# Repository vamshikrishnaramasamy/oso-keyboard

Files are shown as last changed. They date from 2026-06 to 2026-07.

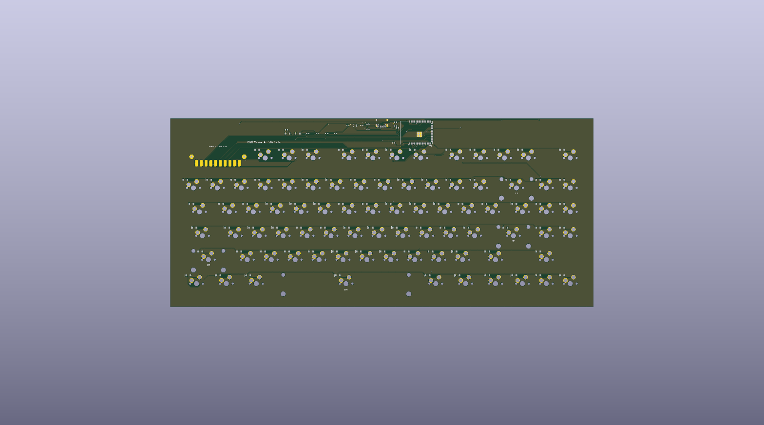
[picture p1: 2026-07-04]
hardware/kicad/oso75/renders/top-handedness-check.png

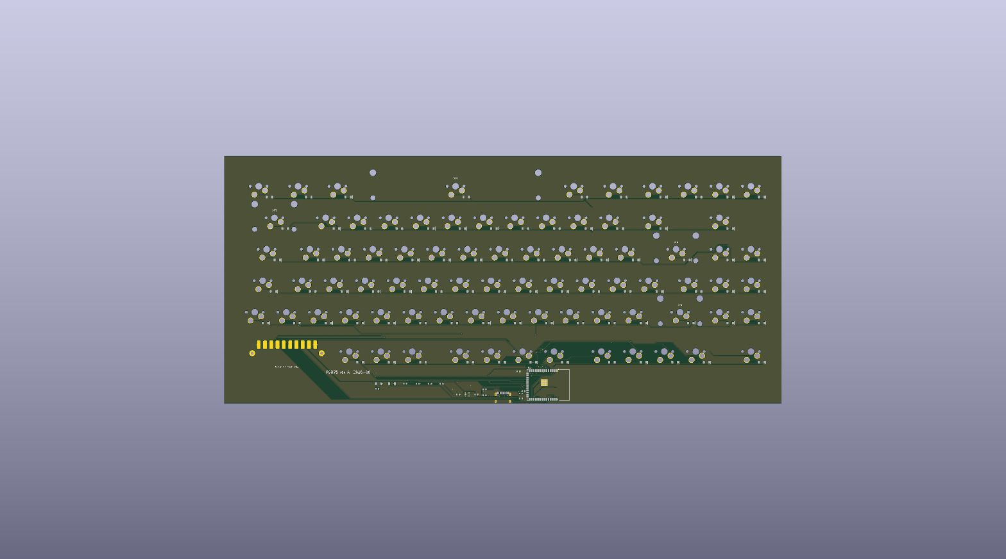
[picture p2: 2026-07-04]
hardware/kicad/oso75/renders/top-orientation-check.png

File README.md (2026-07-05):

# OSO Keyboard

Demo: https://vamshikrishnaramasamy.github.io/oso-keyboard/

Repository/README: https://github.com/vamshikrishnaramasamy/oso-keyboard

OSO Keyboard is an open-source 75% mechanical keyboard project with a custom
ESP32-S3 programmable PCB target, USB/BLE/Wi-Fi firmware plans, and parametric CAD.

Current design target:

- 82-key 75% ANSI layout with a flush hot-swappable OSO module bay
- Onboard ESP32-S3-WROOM-1U module as the main brain
- USB-C
- 10-contact programmable module dock replacing the Esc/F1 corner
- ESP-IDF/TinyUSB wired firmware target, with BLE/Wi-Fi config planned
- MX hotswap switch footprints
- PCB-mounted stabilizers
- Factory-assembled SMD diodes and ESP32-S3 support parts

The project is intentionally source-driven: edit `hardware/layout/oso75.layout.json`,
then run the generator to refresh firmware layout metadata, CAD key positions,
PCB circuit netlists, and the KiCad starting project.

## Quick Start

```sh
npm run generate
npm run validate
```

Generated CAD lives in `hardware/cad/generated/`. The KiCad project lives in
`hardware/kicad/oso75/`.

## Reviewer File Map

PCB source files:

- KiCad project: `hardware/kicad/oso75/oso75.kicad_pro`
- KiCad schematic: `hardware/kicad/oso75/oso75.kicad_sch`
- KiCad PCB: `hardware/kicad/oso75/oso75.kicad_pcb`
- Order-ready Gerbers/BOM/CPL: `hardware/kicad/oso75/fab/`
- Reviewer BOM with purchase links: `hardware/bom.csv`

CAD source and exports:

- Parametric CAD source: `hardware/cad/build123d/oso75_case.py`
- Full assembly render: `hardware/cad/build123d/oso75_preview_exploded.png`
- Full assembly STEP/GLB: `hardware/cad/build123d/oso75_assembly.step` and
  `hardware/cad/build123d/oso75_assembly.glb`
- Split case top: `hardware/cad/build123d/oso75_case_bezel.step/.stl`
- Split case bottom: `hardware/cad/build123d/oso75_case_bottom.step/.stl`
- Switch plate: `hardware/cad/build123d/oso75_plate.step/.stl`
- Module bay cover: `hardware/cad/build123d/oso75_bay_cover.step/.stl`

## Status

This is the first hardware bring-up pass. The layout, firmware skeleton, CAD
plate/case model, ESP32-S3 pin plan, PCB circuit netlists, and KiCad board
starting point are in place.

2026-06-10: a full orientation audit against the proven annovax75 reference
found the PCB was **physically mirrored** (rows y-inverted: a built board would
have had `~` on the right and Enter on the left). The board was y-flipped
(placements mirrored, every footprint rotated 180°, diodes re-seated at the
x-mirrored offset about their switch) and re-routed from scratch. KiCad 10.0.3
reports 0 DRC errors and 0 unconnected items; drill files reconcile exactly.
The CAD model was already correct and is byte-identical across the fix.

**Order only `hardware/kicad/oso75/fab/oso75_order_ready_v2_gerbers.zip`** (plus
`oso75_order_ready_v2_pos.csv` and the BOM CSVs). Anything prefixed
`STALE-MIRRORED-DO-NOT-ORDER-` is the mirrored board and must not be ordered.
See `hardware/kicad/oso75/fab/README_ORDER_READY.md`.

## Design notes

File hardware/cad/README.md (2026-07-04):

# CAD

The production case is the build123d model in `hardware/cad/build123d/`.

Generate it with:

```sh
cd hardware/cad/build123d
python3 oso75_case.py
```

Production outputs:

- `oso75_case_bottom.step/.stl`
- `oso75_case_bezel.step/.stl`
- `oso75_plate.step/.stl`
- `oso75_bay_cover.step/.stl`
- `oso75_assembly.step/.glb`

The older OpenSCAD file in `hardware/cad/generated/oso75_case_plate.scad` is
concept-only. Do not use it for final printing, CNC, or ordering.

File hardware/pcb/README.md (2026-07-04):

# PCB

OSO75 is targeting a custom onboard-ESP32-S3 PCB.

KiCad PCB source files live in `hardware/kicad/oso75/`:

- `oso75.kicad_pro` is the KiCad project.
- `oso75.kicad_sch` is the KiCad schematic.
- `oso75.kicad_pcb` is the routed PCB.
- `fab/oso75_order_ready_v2_gerbers.zip` is the order-ready Gerber package.
- `fab/oso75_order_ready_v2_pos.csv` is the order-ready CPL/position file.
- `fab/oso75_order_ready_bom_no_hotswap.csv` and
  `fab/oso75_order_ready_bom_with_hotswap.csv` are the assembly BOM options.

Generated planning/source files in this folder:

- `esp32s3-pin-plan.md` defines the matrix pins and reserved pins.
- `oso75_placement.csv` is generated placement data for switches and diodes.
- `oso75_matrix_netlist.csv` defines every switch, diode, row net, and column net.
- `oso75_esp32s3_netlist.csv` defines USB-C, power, reset, boot, debug,
  status LED, OSO module bay, and matrix pins.
- `oso75_components.csv` lists footprints, part choices, and factory/builder
  assembly intent.
- `oso75_circuit.md` explains the circuit blocks and routing rules.

The current routed PCB includes:

- ESP32-S3-WROOM-1U module support
- USB-C, ESD, boot, reset, regulator, and external antenna circuitry
- 6 x 16 matrix routing
- 82 MX hotswap sockets
- 82 SOD-123 diodes
- flush top-left OSO module bay for encoder/OLED/slider-style accessories
- PCB-mount stabilizer holes
- ESP-IDF/TinyUSB firmware metadata

Design note: the diodes are still part of the PCB, but the plan is to make them
SMD/factory-assembled so builders do not have to solder 82 tiny parts by hand.

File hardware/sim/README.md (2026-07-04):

# OSO75 ESP32-S3 Simulation

This folder is generated by `npm run simulate:esp32`.

## What runs locally

- ESP32-S3 pin-plan checks against `keyboard.json` and `oso75_esp32s3_netlist.csv`
- COL2ROW switch/diode matrix scan model for all 82 populated keys
- Boot/reset RC sanity model for EN and GPIO0
- USB/power budget estimates for AP2112K, USB 500 mA budget, and F1 500 mA hold current
- Compute/memory budget estimates for 1 kHz matrix scanning on dual-core 240 MHz ESP32-S3

## What needs external tools

Real ESP32 firmware CPU emulation needs ESP-IDF QEMU or Wokwi CLI. This machine currently has neither installed.

Espressif QEMU route:

```sh
brew install libgcrypt glib pixman sdl2 libslirp
python "$IDF_PATH/tools/idf_tools.py" install qemu-xtensa qemu-riscv32
. "$IDF_PATH/export.sh"
idf.py qemu monitor
```

Wokwi route:

```sh
wokwi-cli --timeout 10000 hardware/sim/wokwi
```

Generated Wokwi project:

- `hardware/sim/wokwi/diagram.json`
- `hardware/sim/wokwi/sketch.ino`

Note: Wokwi simulates the ESP32-S3 board and interactive buttons. The local JS sim is the source of truth for the diode matrix, power, and compute limits because it is derived directly from the repo's PCB/netlist artifacts.

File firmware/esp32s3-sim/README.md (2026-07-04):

# OSO75 ESP32-S3 Firmware Sim

This is a tiny ESP-IDF target for exercising the OSO75 ESP32-S3 pin plan on a
real ESP32-S3 build toolchain. It configures the same matrix pins as the PCB,
runs a deterministic COL2ROW matrix scan, and prints CPU/heap/timing stats.

Build it from the repo root:

```sh
npm run firmware:esp32s3:build
```

Run under Espressif QEMU when the selected IDF/QEMU target supports ESP32-S3:

```sh
npm run firmware:esp32s3:qemu
```

For full board/circuit validation, run the repo-level system sim too:

```sh
npm run simulate:esp32
npm run simulate:system:strict
```

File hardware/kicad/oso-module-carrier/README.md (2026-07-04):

# OSO Module Carrier (XIAO + Qwiic)

The first OSO module: a 54 x 25 mm carrier for the OSO75 bay that makes
the whole Qwiic/STEMMA-QT ecosystem — and optionally a whole second
ESP32 — pluggable into the keyboard. DRC-clean, fully routed
(`fab/oso_module_carrier_gerbers.zip`).

Two personalities on one PCB:

| Mode | Fit | JP1/JP2 (I2C bridge) | JP3 (5 V) |
|---|---|---|---|
| Dumb Qwiic adapter (default) | no XIAO | bridged (factory default) | open |
| Smart module | XIAO ESP32-S3 in U2/U3 | **cut** | close to power XIAO from bay |

- **Dumb mode**: the keyboard's ESP32-S3 drives any Qwiic device plugged
  into J1/J2 over the bay I2C (GPIO41/42). Zero firmware on the module.
- **Smart mode**: the XIAO owns the Qwiic (device) bus on D2/D3 and talks
  to the keyboard over the bay (link) bus on D4/D5 as an I2C peripheral;
  MOD_INT (keyboard GPIO47 / XIAO D1) is the attention line. The XIAO's
  USB-C faces up through the bay for reflashing. MOD_A/B also land on
  D0/D6 as spare link lines.

## Parts

| Ref | Part |
|---|---|
| MOD1 | ten 2.2 x 5.0 bottom pads (3.8 mm pitch) at the keyboard J3 pad positions — solder **Mill-Max 0965-0-15-20-80-14-11-0** SMT spring pins here (2.79 mm extended, ~2.5 mm at rated mid-stroke, 2 A) |
| U2/U3 | 1x7 2.54 mm SMD socket strips (XIAO ESP32-S3 seat) |
| J1/J2 | JST SH 4-pin (SM04B-SRSS-TB) = Qwiic / STEMMA-QT |
| J4 | 1x4 pin header: 3V3 / GND / MOD_A / MOD_B (encoders, raw GPIO) |
| JP1/JP2 | solder jumpers: bay I2C <-> Qwiic bus (bridged by default) |
| JP3 | solder jumper: bay fused 5 V -> XIAO 5 V pin (open by default) |
| C1/C2 | 100 nF + 10 uF 0603 on 3V3 |
| R1 | 10 k 0603, MOD_INT -> GND (module-present strap) |

Retention: Ø3.6 NPTH at ±21 mm, matching the bay's holes. ESP_EN from
the bay lands on contact 9 (unrouted on the carrier by design).

**Polarization**: the back-left corner has a 5 mm chamfer and the case
plate's bay opening a matching 2.2 mm corner key — the module physically
cannot be inserted 180° rotated (which would land 5 V/EN on the I2C
contacts). Cross-board mating is machine-verified: every contact pad's
position, size and net function is checked against the keyboard's J3 by
`verify_carrier.py` (87 checks).

## Regenerating

`generate_carrier.py` (run under KiCad's bundled python) rebuilds
placement/nets/zones from scratch; route with
`java -jar tools/freerouting/freerouting.jar -de oso_module_carrier.dsn
-do oso_module_carrier.ses -mp 10` and apply with `import_ses.py`
(pcbnew's own SES import returns False headless on this machine).
Note: regenerating discards the routed tracks and the hand-placed GND
stitch at J2 — re-run the route + import steps after.

See `docs/oso-module-spec.md` for the full bay interface contract.

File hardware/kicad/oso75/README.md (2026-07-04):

# OSO75 KiCad Project

Generated from `hardware/layout/oso75.layout.json` and the PCB circuit netlists,
then hand-finished for fabrication. **Do not re-run `scripts/generate-kicad.mjs`
over this board** - it would clobber the routing and the real footprints below.

Open `oso75.kicad_pro` in KiCad 10. The board contains:

- 82 Kailh MX hotswap switch footprints (cloned from the proven annovax75
  reference board: 3.05 mm plated contact holes, 4.0 mm center / 1.75 mm
  fixation NPTH, F.Cu SMD socket pads); Esc and F1 are replaced by the module bay
- 82 SOD-123 diode footprints, 6 x 16 COL2ROW matrix
- ESP32-S3-WROOM-1U-N16 module with native USB and an external IPEX/u.FL
  antenna connector. Do not substitute N16R8/R16V/Octal-PSRAM variants;
  GPIO35/GPIO36/GPIO37 are used by the key matrix.
- USB-C receptacle `Connector_USB:USB_C_Receptacle_HRO_TYPE-C-31-M-12` (J1)
  from the official KiCad library, shield pads solid-connected to GND
- Cherry PCB-mount stabilizer holes (3.048 / 3.988 mm NPTH) for Backspace,
  Enter, LShift (2u wires) and Space (6.25u)
- Flush top-left J3 OSO module bay with 10 contacts and two retention holes.
  Rev A is power-off swappable only; do not live-swap powered modules.
- F1 fused 5 V module rail, R10 module-present pullup, LDO, CC pulldowns,
  USB series resistors, boot/reset, strapping support
- Board outline 337.088 mm x 150.063 mm; GND pours on both copper layers
  with stitching vias

## Status: y-flipped, re-routed, DRC error-clean, ready for prototype fab review

2026-06-10 (evening): **the board was physically mirrored** - all previous
passes (including the Oracle audit) had the rows y-inverted relative to the
proven annovax75 convention, so a built board would have had `~` on the right
and Enter on the left. Fixed by mirroring every footprint placement about the
horizontal centerline (y -> 150.063 - y, each part rotated 180 deg so
y-asymmetric features land correctly; parts are physical and cannot be
mirrored), repositioning each diode at the x-mirrored offset about its own
switch (restores the proven pad clearances), and re-routing from scratch.
The KiCad canvas now reads like a normal keyboard: USB/ESP32 band and the
J3 bay at the top-left, F-row beneath, space row at the bottom.
Current package: `fab/oso75_order_ready_v2_gerbers.zip`; everything prefixed
`STALE-MIRRORED-DO-NOT-ORDER-` is the mirrored board and must not be ordered.

- Oracle review found blocking electrical issues in the previous pass; those
  are fixed in the checked-in board.
- U1 is locked to ESP32-S3-WROOM-1U-N16. Do not substitute N16R8/R16V or other
  Octal-PSRAM ESP32-S3 variants because GPIO35/GPIO36/GPIO37 are matrix columns.
- U3 is wired as:
  pin 1 VIN=VBUS, pin 2 GND, pin 3 EN=VBUS, pin 4 NC, pin 5 VOUT=+3V3.
- Added GND stitching vias to clear isolated F.Cu pour islands created by the
  regulator-area reroute.
- KiCad 10.0.3 DRC after the y-flip and re-route: 0 errors, 0 unconnected
  items, 187 library-lookup warnings only (`drc-yflip-12.json`).
- Current fab package: `fab/oso75_order_ready_v2_gerbers.zip` with
  `oso75_order_ready_v2_pos.csv`. Upload after a final Gerber-viewer check.
- All prior fab packages are the mirrored board and must not be ordered.
- Drill sanity-checked: 164x 3.05 PTH switch contacts, 164x 1.75 NPTH
  fixation, 82x 4.0 NPTH centers, 8x 3.048 + 8x 3.988 NPTH stab holes
- 2-layer, 1.6 mm FR-4, 1 oz; min track/clearance 0.2 mm, vias 0.6/0.3 mm
- Copper-to-edge clearance is set to 0.35 mm (JLCPCB/PCBWay accept >= 0.3)
  because the USB corridor cannot satisfy 0.5 mm
- J3 is exposed ENIG contact copper only: no paste, no BOM line, and no pick
  and place entry. Removable modules must provide the spring/contact side.

## How it was routed

Full-board autoroute with freerouting v2.2.4 (`tools/freerouting/freerouting.jar`):
strip all tracks, `ExportSpecctraDSN` -> `oso75_clean.dsn`, route, import
`oso75.ses`, refill zones (`post_route.py`), widen power nets where clearance
allows (`widen_power.py`), then DRC to zero. Two stubborn matrix links and the
post-layout-fix stitches were routed by the local grid-A* scripts
(`route_two.py`, `route_col9_astar.py`, `route_missing.py`); GND pour islands
got stitching vias (`stitch_islands.py`).

Gotchas discovered (kept for the next pass):

- freerouting v2.2.4 hangs at "Opening..." if the DSN contains existing
  wiring - always strip tracks and route from scratch. It can also hang
  *after* "session completed" without writing the .ses; kill and re-run.
- `pcbnew.LoadBoard` returns None unless the path ends in `.kicad_pcb`.
- The original generator switch footprints were placeholders with no real
  MX contact pads - they were replaced wholesale (see `move_sw72.py`,
  git history) and PrtSc was moved to the nav column (layout bug, 0.75u
  keycap overlap with F12).

2026-06-10: the rear electronics band was shrunk from 45 mm to 22 mm deep
(board 173.063 -> 150.063 mm tall, `rearElectronicsHeight` 36 -> 13 in the
generator/validator). U1 is now the external-antenna WROOM-1U-N16 module, so
there is no PCB antenna area on the keyboard PCB. USB/LDO/passives were
repacked, stabilizer footprints were added, and the board was fully re-routed.

Pre-route and pre-move backups: `oso75.kicad_pcb.bak`,
`oso75.kicad_pcb.pre-sw72`, `oso75.kicad_pcb.pre-shrink` (173 mm board).

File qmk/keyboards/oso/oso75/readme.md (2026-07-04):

# OSO75 Legacy QMK Layout Reference

Generated layout skeleton for the OSO75 key matrix.

The active PCB target is ESP32-S3, so production firmware is expected to move to
ESP-IDF/TinyUSB. This QMK folder remains useful as a readable layout/keymap
reference while the ESP32 firmware comes up.

```sh
qmk compile -kb oso/oso75 -km default
```

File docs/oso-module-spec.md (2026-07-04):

# OSO Module Developer Spec (Rev A)

How to build a module for the OSO75's hot-swap bay — and how to make
*any* ESP32-compatible peripheral work in it.

## The big picture

The bay is a **3.3 V I2C + GPIO dock** wired straight to the keyboard's
ESP32-S3. There is no connector on the keyboard side: the board exposes
ten ENIG gold contact pads plus two retention holes, and the **module
carries the spring contacts** (pogo pins). Anything that talks I2C — which
is most of the ESP32 peripheral ecosystem: OLEDs, sensors, IO expanders,
LED drivers, touch controllers — can be a module. Rotary encoders and
other 2-wire devices use the dedicated GPIO pair instead.

Rev A is **power-off swap only**. Unplug the keyboard before inserting or
removing a module.

## Electrical interface (J3, verified against routed copper)

| Pin | Net | ESP32-S3 side | Use |
|---:|---|---|---|
| 1 | GND | — | Ground |
| 2 | +3V3 | LDO rail | Main module power |
| 3 | VBUS_FUSED | fused 5 V | Optional, for LEDs (about 300-350 mA continuous bus-powered budget) |
| 4 | I2C_SDA | GPIO41 | I2C data |
| 5 | I2C_SCL | GPIO42 | I2C clock |
| 6 | MOD_A | GPIO39 | Encoder A / free GPIO |
| 7 | MOD_B | GPIO40 | Encoder B / free GPIO |
| 8 | MOD_INT | GPIO47 | Interrupt / module-present detect |
| 9 | ESP_EN | EN | Module-side reset (use with care) |
| 10 | GND | — | Ground |

Rules:

- **3.3 V logic only.** The ESP32-S3 is not 5 V tolerant. VBUS_FUSED may
  only feed loads (LEDs, displays' backlight boost), never logic levels.
- I2C pull-ups live on the keyboard PCB; do not add strong pull-ups on
  the module (weak 10 k extras are tolerable).
- **MOD_INT doubles as presence detect**: tie it to GND through 10 k on
  the module if you don't need an interrupt, or drive it open-drain if
  you do. Firmware reads "low at boot = module present."
- Total continuous 3V3 draw ≤ 80 mA on rev A; total continuous VBUS_FUSED draw ≤ 300-350 mA on bus power. F1 has a 500 mA hold current, but the keyboard electronics share the USB current budget.

## Mechanical interface (from the routed board, J3 at canvas 38.0, 30.5)

- Bay opening through the plate: **54.6 × 25.6 mm**; module PCB max
  **54.0 × 25.0 mm**, 1.6 mm thick, corners R ≤ 2 mm.
- Contact pads on the keyboard: ten **2.2 × 5.0 mm** pads on a **3.8 mm
  pitch**, in one row, centers at y = +5.2 mm from bay center, pad 1 at
  x = +17.1 mm running to pad 10 at x = −17.1 mm (J3 is placed rotated
  180°, so pad 1 is toward the board's left edge — copy the footprint
  `OSO75.pretty` J3 rather than re-deriving).
- Retention: two **Ø3.6 mm NPTH** at x = ±21.0 mm, y = 0 — use snap
  posts or M3 shoulder screws from the module side.
- **Polarization (required)**: chamfer the module PCB's back-left corner
  5 mm at 45°. The plate opening carries a 2.2 mm corner key there, so an
  unchamfered or wrongly-oriented module will not seat — protecting the
  I2C pins from the 5 V/EN contacts.
- Contacts: **Mill-Max 0965** SMT spring pins (2.79 mm extended, ~2.5 mm
  at rated mid-stroke, 2 A each) soldered to the module's bottom pads.
- Use **spring-loaded (pogo) contacts ≥ 1 mm travel** on the module
  underside, mirrored to the pad row. Recommended: Mill-Max 855/0965
  series or a 10-pin pogo block on 3.8 mm pitch.
- Height budget above the plate: keep the module ≤ 9 mm proud (keycap
  top is ~9.5 mm above the plate) so it doesn't dominate the board.
- When no module is fitted, the printed **bay blank**
  (`hardware/cad/build123d/oso75_bay_cover.stl`) snaps into the opening.

## Making "everything ESP32-compatible" work: the adapter module

You don't need a custom PCB per peripheral. Build (or buy the design of)
one **Qwiic/STEMMA-QT adapter module**: a 54 × 25 bay PCB with pogo
contacts on the bottom and one or two **JST-SH 4-pin Qwiic connectors**
on top, wiring 3V3/GND/SDA/SCL straight through.

**This board exists**: `hardware/kicad/oso-module-carrier/` — DRC-clean,
routed, gerbers in `fab/`. It also carries an optional XIAO ESP32-S3
socket, turning it into a self-contained smart module (own firmware, own
USB-C through the bay) with the bay I2C as the keyboard link; solder
jumpers select the mode. See its README.

That one adapter makes the entire Qwiic/STEMMA-QT catalog — hundreds of
SparkFun/Adafruit boards: OLED and e-ink displays, IMUs, environmental
sensors, GPS, NFC, keypads, haptics — plug into the keyboard with zero
soldering, because they're all 3.3 V I2C with on-board addresses, exactly
what the bay speaks. Encoder/analog peripherals use a second adapter
variant that breaks MOD_A/MOD_B out to a header.

## Firmware contract

- Bus: I2C0 on GPIO41/42 at 400 kHz, 3.3 V.
- At boot (and on MOD_INT edge), firmware scans the bus and matches known
  addresses (e.g. 0x3C SSD1306 OLED, 0x76/0x77 BME280, ...) to enable the
  right driver; unknown modules still get raw I2C via host commands.
- Encoders on MOD_A/MOD_B use the QMK encoder driver; MOD_INT is the
  shared interrupt line.
- Modules must tolerate an undriven bus (keyboard in deep sleep for BLE).

## Checklist for a new module

1. Start from the J3 footprint in `hardware/kicad/oso75/OSO75.pretty`.
2. 54 × 25 × 1.6 PCB, pogo pins mirrored to the pad row, posts at ±21.
3. 3.3 V logic, I2C device(s) with non-conflicting addresses.
4. MOD_INT strap for presence detect.
5. Stay under 80 mA continuous on 3V3 / 300-350 mA continuous on VBUS_FUSED for rev A bus power.
6. Power off to swap (Rev A).

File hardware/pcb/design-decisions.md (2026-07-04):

# PCB Design Decisions

## Decision: Custom Programmable PCB

OSO75 will use a custom PCB instead of relying on an existing YMD75-style PCB.

Reasons:

- Better open-source hardware story for Stardance.
- We control the layout, pinout, silkscreen, and future variants.
- Onboard ESP32-S3 gives native USB plus BLE/Wi-Fi for the module ecosystem.
- SMD diodes and ESP32-S3 support components can be factory assembled.
- Builders should only need to install switches, stabilizers, and case hardware.

## Decision: Top-Left Hot-Swappable Module Bay

OSO75 includes a flush top-left accessory bay as the signature customizable feature.
The bay is meant for small user-created modules that can be swapped without
redesigning the whole keyboard: a volume knob, OLED display, slider, macro
display, sensor board, or other programmable widget.

The base keyboard exposes power plus a small general-purpose interface through a
keyed 10-contact dock. The default pinout reserves I2C for displays/sensors,
two GPIOs for a rotary encoder, one interrupt/module-present pin, reset, 3.3 V,
optional fused 5 V, and ground.

Mechanical intent:

- A visible top-left recessed pocket inside the normal keyboard outline, not a
  protruding tab or full-width empty strip.
- Two small retention/mounting holes for module plates or screws.
- A 10-contact pad strip for pogo pins or a low-profile board-to-board connector.
- Modules should be independently open-source and printable/fabbable.

## Reference Backup

The YMD75v3 / 75V3 QMK hotswap PCB remains a good backup reference because it is
already programmable and has sockets/diodes populated. It is not the primary OSO75
hardware target.

## First PCB Scope

The first KiCad pass should include:

- ESP32-S3-WROOM-1U module, regulator, USB-C, ESD, boot, reset, and external antenna.
- 6 x 16 COL2ROW keyboard matrix.
- 82 MX hotswap sockets.
- 82 SOD-123 diodes.
- Top-left OSO module bay connector, 10 exposed contacts, retention holes, and mechanical keepout.
- PCB-mount stabilizer holes.
- Mounting holes aligned to the generated case.
- Clear silkscreen labels for rows, columns, and switch positions.

## Manufacturing Target

Use JLCPCB or PCBWay for the first custom PCB run. AliExpress is fine for switches,
stabilizers, screws, and other builder-installed parts, but custom PCBs are better
ordered from an actual PCB fab.

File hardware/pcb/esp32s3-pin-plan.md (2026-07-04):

# OSO75 ESP32-S3 Pin Plan

The custom PCB target uses an onboard ESP32-S3-WROOM-1U-N16 module and a 6 x 16
keyboard matrix. GPIO19/GPIO20 stay reserved for native USB so the computer plugs
directly into the ESP32-S3. Use an external 2.4 GHz IPEX/u.FL antenna for BLE/Wi-Fi.

## Matrix

| Signal | Pins |
|---|---|
| Rows | GPIO1, GPIO2, GPIO4, GPIO5, GPIO6, GPIO7 |
| Columns | GPIO8, GPIO9, GPIO10, GPIO11, GPIO12, GPIO13, GPIO14, GPIO15, GPIO16, GPIO17, GPIO18, GPIO21, GPIO35, GPIO36, GPIO37, GPIO38 |
| Diode direction | COL2ROW |
| Per-key wiring | COLn -> switch -> diode anode -> diode cathode -> ROWm |
| Diode footprint | Pad 1 is cathode/ROW side; pad 2 is anode/switch side |
| Module bay replaced positions | Esc, F1 |

GPIO35/GPIO36/GPIO37 are not available on Octal-PSRAM ESP32-S3-WROOM-1U variants,
so do not substitute an N16R8/R16V module without rerouting COL12-COL14.

## Reserved Pins

| Purpose | Pin |
|---|---|
| USB D- / D+ | GPIO19 / GPIO20 |
| Boot/download | GPIO0, pulled up; BOOT switch pulls low |
| Reset/enable | EN, pulled up; RESET switch pulls low |
| OSO module interrupt/present | GPIO47 |
| OSO module encoder/GPIO | GPIO39 / GPIO40 |
| OSO module I2C | GPIO41 / GPIO42 |
| Avoid for matrix | GPIO0, GPIO3, GPIO19, GPIO20, GPIO45, GPIO46 |

## OSO Module Bay

| Pin | Net | Use |
|---:|---|---|
| 1 | GND | Ground |
| 2 | +3V3 | Main module power |
| 3 | VBUS_FUSED | Optional 5 V input for LEDs, through fuse/current limit |
| 4 | I2C_SDA / GPIO41 | OLED/sensor data |
| 5 | I2C_SCL / GPIO42 | OLED/sensor clock |
| 6 | MOD_A / GPIO39 | Encoder A / GPIO / SPI option |
| 7 | MOD_B / GPIO40 | Encoder B / GPIO / SPI option |
| 8 | MOD_INT / GPIO47 | Interrupt, button, or module-present detect |
| 9 | ESP_EN | Optional module reset/programming signal |
| 10 | GND | Ground / shield |

Keep modules 3.3 V logic by default. Any 5 V LED module should include its own
current limiting and should not pull more than the 500 mA hold budget set by F1.
Rev A is power-off swap only. Do not insert or remove modules while powered.

## Assembly Intent

JLCPCB/PCBWay should assemble the ESP32-S3-WROOM-1U-N16 module, USB-C connector, reset/boot buttons, SMD diodes, regulator, fuse,
and passives. Do not allow N16R8/R16V/Octal-PSRAM ESP32-S3 substitutes. J3 is PCB copper only and should be excluded from factory assembly.
Kailh hotswap sockets may be factory assembled or hand-soldered, but the BOM/CPL must match that choice. The builder should only need to install switches,
stabilizers, and case hardware when sockets are factory assembled.

See `oso75_circuit.md`, `oso75_matrix_netlist.csv`, and
`oso75_esp32s3_netlist.csv` for the actual circuit nets.

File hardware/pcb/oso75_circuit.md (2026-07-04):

# OSO75 Circuit Design

This circuit pass makes the ESP32-S3 the main keyboard brain. The computer plugs
into the keyboard's USB-C port, and the ESP32-S3 enumerates as the USB HID
keyboard while also owning BLE, Wi-Fi, and the hot-swappable OSO module bay.

## Electrical Target

- MCU: onboard ESP32-S3-WROOM-1U-N16 module with external IPEX/u.FL antenna connector. Do not substitute N16R8/R16V/Octal-PSRAM variants.
- Firmware: ESP-IDF + TinyUSB first; BLE/Wi-Fi config after wired USB is stable.
- Matrix: 6 rows x 16 columns, 82 populated switch positions.
- Module bay replaces: Esc, F1.
- Diode direction: `COL2ROW`.
- Builder soldering target: switches/stabilizers only. SMD diodes and controller
  support parts should be factory assembled.

## Switch Matrix

Each key uses this net order:

```text
COLn -> switch -> diode anode -> diode cathode -> ROWm
```

The SOD-123 diode footprint intentionally uses pad 1 as the cathode/ROW-side pad.
The cathode band and `K` mark face the ROW net on the assembly drawing.

### Rows

| Net | ESP32-S3 pin | Populated keys |
|---|---|---:|
| ROW0 | U1 GPIO1 | 12 switches |
| ROW1 | U1 GPIO2 | 16 switches |
| ROW2 | U1 GPIO4 | 16 switches |
| ROW3 | U1 GPIO5 | 15 switches |
| ROW4 | U1 GPIO6 | 13 switches |
| ROW5 | U1 GPIO7 | 10 switches |

### Columns

| Net | ESP32-S3 pin | Populated keys |
|---|---|---:|
| COL0 | U1 GPIO8 | 5 switches |
| COL1 | U1 GPIO9 | 5 switches |
| COL2 | U1 GPIO10 | 6 switches |
| COL3 | U1 GPIO11 | 5 switches |
| COL4 | U1 GPIO12 | 5 switches |
| COL5 | U1 GPIO13 | 5 switches |
| COL6 | U1 GPIO14 | 6 switches |
| COL7 | U1 GPIO15 | 5 switches |
| COL8 | U1 GPIO16 | 5 switches |
| COL9 | U1 GPIO17 | 6 switches |
| COL10 | U1 GPIO18 | 6 switches |
| COL11 | U1 GPIO21 | 6 switches |
| COL12 | U1 GPIO35 | 4 switches |
| COL13 | U1 GPIO36 | 4 switches |
| COL14 | U1 GPIO37 | 5 switches |
| COL15 | U1 GPIO38 | 4 switches |

GPIO35/GPIO36/GPIO37 are only valid because the target module is ESP32-S3-WROOM-1U-N16,
not an Octal-PSRAM N16R8/R16V module.

## USB-C And Power

- J1 is a USB-C receptacle wired as a USB 2.0 device.
- CC1 and CC2 each get a 5.1k pulldown to GND.
- D+ and D- route from J1 through 27R series resistors to ESP32-S3 GPIO20/GPIO19 native USB.
- USB ESD protection is not fitted in this routed rev; add a USBLC6-class part during the next USB reroute instead of dropping it into the current crowded fanout.
- VBUS feeds U3, a 3.3 V LDO such as AP2112K-3.3.
- AP2112K pinout: pin 1 VIN=VBUS, pin 2 GND, pin 3 EN=VBUS, pin 4 NC, pin 5 VOUT=+3V3.
- F1 is a Littelfuse 0603L050SLYR 0603 PPTC fuse. It creates a current-limited
  VBUS_FUSED rail for optional 5 V module loads.
- C1 and C2 are 10uF 10V 0603 bulk capacitors at LDO input/output.

## ESP32-S3 Support

- U1 is an ESP32-S3-WROOM-1U module, so flash, crystal, RF matching, and the IPEX antenna connector are inside the module.
- Fit a compatible 2.4 GHz IPEX/u.FL antenna if BLE/Wi-Fi will be used. Wired USB keyboard mode works without the antenna.
- SW_RESET pulls EN low.
- C_EN is 1uF from ESP_EN to GND for the ESP32-S3 EN reset delay.
- SW_BOOT pulls GPIO0 low for ROM download mode.
- GPIO47 routes to the OSO bay as module-present or interrupt.
- GPIO39/GPIO40 route to the OSO bay for encoder/GPIO use.
- GPIO41/GPIO42 route to the OSO bay for I2C OLED/sensor modules.
- GPIO19/GPIO20 are reserved for USB D-/D+ and are not used by the switch matrix.
- Avoid GPIO0, GPIO3, GPIO45, and GPIO46 for ordinary matrix wiring because they affect boot/strapping.

## OSO Module Bay

The keyboard PCB side is exposed ENIG copper pads plus two retention holes, not a
factory-assembled pogo or mezzanine connector. Put the spring contacts on the
removable module side. Rev A is **power-off swap only**: unplug the keyboard
before inserting or removing modules.

| Pin | Net | Use |
|---:|---|---|
| 1 | GND | Ground |
| 2 | +3V3 | Main module power |
| 3 | VBUS_FUSED | Optional 5 V for LEDs/modules |
| 4 | I2C_SDA | OLED/sensor data |
| 5 | I2C_SCL | OLED/sensor clock |
| 6 | MOD_A | Encoder A / GPIO |
| 7 | MOD_B | Encoder B / GPIO |
| 8 | MOD_INT | Interrupt or module-present detect |
| 9 | ESP_EN | Optional module reset/programming signal |
| 10 | GND | Ground |

Keep modules 3.3 V logic by default. Any 5 V LED module should include its own
current limiting and should not pull more than the 500 mA hold budget set by F1.
Do not live-swap rev A modules. A later live-swap revision needs ground-first
contact, keyboard-side signal resistors, GPIO ESD protection, and 3.3 V current
limiting/load switching.

Fab note: J3 is intentional exposed contact copper. Do not place a component, do
not paste/stencil the pads, and use ENIG at minimum; choose hard gold if modules
will be swapped often.

## Layout Rules

- Put J1, R3, and R4 close together at the rear USB port.
- Keep D+/D- short, parallel, and away from the switch matrix where possible.
- Keep the WROOM-1U module body clear of switch/stabilizer mechanical courtyards; wireless RF depends on the external antenna and cable placement, not a PCB antenna area.
- Place 10uF bulk and 100nF local decoupling near the module 3V3 pins.
- Route rows horizontally and columns vertically where possible.
- Put the SOD-123 diode near each hotswap socket; cathode stripe/pad 1 goes to the row net.
- Keep the top-left bay clear for J3, retention holes, and module mechanical fit.
- Use a solid ground fill on both layers, stitched around USB and MCU.

## Generated Files

- `oso75_matrix_netlist.csv`: one switch/diode row per key.
- `oso75_esp32s3_netlist.csv`: MCU module, USB, power, buttons, module bay, and headers.
- `oso75_components.csv`: component list with footprints and assembly intent.
- `oso75_placement.csv`: switch and diode coordinates from the keyboard layout.

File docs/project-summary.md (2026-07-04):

# OSO Keyboard Project Summary

Last updated: 2026-06-09

## Goal

OSO Keyboard is an open-source 75% mechanical keyboard project for Stardance. The current direction is a custom keyboard with an onboard ESP32-S3, USB-C, a real 75% ANSI-style layout, and a hot-swappable programmable module bay in the top-left corner for user-made add-ons like a volume knob, OLED screen, slider, macro pad, or LED widget.

## Current Public Links

- GitHub repository: https://github.com/vamshikrishnaramasamy/oso-keyboard
- Web demo / CAD viewer: https://vamshikrishnaramasamy.github.io/oso-keyboard/

## What We Built So Far

### Repo Structure

The project is now source-driven. The main layout source is:

- `hardware/layout/oso75.layout.json`

Generated outputs are produced with:

```sh
npm run generate
npm run validate
```

The generator currently creates or updates:

- CAD files in `hardware/cad/generated/`
- PCB placement/netlist data in `hardware/pcb/`
- KiCad project files in `hardware/kicad/oso75/`
- QMK-style firmware metadata in `qmk/keyboards/oso/oso75/`
- Web viewer assets in `web/public/models/`

### Web CAD Viewer

We built a Three.js-based browser viewer for the keyboard CAD. It can show the generated case/plate model in the browser and was improved several times because the first OpenSCAD-style render made it hard to see the switch holes.

Improvements made:

- Better lighting and material shading
- More visible switch cutout depth
- More useful camera/orbit controls
- CAD asset sync into the web viewer
- Generated STL support for the browser model

The viewer runs locally with:

```sh
npm run viewer
```

### Keyboard CAD

We created a parametric OpenSCAD model for the 75% keyboard case and plate.

Current CAD files include:

- `hardware/cad/generated/oso75_case_plate.scad`
- `hardware/cad/generated/oso75_case_plate.stl`
- `hardware/cad/generated/oso75_fit_report.json`
- `hardware/cad/generated/oso75_pcb_fit.png`

Major CAD revisions:

- Reworked the layout so it actually resembles a 75% keyboard.
- Mirrored the board after the left/right orientation was wrong.
- Moved the arrow/navigation cluster to the correct side.
- Added a top-left OSO hot-swappable module bay.
- Revised the module bay so it is flush with the case instead of awkwardly sticking out.
- Moved the USB-C opening multiple times, ending with a centered side placement that avoids the module bay better.
- Added a PCB fit visualization to check that the board and case line up.

### OSO Module Bay

The module bay is the main "cool part" of the keyboard. The idea is that the keyboard has a standard top-left dock where people can make their own programmable gadgets.

Planned module examples:

- Rotary volume knob
- OLED status display
- Slider module
- Macro module
- LED/status widget

Current electrical bay concept:

- 10-contact dock
- 3.3V
- Fused VBUS
- GND
- I2C SDA/SCL
- Two GPIO/encoder pins
- Interrupt/present pin
- ESP reset/enable access

The bay replaces the Esc/F1 corner area in the current layout.

## PCB and Electronics

### Main Controller Decision

We switched the design from a generic keyboard controller approach to a custom PCB centered around:

- ESP32-S3-WROOM-1U-N16

Reasoning:

- Native USB support, so the computer can plug directly into the ESP32-S3 over USB-C.
- Wi-Fi and BLE available for future customization.
- More flexible than a basic wired-only microcontroller.
- Good fit for a programmable open-source keyboard with add-on modules.

Important design note: the keyboard should enumerate as a USB HID keyboard through the ESP32-S3 native USB pins, not through a separate USB-to-serial chip.

### Pin Plan

The current matrix target is:

- 6 rows
- 16 columns
- 82 key positions
- COL2ROW diode direction

Current planned ESP32-S3 pins:

- Rows: GPIO1, GPIO2, GPIO4, GPIO5, GPIO6, GPIO7
- Columns: GPIO8, GPIO9, GPIO10, GPIO11, GPIO12, GPIO13, GPIO14, GPIO15, GPIO16, GPIO17, GPIO18, GPIO21, GPIO35, GPIO36, GPIO37, GPIO38
- Native USB: GPIO19 / GPIO20
- Module I2C: GPIO41 / GPIO42
- Module GPIO/encoder: GPIO39 / GPIO40
- Module interrupt/present: GPIO47

Details live in:

- `hardware/pcb/esp32s3-pin-plan.md`

### PCB Files

Current PCB-related files include:

- `hardware/pcb/README.md`
- `hardware/pcb/esp32s3-pin-plan.md`
- `hardware/pcb/oso75_circuit.md`
- `hardware/pcb/oso75_components.csv`
- `hardware/pcb/oso75_matrix_netlist.csv`
- `hardware/pcb/oso75_esp32s3_netlist.csv`
- `hardware/pcb/oso75_placement.csv`
- `hardware/kicad/oso75/oso75.kicad_pro`
- `hardware/kicad/oso75/oso75.kicad_sch`
- `hardware/kicad/oso75/oso75.kicad_pcb`

### KiCad Status

KiCad is installed locally and the project has a generated KiCad starting point. The KiCad CLI was found at:

```sh
/Applications/KiCad/KiCad.app/Contents/MacOS/kicad-cli
```

KiCad version checked:

```text
10.0.3
```

We generated a board with:

- ESP32-S3-WROOM-1 footprint
- USB-C connector area
- Matrix switch/diode positions
- Module bay footprint area
- Initial board outline matching the CAD intent
- Render/export support

**Update 2026-06-09: the PCB was routed, but later review found blocker bugs.**

- All 82 generator placeholder switch footprints were replaced with the proven Kailh MX hotswap footprint from the annovax75 reference (real 3.05 mm plated contact holes + socket pads); the USB-C connector was replaced with the official KiCad library `USB_C_Receptacle_HRO_TYPE-C-31-M-12`.
- PrtSc was moved to the right nav column (layout bug: it overlapped F12 by 0.25u). Fixed in `oso75.layout.json` and on the board.
- Cherry PCB-mount stabilizer holes added (Backspace, Enter, LShift, Space).
- ESP32-S3 external antenna rule area added on both copper layers.
- Full board routed (freerouting + local A* scripts), GND pours both layers with stitching vias.
- Previous DRC/fab exports are stale after the Oracle review.
- Important: normal `npm run generate` no longer runs `scripts/generate-kicad.mjs`;
  the KiCad starter generator is explicit as `npm run generate:kicad:starter`.

**Update 2026-06-10: rear electronics band shrunk 173 -> 150 mm.**

- The back band behind the F-row was 45 mm deep; cut to 22 mm (`rearElectronicsHeight` 36 -> 13 in `scripts/generate.mjs`/`validate.mjs`).
- ESP32-S3 rotated horizontal with the antenna facing east into a fresh both-layer keepout; USB-C, LDO, fuse, buttons, and passives repacked into the band.
- Whole board was re-routed (freerouting + A* finishing), but the Oracle audit
  later found ESP32 module and regulator pinout blockers.
- Case/plate CAD regenerated to the same 150.063 mm height.

**Update 2026-06-10: Oracle PCB bugs fixed.**

- U1 retargeted from ESP32-S3-WROOM-1U-N16R8 to ESP32-S3-WROOM-1U-N16 so
  GPIO35/GPIO36/GPIO37 can legally remain COL12-COL14.
- U3 AP2112K pad nets and local copper fixed: VIN/EN on VBUS, NC floating,
  VOUT on +3V3.
- `npm run generate` no longer runs `scripts/generate-kicad.mjs`; KiCad starter
  regeneration is explicit via `npm run generate:kicad:starter`.
- KiCad 10.0.3 DRC after refill: 0 errors, 0 unconnected items, 276 warnings.

## Hardware Parts Direction

We moved toward factory assembly for the annoying tiny parts, especially the diodes, so the builder does not have to hand-solder 82 SMD diodes.

Planned factory-assembled PCB parts:

- ESP32-S3-WROOM-1U-N16
- USB-C receptacle
- SMD matrix diodes
- Reset and boot buttons
- Voltage regulator / power support
- USB-C CC resistors
- Module bay dock
- Protection/current-limiting parts
- Required passives

Builder-installed parts:

- MX switches
- Keycaps
- Stabilizers
- Case/plate hardware
- Optional module bay accessories
- USB-C cable

Parts notes live in:

- `hardware/bom.md`
- `hardware/pcb/oso75_components.csv`

## PCB Manufacturing / Quote Work

We looked at PCB fabrication options and started filling PCBWay quote settings.

Final board dimensions for quoting (from Edge.Cuts):

- 337.088 mm x 150.063 mm

Settings to use when re-quoting (the earlier ~$170 quote was for 4 layers at 320x135 - re-quote!):

- **2 layers** (the routed board is 2-layer)
- FR-4
- 1.6 mm thickness
- 1 oz copper
- Lead-free HASL surface finish
- Green solder mask
- White silkscreen
- No stencil
- Min track/clearance 0.2 mm, min via 0.6/0.3 mm, copper-to-edge 0.35 mm

PCBWay showed a high prototype price for 5 boards, roughly around:

- PCB cost: about $140
- Shipping: about $30
- Total: about $170

Important: no final Gerbers should be ordered yet. The current KiCad board still needs routing and DRC cleanup.

Also important: during quote testing, an unpaid PCBWay draft/cart item was created without uploaded Gerbers. It should not be treated as a real production order.

## Existing 75% Board Reference

We pulled in an existing 75% keyboard PCB/CAD reference to compare against our dimensions, layout, and fit:

- `references/existing-75-cad/annovax75/PCB/keyboard.kicad_pcb`

We used it as a sanity check for:

- Overall 75% proportions
- Layout orientation
- USB placement concerns
- Case/PCB fit expectations

## Firmware Direction

The repo currently has a QMK-style skeleton, but the ESP32-S3 direction means the real firmware path should likely move toward:

- ESP-IDF
- TinyUSB HID keyboard support
- Matrix scanner
- Module bay driver layer
- Optional BLE support later
- Optional Wi-Fi configuration layer later

Current firmware skeleton:

- `qmk/keyboards/oso/oso75/`

This is useful as metadata/reference, but the final ESP32-S3 firmware still needs to be implemented and compiled.

## Stardance / Hackatime Work

We also worked through Stardance setup questions around:

- How Hackatime tracks activity
- How Stardance uses logged project time
- Why the account still showed 0 stardust before linked/eligible project time was visible
- How to send Hackatime heartbeats from the CLI
- How to install/setup the Hackatime extension in Antigravity/VS Code

Key rule learned: Hackatime counts editor/activity heartbeats from actual working tools. It should not be spoofed or artificially inflated, but legitimate coding/research/documentation work in the project can be tracked if Hackatime is configured and heartbeats are being sent correctly.

## Slack Bot / Nest Side Quest

There was also a separate Stardance mission side quest for a Slack bot.

What happened:

- Created/edited a Stardance project for a Slack bot.
- Tried to get a Slack slash command working.
- Hit `invalid_service` errors.
- Realized the mission expected deployment on Hack Club Nest.
- Applied for Nest.
- Nest account was approved.

Nest login info from the approval email:

```sh
ssh vamshikrishnaramasamy@hackclub.app
```

That work is mostly separate from OSO Keyboard, but it happened during the same Stardance setup period.

## Current Status

Working / useful now:

- Repo structure
- Source layout
- Generators
- Validation script
- CAD model
- Web CAD viewer
- KiCad project starting point
- ESP32-S3 pin plan
- BOM direction
- PCB quote research
- Existing board reference comparison

Done since (2026-06-09):

- Final KiCad routing (freerouting + scripted A* finishing)
- Fresh DRC after Oracle fixes
- Real switch/USB-C footprints, stabilizer holes, external antenna
- Gerber/drill/position export (`hardware/kicad/oso75/fab/`)

Not done yet:

- PCB order
- ESP32-S3 firmware compile
- Real hardware test
- Module bay electrical validation
- Final case/plate mechanical validation

## Next Steps

Recommended next steps:

1. Finish KiCad routing manually or with a controlled autorouter pass.
2. Run KiCad ERC and DRC until there are no real electrical/manufacturing errors.
3. Re-check USB-C placement against the module bay and case wall.
4. Generate final Gerbers and drill files.
5. Upload Gerbers to JLCPCB and PCBWay for real quotes.
6. Decide whether the first prototype should be bare PCB only or PCB assembly.
7. Build a minimal ESP-IDF/TinyUSB keyboard firmware.
8. Test the CAD model with a real 75% plate/PCB outline before ordering.
9. Make a Stardance devlog with screenshots of the CAD viewer, PCB, and design decisions.

## Honest Risk List

- A custom ESP32-S3 keyboard PCB is possible, but it is more complex than using an existing keyboard MCU board.
- USB-C routing and ESP32-S3 boot/reset/power circuitry need careful KiCad verification.
- The OSO module bay is custom and needs mechanical/electrical testing before anyone should rely on it.
- The current PCB should be treated as an engineering prototype, not a finished production design.
- Ordering before DRC/ERC cleanup could waste money.

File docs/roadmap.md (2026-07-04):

# Roadmap

## Done

- 82-key 75% layout source with the OSO module bay replacing Esc/F1.
- Generator for firmware metadata, CAD, BOM, and placement data.
- Legacy QMK layout skeleton.
- ESP32-S3 matrix pin plan.
- OpenSCAD tray case and switch plate.
- OpenSCAD render sanity check.

## Next

- Build KiCad schematic from the ESP32-S3-WROOM module design.
- Import switch/diode placement into KiCad PCB.
- Add USB-C opening and mounting boss alignment to CAD.
- Create a VIA JSON definition.
- Make first wired USB HID firmware compile with ESP-IDF/TinyUSB.
- Export Gerbers and assembly files.

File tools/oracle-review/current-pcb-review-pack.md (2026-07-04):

# OSO75 current PCB extracted review pack

Generated from actual `hardware/kicad/oso75/oso75.kicad_pcb` after Oracle fixes. Units mm.

## DRC summary

KiCad 10.0.3; violations 276; unconnected 0.

```json
{
  "via_dangling": 2,
  "courtyards_overlap": 2,
  "npth_inside_courtyard": 2,
  "pth_inside_courtyard": 1,
  "silk_edge_clearance": 2,
  "lib_footprint_issues": 184,
  "lib_footprint_mismatch": 1,
  "silk_over_copper": 82
}
```

## Board-critical footprints

### C1 10uF OSO75:C_0603 at 152.5,144.5 rot 0
- pad 1: at -0.8 0; size 0.8 0.9; drill ; layers "F.Cu" "F.Mask" "F.Paste"; net VBUS; zone_connect 
- pad 2: at 0.8 0; size 0.8 0.9; drill ; layers "F.Cu" "F.Mask" "F.Paste"; net GND; zone_connect 2

### C2 10uF OSO75:C_0603 at 141.5,144.5 rot 0
- pad 1: at -0.8 0; size 0.8 0.9; drill ; layers "F.Cu" "F.Mask" "F.Paste"; net +3V3; zone_connect 
- pad 2: at 0.8 0; size 0.8 0.9; drill ; layers "F.Cu" "F.Mask" "F.Paste"; net GND; zone_connect 

### C3 100nF OSO75:C_0603 at 178,130.5 rot 0
- pad 1: at -0.8 0; size 0.8 0.9; drill ; layers "F.Cu" "F.Mask" "F.Paste"; net +3V3; zone_connect 
- pad 2: at 0.8 0; size 0.8 0.9; drill ; layers "F.Cu" "F.Mask" "F.Paste"; net GND; zone_connect 2

### C4 100nF OSO75:C_0603 at 181,142.5 rot 0
- pad 1: at -0.8 0; size 0.8 0.9; drill ; layers "F.Cu" "F.Mask" "F.Paste"; net +3V3; zone_connect 
- pad 2: at 0.8 0; size 0.8 0.9; drill ; layers "F.Cu" "F.Mask" "F.Paste"; net GND; zone_connect 2

### F1 500mA OSO75:Polyfuse_1206 at 117,138 rot 0
- pad 1: at -0.8 0; size 0.8 0.9; drill ; layers "F.Cu" "F.Mask" "F.Paste"; net VBUS; zone_connect 
- pad 2: at 0.8 0; size 0.8 0.9; drill ; layers "F.Cu" "F.Mask" "F.Paste"; net VBUS_FUSED; zone_connect 

### J1 USB_C_HRO_TYPE-C-31-M-12 Connector_USB:USB_C_Receptacle_HRO_TYPE-C-31-M-12 at 168.54,147.66 rot 0
- pad A1: at -3.25 -4.045; size 0.6 1.45; drill ; layers "F.Cu" "F.Mask" "F.Paste"; net GND; zone_connect 2
- pad A4: at -2.45 -4.045; size 0.6 1.45; drill ; layers "F.Cu" "F.Mask" "F.Paste"; net VBUS; zone_connect 
- pad A5: at -1.25 -4.045; size 0.3 1.45; drill ; layers "F.Cu" "F.Mask" "F.Paste"; net USB_CC1; zone_connect 
- pad A6: at -0.25 -4.045; size 0.3 1.45; drill ; layers "F.Cu" "F.Mask" "F.Paste"; net USB_DP_CONN; zone_connect 
- pad A7: at 0.25 -4.045; size 0.3 1.45; drill ; layers "F.Cu" "F.Mask" "F.Paste"; net USB_DM_CONN; zone_connect 
- pad A8: at 1.25 -4.045; size 0.3 1.45; drill ; layers "F.Cu" "F.Mask" "F.Paste"; net ; zone_connect 
- pad A9: at 2.45 -4.045; size 0.6 1.45; drill ; layers "F.Cu" "F.Mask" "F.Paste"; net VBUS; zone_connect 
- pad A12: at 3.25 -4.045; size 0.6 1.45; drill ; layers "F.Cu" "F.Mask" "F.Paste"; net GND; zone_connect 2
- pad B1: at 3.25 -4.045; size 0.6 1.45; drill ; layers "F.Cu" "F.Mask" "F.Paste"; net GND; zone_connect 2
- pad B4: at 2.45 -4.045; size 0.6 1.45; drill ; layers "F.Cu" "F.Mask" "F.Paste"; net VBUS; zone_connect 
- pad B5: at 1.75 -4.045; size 0.3 1.45; drill ; layers "F.Cu" "F.Mask" "F.Paste"; net USB_CC2; zone_connect 
- pad B6: at 0.75 -4.045; size 0.3 1.45; drill ; layers "F.Cu" "F.Mask" "F.Paste"; net USB_DP_CONN; zone_connect 
- pad B7: at -0.75 -4.045; size 0.3 1.45; drill ; layers "F.Cu" "F.Mask" "F.Paste"; net USB_DM_CONN; zone_connect 
- pad B8: at -1.75 -4.045; size 0.3 1.45; drill ; layers "F.Cu" "F.Mask" "F.Paste"; net ; zone_connect 
- pad B9: at -2.45 -4.045; size 0.6 1.45; drill ; layers "F.Cu" "F.Mask" "F.Paste"; net VBUS; zone_connect 
- pad B12: at -3.25 -4.045; size 0.6 1.45; drill ; layers "F.Cu" "F.Mask" "F.Paste"; net GND; zone_connect 2
- pad SH: at -4.32 -3.13; size 1 2.1; drill oval 0.6 1.7; layers "*.Cu" "*.Mask"; net GND; zone_connect 2
- pad SH: at -4.32 1.05; size 1 1.6; drill oval 0.6 1.2; layers "*.Cu" "*.Mask"; net GND; zone_connect 2
- pad SH: at 4.32 -3.13; size 1 2.1; drill oval 0.6 1.7; layers "*.Cu" "*.Mask"; net GND; zone_connect 2
- pad SH: at 4.32 1.05; size 1 1.6; drill oval 0.6 1.2; layers "*.Cu" "*.Mask"; net GND; zone_connect 2

### J3 OSO_Module_Bay_10 OSO75:OSO_Module_Bay_10 at 38,119.563 rot 0
- pad 1: at -17.1 -5.2; size 2.2 5; drill ; layers "F.Cu" "F.Mask" "F.Paste"; net GND; zone_connect 
- pad 2: at -13.3 -5.2; size 2.2 5; drill ; layers "F.Cu" "F.Mask" "F.Paste"; net +3V3; zone_connect 
- pad 3: at -9.5 -5.2; size 2.2 5; drill ; layers "F.Cu" "F.Mask" "F.Paste"; net VBUS_FUSED; zone_connect 
- pad 4: at -5.7 -5.2; size 2.2 5; drill ; layers "F.Cu" "F.Mask" "F.Paste"; net I2C_SDA; zone_connect 
- pad 5: at -1.9 -5.2; size 2.2 5; drill ; layers "F.Cu" "F.Mask" "F.Paste"; net I2C_SCL; zone_connect 
- pad 6: at 1.9 -5.2; size 2.2 5; drill ; layers "F.Cu" "F.Mask" "F.Paste"; net MOD_A; zone_connect 
- pad 7: at 5.7 -5.2; size 2.2 5; drill ; layers "F.Cu" "F.Mask" "F.Paste"; net MOD_B; zone_connect 
- pad 8: at 9.5 -5.2; size 2.2 5; drill ; layers "F.Cu" "F.Mask" "F.Paste"; net MOD_INT; zone_connect 
- pad 9: at 13.3 -5.2; size 2.2 5; drill ; layers "F.Cu" "F.Mask" "F.Paste"; net ESP_EN; zone_connect 
- pad 10: at 17.1 -5.2; size 2.2 5; drill ; layers "F.Cu" "F.Mask" "F.Paste"; net GND; zone_connect 

### R1 5.1k OSO75:R_0603 at 179.5,147 rot 0
- pad 1: at -0.8 0; size 0.8 0.9; drill ; layers "F.Cu" "F.Mask" "F.Paste"; net USB_CC1; zone_connect 
- pad 2: at 0.8 0; size 0.8 0.9; drill ; layers "F.Cu" "F.Mask" "F.Paste"; net GND; zone_connect 

### R2 5.1k OSO75:R_0603 at 179.5,144 rot 0
- pad 1: at -0.8 0; size 0.8 0.9; drill ; layers "F.Cu" "F.Mask" "F.Paste"; net USB_CC2; zone_connect 
- pad 2: at 0.8 0; size 0.8 0.9; drill ; layers "F.Cu" "F.Mask" "F.Paste"; net GND; zone_connect 

### R3 27R OSO75:R_0603 at 157.5,145 rot 0
- pad 1: at -0.8 0; size 0.8 0.9; drill ; layers "F.Cu" "F.Mask" "F.Paste"; net USB_DP_CONN; zone_connect 
- pad 2: at 0.8 0; size 0.8 0.9; drill ; layers "F.Cu" "F.Mask" "F.Paste"; net USB_DP; zone_connect 

### R4 27R OSO75:R_0603 at 157.5,141.5 rot 0
- pad 1: at -0.8 0; size 0.8 0.9; drill ; layers "F.Cu" "F.Mask" "F.Paste"; net USB_DM_CONN; zone_connect 
- pad 2: at 0.8 0; size 0.8 0.9; drill ; layers "F.Cu" "F.Mask" "F.Paste"; net USB_DM; zone_connect 

### R5 10k OSO75:R_0603 at 124.5,138 rot 0
- pad 1: at -0.8 0; size 0.8 0.9; drill ; layers "F.Cu" "F.Mask" "F.Paste"; net ESP_EN; zone_connect 
- pad 2: at 0.8 0; size 0.8 0.9; drill ; layers "F.Cu" "F.Mask" "F.Paste"; net +3V3; zone_connect 

### R6 10k OSO75:R_0603 at 131.5,138 rot 0
- pad 1: at -0.8 0; size 0.8 0.9; drill ; layers "F.Cu" "F.Mask" "F.Paste"; net BOOT_IO0; zone_connect 
- pad 2: at 0.8 0; size 0.8 0.9; drill ; layers "F.Cu" "F.Mask" "F.Paste"; net +3V3; zone_connect 

### R10 10k OSO75:R_0603 at 109.5,138 rot 0
- pad 1: at -0.8 0; size 0.8 0.9; drill ; layers "F.Cu" "F.Mask" "F.Paste"; net MOD_INT; zone_connect 
- pad 2: at 0.8 0; size 0.8 0.9; drill ; layers "F.Cu" "F.Mask" "F.Paste"; net +3V3; zone_connect 

### SW_BOOT BOOT OSO75:SW_Tactile_4x3 at 101.5,138 rot 0
- pad 1: at -1.7 0; size 1.2 1.7; drill ; layers "F.Cu" "F.Mask" "F.Paste"; net BOOT_IO0; zone_connect 
- pad 2: at 1.7 0; size 1.2 1.7; drill ; layers "F.Cu" "F.Mask" "F.Paste"; net GND; zone_connect 

### SW_RESET RESET OSO75:SW_Tactile_4x3 at 93.5,138 rot 0
- pad 1: at -1.7 0; size 1.2 1.7; drill ; layers "F.Cu" "F.Mask" "F.Paste"; net ESP_EN; zone_connect 
- pad 2: at 1.7 0; size 1.2 1.7; drill ; layers "F.Cu" "F.Mask" "F.Paste"; net GND; zone_connect 

### U1 ESP32-S3-WROOM-1-N16 RF_Module:ESP32-S3-WROOM-1 at 196,138.8 rot -90
- pad 1: at -8.75 -5.26 270; size 1.5 0.9; drill ; layers "F.Cu" "F.Mask" "F.Paste"; net GND; zone_connect 2
- pad 2: at -8.75 -3.99 270; size 1.5 0.9; drill ; layers "F.Cu" "F.Mask" "F.Paste"; net +3V3; zone_connect 
- pad 3: at -8.75 -2.72 270; size 1.5 0.9; drill ; layers "F.Cu" "F.Mask" "F.Paste"; net ESP_EN; zone_connect 
- pad 4: at -8.75 -1.45 270; size 1.5 0.9; drill ; layers "F.Cu" "F.Mask" "F.Paste"; net ROW2; zone_connect 
- pad 5: at -8.75 -0.18 270; size 1.5 0.9; drill ; layers "F.Cu" "F.Mask" "F.Paste"; net ROW3; zone_connect 
- pad 6: at -8.75 1.09 270; size 1.5 0.9; drill ; layers "F.Cu" "F.Mask" "F.Paste"; net ROW4; zone_connect 
- pad 7: at -8.75 2.36 270; size 1.5 0.9; drill ; layers "F.Cu" "F.Mask" "F.Paste"; net ROW5; zone_connect 
- pad 8: at -8.75 3.63 270; size 1.5 0.9; drill ; layers "F.Cu" "F.Mask" "F.Paste"; net COL7; zone_connect 
- pad 9: at -8.75 4.9 270; size 1.5 0.9; drill ; layers "F.Cu" "F.Mask" "F.Paste"; net COL8; zone_connect 
- pad 10: at -8.75 6.17 270; size 1.5 0.9; drill ; layers "F.Cu" "F.Mask" "F.Paste"; net COL9; zone_connect 
- pad 11: at -8.75 7.44 270; size 1.5 0.9; drill ; layers "F.Cu" "F.Mask" "F.Paste"; net COL10; zone_connect 
- pad 12: at -8.75 8.71 270; size 1.5 0.9; drill ; layers "F.Cu" "F.Mask" "F.Paste"; net COL0; zone_connect 
- pad 13: at -8.75 9.98 270; size 1.5 0.9; drill ; layers "F.Cu" "F.Mask" "F.Paste"; net USB_DM; zone_connect 
- pad 14: at -8.75 11.25 90; size 1.5 0.9; drill ; layers "F.Cu" "F.Mask" "F.Paste"; net USB_DP; zone_connect 
- pad 15: at -6.985 12.5 180; size 1.5 0.9; drill ; layers "F.Cu" "F.Mask" "F.Paste"; net ; zone_connect 
- pad 16: at -5.715 12.5 180; size 1.5 0.9; drill ; layers "F.Cu" "F.Mask" "F.Paste"; net ; zone_connect 
- pad 17: at -4.445 12.5 180; size 1.5 0.9; drill ; layers "F.Cu" "F.Mask" "F.Paste"; net COL1; zone_connect 
- pad 18: at -3.175 12.5 180; size 1.5 0.9; drill ; layers "F.Cu" "F.Mask" "F.Paste"; net COL2; zone_connect 
- pad 19: at -1.905 12.5 180; size 1.5 0.9; drill ; layers "F.Cu" "F.Mask" "F.Paste"; net COL3; zone_connect 
- pad 20: at -0.635 12.5 180; size 1.5 0.9; drill ; layers "F.Cu" "F.Mask" "F.Paste"; net COL4; zone_connect 
- pad 21: at 0.635 12.5 180; size 1.5 0.9; drill ; layers "F.Cu" "F.Mask" "F.Paste"; net COL5; zone_connect 
- pad 22: at 1.905 12.5 180; size 1.5 0.9; drill ; layers "F.Cu" "F.Mask" "F.Paste"; net COL6; zone_connect 
- pad 23: at 3.175 12.5 180; size 1.5 0.9; drill ; layers "F.Cu" "F.Mask" "F.Paste"; net COL11; zone_connect 
- pad 24: at 4.445 12.5 180; size 1.5 0.9; drill ; layers "F.Cu" "F.Mask" "F.Paste"; net MOD_INT; zone_connect 
- pad 25: at 5.715 12.5 180; size 1.5 0.9; drill ; layers "F.Cu" "F.Mask" "F.Paste"; net ; zone_connect 
- pad 26: at 6.985 12.5 180; size 1.5 0.9; drill ; layers "F.Cu" "F.Mask" "F.Paste"; net ; zone_connect 
- pad 27: at 8.75 11.25 270; size 1.5 0.9; drill ; layers "F.Cu" "F.Mask" "F.Paste"; net BOOT_IO0; zone_connect 
- pad 28: at 8.75 9.98 270; size 1.5 0.9; drill ; layers "F.Cu" "F.Mask" "F.Paste"; net COL12; zone_connect 
- pad 29: at 8.75 8.71 270; size 1.5 0.9; drill ; layers "F.Cu" "F.Mask" "F.Paste"; net COL13; zone_connect 
- pad 30: at 8.75 7.44 270; size 1.5 0.9; drill ; layers "F.Cu" "F.Mask" "F.Paste"; net COL14; zone_connect 
- pad 31: at 8.75 6.17 270; size 1.5 0.9; drill ; layers "F.Cu" "F.Mask" "F.Paste"; net COL15; zone_connect 
- pad 32: at 8.75 4.9 270; size 1.5 0.9; drill ; layers "F.Cu" "F.Mask" "F.Paste"; net MOD_A; zone_connect 
- pad 33: at 8.75 3.63 270; size 1.5 0.9; drill ; layers "F.Cu" "F.Mask" "F.Paste"; net MOD_B; zone_connect 
- pad 34: at 8.75 2.36 270; size 1.5 0.9; drill ; layers "F.Cu" "F.Mask" "F.Paste"; net I2C_SDA; zone_connect 
- pad 35: at 8.75 1.09 270; size 1.5 0.9; drill ; layers "F.Cu" "F.Mask" "F.Paste"; net I2C_SCL; zone_connect 
- pad 36: at 8.75 -0.18 270; size 1.5 0.9; drill ; layers "F.Cu" "F.Mask" "F.Paste"; net ; zone_connect 
- pad 37: at 8.75 -1.45 270; size 1.5 0.9; drill ; layers "F.Cu" "F.Mask" "F.Paste"; net ; zone_connect 
- pad 38: at 8.75 -2.72 270; size 1.5 0.9; drill ; layers "F.Cu" "F.Mask" "F.Paste"; net ROW1; zone_connect 
- pad 39: at 8.75 -3.99 270; size 1.5 0.9; drill ; layers "F.Cu" "F.Mask" "F.Paste"; net ROW0; zone_connect 
- pad 40: at 8.75 -5.26 270; size 1.5 0.9; drill ; layers "F.Cu" "F.Mask" "F.Paste"; net GND; zone_connect 
- pad 41: at -2.9 1.76; size 0.6 0.6; drill 0.3; layers "*.Cu" "F.Mask"; net GND; zone_connect 2
- pad 41: at -2.9 3.16 270; size 0.6 0.6; drill 0.3; layers "*.Cu" "F.Mask"; net GND; zone_connect 2
- pad 41: at -2.2 1.06 270; size 0.6 0.6; drill 0.3; layers "*.Cu" "F.Mask"; net GND; zone_connect 2
- pad 41: at -2.2 2.46 270; size 0.6 0.6; drill 0.3; layers "*.Cu" "F.Mask"; net GND; zone_connect 2
- pad 41: at -2.2 3.86 270; size 0.6 0.6; drill 0.3; layers "*.Cu" "F.Mask"; net GND; zone_connect 2
- pad 41: at -1.5 1.76 270; size 0.6 0.6; drill 0.3; layers "*.Cu" "F.Mask"; net GND; zone_connect 2
- pad 41: at -1.5 2.46 180; size 3.9 3.9; drill ; layers "F.Cu" "F.Mask"; net GND; zone_connect 2
- pad 41: at -1.5 3.16 270; size 0.6 0.6; drill 0.3; layers "*.Cu" "F.Mask"; net GND; zone_connect 2
- pad 41: at -0.8 1.06 270; size 0.6 0.6; drill 0.3; layers "*.Cu" "F.Mask"; net GND; zone_connect 2
- pad 41: at -0.8 2.46 270; size 0.6 0.6; drill 0.3; layers "*.Cu" "F.Mask"; net GND; zone_connect 2
- pad 41: at -0.8 3.86 270; size 0.6 0.6; drill 0.3; layers "*.Cu" "F.Mask"; net GND; zone_connect 2
- pad 41: at -0.1 1.76 270; size 0.6 0.6; drill 0.3; layers "*.Cu" "F.Mask"; net GND; zone_connect 2
- pad 41: at -0.1 3.16 270; size 0.6 0.6; drill 0.3; layers "*.Cu" "F.Mask"; net GND; zone_connect 2

### U3 AP2112K-3.3 OSO75:SOT-23-5_LDO at 147,144.5 rot 0
- pad 1: at -1.1 -0.95; size 0.65 0.55; drill ; layers "F.Cu" "F.Mask" "F.Paste"; net VBUS; zone_connect 
- pad 2: at -1.1 0; size 0.65 0.55; drill ; layers "F.Cu" "F.Mask" "F.Paste"; net GND; zone_connect 2
- pad 3: at -1.1 0.95; size 0.65 0.55; drill ; layers "F.Cu" "F.Mask" "F.Paste"; net VBUS; zone_connect 
- pad 4: at 1.1 0.95; size 0.65 0.55; drill ; layers "F.Cu" "F.Mask" "F.Paste"; net ; zone_connect 
- pad 5: at 1.1 -0.95; size 0.65 0.55; drill ; layers "F.Cu" "F.Mask" "F.Paste"; net +3V3; zone_connect 

## All footprints placement list

```csv
ref,value,footprint,x,y,rot
D12,1N4148W,OSO75:D_SOD-123_Keyboard,25.025,101.225,0
C3,100nF,OSO75:C_0603,178,130.5,0
SW12,MX_Hotswap,Switch_MX_Hotswap:SW_Hotswap_Kailh_MX_Plated_1.00u_With_Switch,18.525,94.725,180
SW68,MX_Hotswap,Switch_MX_Hotswap:SW_Hotswap_Kailh_MX_Plated_1.00u_With_Switch,139.969,18.525,180
SW74,MX_Hotswap,Switch_MX_Hotswap:SW_Hotswap_Kailh_MX_Plated_1.00u_With_Switch,318.563,94.725,180
SW22,MX_Hotswap,Switch_MX_Hotswap:SW_Hotswap_Kailh_MX_Plated_1.00u_With_Switch,209.025,94.725,180
SW37,MX_Hotswap,Switch_MX_Hotswap:SW_Hotswap_Kailh_MX_Plated_1.00u_With_Switch,237.6,75.675,180
SW60,MX_Hotswap,Switch_MX_Hotswap:SW_Hotswap_Kailh_MX_Plated_1.00u_With_Switch,175.688,37.575,180
SW38,MX_Hotswap,Switch_MX_Hotswap:SW_Hotswap_Kailh_MX_Plated_1.00u_With_Switch,256.65,75.675,180
D75,1N4148W,OSO75:D_SOD-123_Keyboard,306.012,82.175,0
D28,1N4148W,OSO75:D_SOD-123_Keyboard,72.65,82.175,0
SW_RESET,RESET,OSO75:SW_Tactile_4x3,93.5,138,0
D14,1N4148W,OSO75:D_SOD-123_Keyboard,63.125,101.225,0
SW53,MX_Hotswap,Switch_MX_Hotswap:SW_Hotswap_Kailh_MX_Plated_1.00u_With_Switch,30.431,37.575,180
SW17,MX_Hotswap,Switch_MX_Hotswap:SW_Hotswap_Kailh_MX_Plated_1.00u_With_Switch,113.775,94.725,180
SW44,MX_Hotswap,Switch_MX_Hotswap:SW_Hotswap_Kailh_MX_Plated_1.00u_With_Switch,109.013,56.625,180
SW82,MX_Hotswap,Switch_MX_Hotswap:SW_Hotswap_Kailh_MX_Plated_1.00u_With_Switch,318.563,18.525,180
D25,1N4148W,OSO75:D_SOD-123_Keyboard,282.2,101.225,0
D65,1N4148W,OSO75:D_SOD-123_Keyboard,27.406,25.025,0
D37,1N4148W,OSO75:D_SOD-123_Keyboard,244.1,82.175,0
D80,1N4148W,OSO75:D_SOD-123_Keyboard,286.963,25.025,0
SW30,MX_Hotswap,Switch_MX_Hotswap:SW_Hotswap_Kailh_MX_Plated_1.00u_With_Switch,104.25,75.675,180
SW61,MX_Hotswap,Switch_MX_Hotswap:SW_Hotswap_Kailh_MX_Plated_1.00u_With_Switch,194.738,37.575,180
J1,USB_C_HRO_TYPE-C-31-M-12,Connector_USB:USB_C_Receptacle_HRO_TYPE-C-31-M-12,168.54,147.66,0
SW78,MX_Hotswap,Switch_MX_Hotswap:SW_Hotswap_Kailh_MX_Plated_1.00u_With_Switch,318.563,56.625,180
D6,1N4148W,OSO75:D_SOD-123_Keyboard,186.95,125.037,0
SW18,MX_Hotswap,Switch_MX_Hotswap:SW_Hotswap_Kailh_MX_Plated_1.00u_With_Switch,132.825,94.725,180
SW57,MX_Hotswap,Switch_MX_Hotswap:SW_Hotswap_Kailh_MX_Plated_1.00u_With_Switch,118.538,37.575,180
SW26,MX_Hotswap,Switch_MX_Hotswap:SW_Hotswap_Kailh_MX_Plated_1.00u_With_Switch,23.288,75.675,180
D26,1N4148W,OSO75:D_SOD-123_Keyboard,29.788,82.175,0
D45,1N4148W,OSO75:D_SOD-123_Keyboard,134.563,63.125,0
R2,5.1k,OSO75:R_0603,179.5,144,0
D22,1N4148W,OSO75:D_SOD-123_Keyboard,215.525,101.225,0
D21,1N4148W,OSO75:D_SOD-123_Keyboard,196.475,101.225,0
SW31,MX_Hotswap,Switch_MX_Hotswap:SW_Hotswap_Kailh_MX_Plated_1.00u_With_Switch,123.3,75.675,180
D55,1N4148W,OSO75:D_SOD-123_Keyboard,86.938,44.075,0
D33,1N4148W,OSO75:D_SOD-123_Keyboard,167.9,82.175,0
SW10,MX_Hotswap,Switch_MX_Hotswap:SW_Hotswap_Kailh_MX_Plated_1.00u_With_Switch,266.175,118.537,180
SW16,MX_Hotswap,Switch_MX_Hotswap:SW_Hotswap_Kailh_MX_Plated_1.00u_With_Switch,94.725,94.725,180
R4,27R,OSO75:R_0603,157.5,141.5,0
SW9,MX_Hotswap,Switch_MX_Hotswap:SW_Hotswap_Kailh_MX_Plated_1.00u_With_Switch,247.125,118.537,180
D58,1N4148W,OSO75:D_SOD-123_Keyboard,144.088,44.075,0
SW51,MX_Hotswap,Switch_MX_Hotswap:SW_Hotswap_Kailh_MX_Plated_1.00u_With_Switch,242.363,56.625,180
SW3,MX_Hotswap,Switch_MX_Hotswap:SW_Hotswap_Kailh_MX_Plated_1.00u_With_Switch,113.775,118.537,180
D31,1N4148W,OSO75:D_SOD-123_Keyboard,129.8,82.175,0
SW64,MX_Hotswap,Switch_MX_Hotswap:SW_Hotswap_Kailh_MX_Plated_1.00u_With_Switch,259.031,37.575,180
SW2,MX_Hotswap,Switch_MX_Hotswap:SW_Hotswap_Kailh_MX_Plated_1.00u_With_Switch,94.725,118.537,180
SW67,MX_Hotswap,Switch_MX_Hotswap:SW_Hotswap_Kailh_MX_Plated_1.00u_With_Switch,68.531,18.525,180
SW_BOOT,BOOT,OSO75:SW_Tactile_4x3,101.5,138,0
C4,100nF,OSO75:C_0603,181,142.5,0
U3,AP2112K-3.3,OSO75:SOT-23-5_LDO,147,144.5,0
D50,1N4148W,OSO75:D_SOD-123_Keyboard,229.813,63.125,0
SW8,MX_Hotswap,Switch_MX_Hotswap:SW_Hotswap_Kailh_MX_Plated_1.00u_With_Switch,228.075,118.537,180
U1,ESP32-S3-WROOM-1-N16,RF_Module:ESP32-S3-WROOM-1,196,138.8,-90
SW27,MX_Hotswap,Switch_MX_Hotswap:SW_Hotswap_Kailh_MX_Plated_1.00u_With_Switch,47.1,75.675,180
SW33,MX_Hotswap,Switch_MX_Hotswap:SW_Hotswap_Kailh_MX_Plated_1.00u_With_Switch,161.4,75.675,180
SW5,MX_Hotswap,Switch_MX_Hotswap:SW_Hotswap_Kailh_MX_Plated_1.00u_With_Switch,161.4,118.537,180
D1,1N4148W,OSO75:D_SOD-123_Keyboard,82.175,125.037,0
D67,1N4148W,OSO75:D_SOD-123_Keyboard,75.031,25.025,0
SW65,MX_Hotswap,Switch_MX_Hotswap:SW_Hotswap_Kailh_MX_Plated_1.00u_With_Switch,20.906,18.525,180
SW29,MX_Hotswap,Switch_MX_Hotswap:SW_Hotswap_Kailh_MX_Plated_1.00u_With_Switch,85.2,75.675,180
SW48,MX_Hotswap,Switch_MX_Hotswap:SW_Hotswap_Kailh_MX_Plated_1.00u_With_Switch,185.213,56.625,180
D19,1N4148W,OSO75:D_SOD-123_Keyboard,158.375,101.225,0
D63,1N4148W,OSO75:D_SOD-123_Keyboard,239.338,44.075,0
D36,1N4148W,OSO75:D_SOD-123_Keyboard,225.05,82.175,0
D7,1N4148W,OSO75:D_SOD-123_Keyboard,206,125.037,0
ST3,Stabilizer_Cherry_MX_2.00u,Stabilizer_MX:Stabilizer_Cherry_MX_2.00u,30.431,37.575,180
SW21,MX_Hotswap,Switch_MX_Hotswap:SW_Hotswap_Kailh_MX_Plated_1.00u_With_Switch,189.975,94.725,180
D68,1N4148W,OSO75:D_SOD-123_Keyboard,146.469,25.025,0
D59,1N4148W,OSO75:D_SOD-123_Keyboard,163.138,44.075,0
ST1,Stabilizer_Cherry_MX_2.00u,Stabilizer_MX:Stabilizer_Cherry_MX_2.00u,275.7,94.725,180
D47,1N4148W,OSO75:D_SOD-123_Keyboard,172.662,63.125,0
D9,1N4148W,OSO75:D_SOD-123_Keyboard,253.625,125.037,0
ST4,Stabilizer_Cherry_MX_6.25u,Stabilizer_MX:Stabilizer_Cherry_MX_6.25u,139.969,18.525,180
SW52,MX_Hotswap,Switch_MX_Hotswap:SW_Hotswap_Kailh_MX_Plated_1.00u_With_Switch,273.319,56.625,180
D11,1N4148W,OSO75:D_SOD-123_Keyboard,291.725,125.037,0
J3,OSO_Module_Bay_10,OSO75:OSO_Module_Bay_10,38,119.563,0
D18,1N4148W,OSO75:D_SOD-123_Keyboard,139.325,101.225,0
SW66,MX_Hotswap,Switch_MX_Hotswap:SW_Hotswap_Kailh_MX_Plated_1.00u_With_Switch,44.719,18.525,180
D72,1N4148W,OSO75:D_SOD-123_Keyboard,325.063,125.037,0
D76,1N4148W,OSO75:D_SOD-123_Keyboard,325.063,82.175,0
SW58,MX_Hotswap,Switch_MX_Hotswap:SW_Hotswap_Kailh_MX_Plated_1.00u_With_Switch,137.588,37.575,180
D35,1N4148W,OSO75:D_SOD-123_Keyboard,206,82.175,0
D5,1N4148W,OSO75:D_SOD-123_Keyboard,167.9,125.037,0
D8,1N4148W,OSO75:D_SOD-123_Keyboard,234.575,125.037,0
SW75,MX_Hotswap,Switch_MX_Hotswap:SW_Hotswap_Kailh_MX_Plated_1.00u_With_Switch,299.512,75.675,180
SW72,MX_Hotswap,Switch_MX_Hotswap:SW_Hotswap_Kailh_MX_Plated_1.00u_With_Switch,318.563,118.537,180
D32,1N4148W,OSO75:D_SOD-123_Keyboard,148.85,82.175,0
SW80,MX_Hotswap,Switch_MX_Hotswap:SW_Hotswap_Kailh_MX_Plated_1.00u_With_Switch,280.463,18.525,180
SW81,MX_Hotswap,Switch_MX_Hotswap:SW_Hotswap_Kailh_MX_Plated_1.00u_With_Switch,299.512,18.525,180
SW23,MX_Hotswap,Switch_MX_Hotswap:SW_Hotswap_Kailh_MX_Plated_1.00u_With_Switch,228.075,94.725,180
SW42,MX_Hotswap,Switch_MX_Hotswap:SW_Hotswap_Kailh_MX_Plated_1.00u_With_Switch,70.912,56.625,180
D3,1N4148W,OSO75:D_SOD-123_Keyboard,120.275,125.037,0
D71,1N4148W,OSO75:D_SOD-123_Keyboard,265.531,25.025,0
SW34,MX_Hotswap,Switch_MX_Hotswap:SW_Hotswap_Kailh_MX_Plated_1.00u_With_Switch,180.45,75.675,180
D66,1N4148W,OSO75:D_SOD-123_Keyboard,51.219,25.025,0
SW4,MX_Hotswap,Switch_MX_Hotswap:SW_Hotswap_Kailh_MX_Plated_1.00u_With_Switch,142.35,118.537,180
SW62,MX_Hotswap,Switch_MX_Hotswap:SW_Hotswap_Kailh_MX_Plated_1.00u_With_Switch,213.787,37.575,180
SW73,MX_Hotswap,Switch_MX_Hotswap:SW_Hotswap_Kailh_MX_Plated_1.00u_With_Switch,299.512,94.725,180
D48,1N4148W,OSO75:D_SOD-123_Keyboard,191.713,63.125,0
SW49,MX_Hotswap,Switch_MX_Hotswap:SW_Hotswap_Kailh_MX_Plated_1.00u_With_Switch,204.263,56.625,180
C2,10uF,OSO75:C_0603,141.5,144.5,0
D54,1N4148W,OSO75:D_SOD-123_Keyboard,67.888,44.075,0
SW76,MX_Hotswap,Switch_MX_Hotswap:SW_Hotswap_Kailh_MX_Plated_1.00u_With_Switch,318.563,75.675,180
D44,1N4148W,OSO75:D_SOD-123_Keyboard,115.513,63.125,0
SW47,MX_Hotswap,Switch_MX_Hotswap:SW_Hotswap_Kailh_MX_Plated_1.00u_With_Switch,166.162,56.625,180
R5,10k,OSO75:R_0603,124.5,138,0
SW36,MX_Hotswap,Switch_MX_Hotswap:SW_Hotswap_Kailh_MX_Plated_1.00u_With_Switch,218.55,75.675,180
D23,1N4148W,OSO75:D_SOD-123_Keyboard,234.575,101.225,0
D61,1N4148W,OSO75:D_SOD-123_Keyboard,201.238,44.075,0
SW39,MX_Hotswap,Switch_MX_Hotswap:SW_Hotswap_Kailh_MX_Plated_1.00u_With_Switch,280.463,75.675,180
SW35,MX_Hotswap,Switch_MX_Hotswap:SW_Hotswap_Kailh_MX_Plated_1.00u_With_Switch,199.5,75.675,180
D27,1N4148W,OSO75:D_SOD-123_Keyboard,53.6,82.175,0
D60,1N4148W,OSO75:D_SOD-123_Keyboard,182.188,44.075,0
SW71,MX_Hotswap,Switch_MX_Hotswap:SW_Hotswap_Kailh_MX_Plated_1.00u_With_Switch,259.031,18.525,180
SW46,MX_Hotswap,Switch_MX_Hotswap:SW_Hotswap_Kailh_MX_Plated_1.00u_With_Switch,147.113,56.625,180
D69,1N4148W,OSO75:D_SOD-123_Keyboard,217.906,25.025,0
F1,500mA,OSO75:Polyfuse_1206,117,138,0
D4,1N4148W,OSO75:D_SOD-123_Keyboard,148.85,125.037,0
D17,1N4148W,OSO75:D_SOD-123_Keyboard,120.275,101.225,0
SW15,MX_Hotswap,Switch_MX_Hotswap:SW_Hotswap_Kailh_MX_Plated_1.00u_With_Switch,75.675,94.725,180
D34,1N4148W,OSO75:D_SOD-123_Keyboard,186.95,82.175,0
SW79,MX_Hotswap,Switch_MX_Hotswap:SW_Hotswap_Kailh_MX_Plated_1.00u_With_Switch,299.512,37.575,180
D42,1N4148W,OSO75:D_SOD-123_Keyboard,77.412,63.125,0
SW28,MX_Hotswap,Switch_MX_Hotswap:SW_Hotswap_Kailh_MX_Plated_1.00u_With_Switch,66.15,75.675,180
SW43,MX_Hotswap,Switch_MX_Hotswap:SW_Hotswap_Kailh_MX_Plated_1.00u_With_Switch,89.963,56.625,180
D38,1N4148W,OSO75:D_SOD-123_Keyboard,263.15,82.175,0
D53,1N4148W,OSO75:D_SOD-123_Keyboard,36.931,44.075,0
R6,10k,OSO75:R_0603,131.5,138,0
D56,1N4148W,OSO75:D_SOD-123_Keyboard,105.987,44.075,0
D49,1N4148W,OSO75:D_SOD-123_Keyboard,210.763,63.125,0
R1,5.1k,OSO75:R_0603,179.5,147,0
D43,1N4148W,OSO75:D_SOD-123_Keyboard,96.463,63.125,0
SW32,MX_Hotswap,Switch_MX_Hotswap:SW_Hotswap_Kailh_MX_Plated_1.00u_With_Switch,142.35,75.675,180
SW19,MX_Hotswap,Switch_MX_Hotswap:SW_Hotswap_Kailh_MX_Plated_1.00u_With_Switch,151.875,94.725,180
R10,10k,OSO75:R_0603,109.5,138,0
D39,1N4148W,OSO75:D_SOD-123_Keyboard,286.963,82.175,0
D77,1N4148W,OSO75:D_SOD-123_Keyboard,306.012,63.125,0
D30,1N4148W,OSO75:D_SOD-123_Keyboard,110.75,82.175,0
SW11,MX_Hotswap,Switch_MX_Hotswap:SW_Hotswap_Kailh_MX_Plated_1.00u_With_Switch,285.225,118.537,180
D16,1N4148W,OSO75:D_SOD-123_Keyboard,101.225,101.225,0
SW13,MX_Hotswap,Switch_MX_Hotswap:SW_Hotswap_Kailh_MX_Plated_1.00u_With_Switch,37.575,94.725,180
SW69,MX_Hotswap,Switch_MX_Hotswap:SW_Hotswap_Kailh_MX_Plated_1.00u_With_Switch,211.406,18.525,180
SW55,MX_Hotswap,Switch_MX_Hotswap:SW_Hotswap_Kailh_MX_Plated_1.00u_With_Switch,80.438,37.575,180
D79,1N4148W,OSO75:D_SOD-123_Keyboard,306.012,44.075,0
C1,10uF,OSO75:C_0603,152.5,144.5,0
D73,1N4148W,OSO75:D_SOD-123_Keyboard,306.012,101.225,0
SW50,MX_Hotswap,Switch_MX_Hotswap:SW_Hotswap_Kailh_MX_Plated_1.00u_With_Switch,223.313,56.625,180
SW7,MX_Hotswap,Switch_MX_Hotswap:SW_Hotswap_Kailh_MX_Plated_1.00u_With_Switch,199.5,118.537,180
SW20,MX_Hotswap,Switch_MX_Hotswap:SW_Hotswap_Kailh_MX_Plated_1.00u_With_Switch,170.925,94.725,180
D2,1N4148W,OSO75:D_SOD-123_Keyboard,101.225,125.037,0
R3,27R,OSO75:R_0603,157.5,145,0
SW54,MX_Hotswap,Switch_MX_Hotswap:SW_Hotswap_Kailh_MX_Plated_1.00u_With_Switch,61.388,37.575,180
D82,1N4148W,OSO75:D_SOD-123_Keyboard,325.063,25.025,0
D51,1N4148W,OSO75:D_SOD-123_Keyboard,248.863,63.125,0
D70,1N4148W,OSO75:D_SOD-123_Keyboard,241.719,25.025,0
D78,1N4148W,OSO75:D_SOD-123_Keyboard,325.063,63.125,0
D40,1N4148W,OSO75:D_SOD-123_Keyboard,32.169,63.125,0
SW59,MX_Hotswap,Switch_MX_Hotswap:SW_Hotswap_Kailh_MX_Plated_1.00u_With_Switch,156.638,37.575,180
SW56,MX_Hotswap,Switch_MX_Hotswap:SW_Hotswap_Kailh_MX_Plated_1.00u_With_Switch,99.487,37.575,180
D74,1N4148W,OSO75:D_SOD-123_Keyboard,325.063,101.225,0
SW70,MX_Hotswap,Switch_MX_Hotswap:SW_Hotswap_Kailh_MX_Plated_1.00u_With_Switch,235.219,18.525,180
SW63,MX_Hotswap,Switch_MX_Hotswap:SW_Hotswap_Kailh_MX_Plated_1.00u_With_Switch,232.838,37.575,180
SW77,MX_Hotswap,Switch_MX_Hotswap:SW_Hotswap_Kailh_MX_Plated_1.00u_With_Switch,299.512,56.625,180
D10,1N4148W,OSO75:D_SOD-123_Keyboard,272.675,125.037,0
D15,1N4148W,OSO75:D_SOD-123_Keyboard,82.175,101.225,0
ST2,Stabilizer_Cherry_MX_2.00u,Stabilizer_MX:Stabilizer_Cherry_MX_2.00u,273.319,56.625,180
D20,1N4148W,OSO75:D_SOD-123_Keyboard,177.425,101.225,0
D81,1N4148W,OSO75:D_SOD-123_Keyboard,306.012,25.025,0
SW24,MX_Hotswap,Switch_MX_Hotswap:SW_Hotswap_Kailh_MX_Plated_1.00u_With_Switch,247.125,94.725,180
SW40,MX_Hotswap,Switch_MX_Hotswap:SW_Hotswap_Kailh_MX_Plated_1.00u_With_Switch,25.669,56.625,180
D13,1N4148W,OSO75:D_SOD-123_Keyboard,44.075,101.225,0
D62,1N4148W,OSO75:D_SOD-123_Keyboard,220.287,44.075,0
D29,1N4148W,OSO75:D_SOD-123_Keyboard,91.7,82.175,0
SW41,MX_Hotswap,Switch_MX_Hotswap:SW_Hotswap_Kailh_MX_Plated_1.00u_With_Switch,51.863,56.625,180
D64,1N4148W,OSO75:D_SOD-123_Keyboard,265.531,44.075,0
D52,1N4148W,OSO75:D_SOD-123_Keyboard,279.819,63.125,0
SW1,MX_Hotswap,Switch_MX_Hotswap:SW_Hotswap_Kailh_MX_Plated_1.00u_With_Switch,75.675,118.537,180
D57,1N4148W,OSO75:D_SOD-123_Keyboard,125.038,44.075,0
D24,1N4148W,OSO75:D_SOD-123_Keyboard,253.625,101.225,0
SW6,MX_Hotswap,Switch_MX_Hotswap:SW_Hotswap_Kailh_MX_Plated_1.00u_With_Switch,180.45,118.537,180
D41,1N4148W,OSO75:D_SOD-123_Keyboard,58.363,63.125,0
SW14,MX_Hotswap,Switch_MX_Hotswap:SW_Hotswap_Kailh_MX_Plated_1.00u_With_Switch,56.625,94.725,180
D46,1N4148W,OSO75:D_SOD-123_Keyboard,153.613,63.125,0
SW25,MX_Hotswap,Switch_MX_Hotswap:SW_Hotswap_Kailh_MX_Plated_1.00u_With_Switch,275.7,94.725,180
SW45,MX_Hotswap,Switch_MX_Hotswap:SW_Hotswap_Kailh_MX_Plated_1.00u_With_Switch,128.063,56.625,180
```

## Critical net copper snippets

### VBUS
count 25
```sexpr
(segment
		(start 166.2927 145.6589)
		(end 166.5134 145.8797)
		(width 0.2)
		(layer "F.Cu")
		(net "VBUS")
		(uuid "0281c665-0cc0-4ef6-bd27-cb3a9c52aded")
	)
```
```sexpr
(segment
		(start 169.644 145.2752)
		(end 169.9314 145.2752)
		(width 0.2)
		(layer "F.Cu")
		(net "VBUS")
		(uuid "0d4a628f-ec1f-434a-9c35-38bce1851fd5")
	)
```
```sexpr
(segment
		(start 144.8 143.55)
		(end 145.9 143.55)
		(width 0.2)
		(layer "F.Cu")
		(net "VBUS")
		(uuid "0ee4f78e-2eaf-4176-ade1-69aaea3fdf42")
	)
```
```sexpr
(segment
		(start 117.3659 136.8341)
		(end 139.1841 136.8341)
		(width 0.2)
		(layer "F.Cu")
		(net "VBUS")
		(uuid "105970a6-c132-43fa-ac6b-3d77a1642fc4")
	)
```
```sexpr
(segment
		(start 166.09 143.615)
		(end 166.09 144.2166)
		(width 0.2)
		(layer "F.Cu")
		(net "VBUS")
		(uuid "189b4aec-65b8-4853-86e2-2c2896ec6bde")
	)
```
```sexpr
(segment
		(start 144.8 145.45)
		(end 144.8 143.55)
		(width 0.2)
		(layer "F.Cu")
		(net "VBUS")
		(uuid "265c7de8-750d-43fd-b140-fb7358e682d2")
	)
```
```sexpr
(segment
		(start 166.0055 145.9461)
		(end 153.4389 145.9461)
		(width 0.2)
		(layer "F.Cu")
		(net "VBUS")
		(uuid "4253d17f-afdb-4932-98d6-3c4dfad259d4")
	)
```
```sexpr
(segment
		(start 166.5451 144.6717)
		(end 166.5451 145.4065)
		(width 0.2)
		(layer "F.Cu")
		(net "VBUS")
		(uuid "5b7846e9-fa1c-4f90-b5cd-534b85140d4f")
	)
```
```sexpr
(segment
		(start 169.9314 145.2752)
		(end 170.99 144.2166)
		(width 0.2)
		(layer "F.Cu")
		(net "VBUS")
		(uuid "66125cc3-2d4e-45da-8dfb-dbda93f9774f")
	)
```
```sexpr
(segment
		(start 166.2927 145.6589)
		(end 166.0055 145.9461)
		(width 0.2)
		(layer "F.Cu")
		(net "VBUS")
		(uuid "69b3074b-e5c4-4405-854c-7f34692ad679")
	)
```
```sexpr
(segment
		(start 151.7 144.5)
		(end 151.7 142.4)
		(width 0.2)
		(layer "F.Cu")
		(net "VBUS")
		(uuid "7cafa720-c5b1-4815-aa8f-7bc56744fcca")
	)
```
```sexpr
(segment
		(start 116.2 138)
		(end 117.3659 136.8341)
		(width 0.2)
		(layer "F.Cu")
		(net "VBUS")
		(uuid "8d50264b-b22b-46ea-8388-c31e40a5349a")
	)
```
```sexpr
(segment
		(start 145.9 142.4)
		(end 145.9 143.55)
		(width 0.2)
		(layer "F.Cu")
		(net "VBUS")
		(uuid "933c6eee-1168-4e30-8139-b52ef1ba0fc0")
	)
```
```sexpr
(segment
		(start 170.99 144.2166)
		(end 170.99 143.615)
		(width 0.2)
		(layer "F.Cu")
		(net "VBUS")
		(uuid "ac65dd3a-f79e-4197-817d-6c0861a2f309")
	)
```
```sexpr
(segment
		(start 166.5451 145.4065)
		(end 166.2927 145.6589)
		(width 0.2)
		(layer "F.Cu")
		(net "VBUS")
		(uuid "b236bbfc-32c6-49ee-8b6d-4d86a5e54179")
	)
```
```sexpr
(segment
		(start 153.4389 145.9461)
		(end 151.9928 144.5)
		(width 0.2)
		(layer "F.Cu")
		(net "VBUS")
		(uuid "b8277197-cb6e-42fc-9a6d-5ebcb1511fb7")
	)
```
```sexpr
(segment
		(start 151.9928 144.5)
		(end 151.7 144.5)
		(width 0.2)
		(layer "F.Cu")
		(net "VBUS")
		(uuid "da09f8f2-c354-4e47-8f4f-2e50be7d0e04")
	)
```
```sexpr
(segment
		(start 145.9 145.45)
		(end 144.8 145.45)
		(width 0.2)
		(layer "F.Cu")
		(net "VBUS")
		(uuid "dde1331d-8908-4d4f-a47f-6661936a9c46")
	)
```
```sexpr
(segment
		(start 166.09 144.2166)
		(end 166.5451 144.6717)
		(width 0.2)
		(layer "F.Cu")
		(net "VBUS")
		(uuid "e08128d9-9c16-470d-b497-9e194bcf5aa4")
	)
```
```sexpr
(segment
		(start 151.7 142.4)
		(end 145.9 142.4)
		(width 0.2)
		(layer "F.Cu")
		(net "VBUS")
		(uuid "e0dc7190-3ffa-4a9d-8c09-e95fcc8daf2b")
	)
```
```sexpr
(segment
		(start 139.1841 136.8341)
		(end 145.9 143.55)
		(width 0.2)
		(layer "F.Cu")
		(net "VBUS")
		(uuid "f27bd40d-ac6b-4067-8cf1-013d302f1a76")
	)
```
```sexpr
(via
		(at 166.5134 145.8797)
		(size 0.6)
		(drill 0.3)
		(layers "F.Cu" "B.Cu")
		(net "VBUS")
		(uuid "2b7afc7d-1301-4991-a039-b0f7bbeaa2bd")
	)
```
```sexpr
(via
		(at 169.644 145.2752)
		(size 0.6)
		(drill 0.3)
		(layers "F.Cu" "B.Cu")
		(net "VBUS")
		(uuid "6927882d-58f4-4a85-a172-c7c35f69e24f")
	)
```
```sexpr
(segment
		(start 166.5134 145.8797)
		(end 167.1179 145.2752)
		(width 0.2)
		(layer "B.Cu")
		(net "VBUS")
		(uuid "9a4a8f51-c969-4444-ad02-f22bfb17ed52")
	)
```
```sexpr
(segment
		(start 167.1179 145.2752)
		(end 169.644 145.2752)
		(width 0.2)
		(layer "B.Cu")
		(net "VBUS")
		(uuid "ac21367e-adc6-4f3d-8d9a-db41c55b78d1")
	)
```
### +3V3
count 61
```sexpr
(segment
		(start 95.2 109.113)
		(end 32.7 109.113)
		(width 0.2)
		(layer "F.Cu")
		(net "+3V3")
		(uuid "00869be7-d072-44e7-be56-cb61af70d7b9")
	)
```
```sexpr
(segment
		(start 126.0547 137.2453)
		(end 131.5453 137.2453)
		(width 0.2)
		(layer "F.Cu")
		(net "+3V3")
		(uuid "04a5ca5f-6f55-4293-b8bb-d4c801559e24")
	)
```
```sexpr
(segment
		(start 140.7 144.5)
		(end 138.8 144.5)
		(width 0.4)
		(layer "F.Cu")
		(net "+3V3")
		(uuid "1c711a1c-a05b-4aed-9dfd-e9717639c5c6")
	)
```
```sexpr
(segment
		(start 199.99 130.05)
		(end 199.99 131.1017)
		(width 0.4)
		(layer "F.Cu")
		(net "+3V3")
		(uuid "27f50ba8-ff88-4ce4-bbec-f2e8eb2f31e2")
	)
```
```sexpr
(segment
		(start 198.0205 133.0712)
		(end 199.99 131.1017)
		(width 0.4)
		(layer "F.Cu")
		(net "+3V3")
		(uuid "33e0d953-9199-4fac-803a-47aef22d991d")
	)
```
```sexpr
(segment
		(start 178.2263 142.5046)
		(end 180.1954 142.5046)
		(width 0.2)
		(layer "F.Cu")
		(net "+3V3")
		(uuid "33e31304-885e-4160-a611-e7f1fd0d60a3")
	)
```
```sexpr
(segment
		(start 24.95 113.863)
		(end 24.95 114.113)
		(width 0.2)
		(layer "F.Cu")
		(net "+3V3")
		(uuid "4384cba3-3026-4a4e-9af3-12d5b0536275")
	)
```
```sexpr
(segment
		(start 148.1 143.55)
		(end 149.2 143.55)
		(width 0.25)
		(layer "F.Cu")
		(net "+3V3")
		(uuid "4813ffd2-0faf-459b-89fd-bcc6030b918b")
	)
```
```sexpr
(segment
		(start 138.8 144.5)
		(end 132.3 138)
		(width 0.2)
		(layer "F.Cu")
		(net "+3V3")
		(uuid "4c1f4cf6-87ff-44f7-a01c-d81f3dda8389")
	)
```
```sexpr
(segment
		(start 24.95 114.113)
		(end 24.7 114.363)
		(width 0.2)
		(layer "F.Cu")
		(net "+3V3")
		(uuid "61bbf38c-29b3-48ab-bc8d-a1ceb551534e")
	)
```
```sexpr
(segment
		(start 131.5453 137.2453)
		(end 132.3 138)
		(width 0.2)
		(layer "F.Cu")
		(net "+3V3")
		(uuid "6b097e34-ef45-4ac1-b1d3-acd422570501")
	)
```
```sexpr
(segment
		(start 30.45 111.363)
		(end 27.45 111.363)
		(width 0.2)
		(layer "F.Cu")
		(net "+3V3")
		(uuid "7c92a998-205c-4fc7-afbe-b61d4bf67e1a")
	)
```
```sexpr
(segment
		(start 124.7 138.363)
		(end 124.5163 138.7837)
		(width 0.2)
		(layer "F.Cu")
		(net "+3V3")
		(uuid "81ec7714-2e3a-46b7-af21-1d4907b2716c")
	)
```
```sexpr
(segment
		(start 125.3 138)
		(end 124.5163 138.7837)
		(width 0.2)
		(layer "F.Cu")
		(net "+3V3")
		(uuid "8feb4785-5d07-453c-ba3d-1e2d4c7485d9")
	)
```
```sexpr
(segment
		(start 125.3 138)
		(end 126.0547 137.2453)
		(width 0.2)
		(layer "F.Cu")
		(net "+3V3")
		(uuid "98cd1d1b-a405-43e1-9063-a6a3b5fd745e")
	)
```
```sexpr
(segment
		(start 27.45 111.363)
		(end 24.95 113.863)
		(width 0.2)
		(layer "F.Cu")
		(net "+3V3")
		(uuid "a86e5690-9363-41a3-8f33-4ed5408dedc2")
	)
```
```sexpr
(segment
		(start 32.7 109.113)
		(end 30.45 111.363)
		(width 0.2)
		(layer "F.Cu")
		(net "+3V3")
		(uuid "afbd60af-3d4b-41e8-aadc-0dad3a47c8ef")
	)
```
```sexpr
(segment
		(start 185.8003 133.0712)
		(end 198.0205 133.0712)
		(width 0.2)
		(layer "F.Cu")
		(net "+3V3")
		(uuid "b0a8dbfa-7e20-4c16-8c6c-193dce8e3995")
	)
```
```sexpr
(segment
		(start 180.1954 142.5046)
		(end 180.2 142.5)
		(width 0.2)
		(layer "F.Cu")
		(net "+3V3")
		(uuid "bde5e56c-38f4-4604-90f9-31a46e1ae205")
	)
```
```sexpr
(segment
		(start 124.5163 138.7837)
		(end 111.0837 138.7837)
		(width 0.2)
		(layer "F.Cu")
		(net "+3V3")
		(uuid "c184f772-bda3-4c48-949a-806f2457f0e8")
	)
```
```sexpr
(segment
		(start 111.0837 138.7837)
		(end 110.3 138)
		(width 0.2)
		(layer "F.Cu")
		(net "+3V3")
		(uuid "e0db4649-9200-4d09-bbc6-ce4f64ad8fb3")
	)
```
```sexpr
(via
		(at 138.8 144.5)
		(size 0.6)
		(drill 0.3)
		(layers "F.Cu" "B.Cu")
		(net "+3V3")
		(uuid "36cb89f5-8e7f-455b-a9c1-7d97158c39de")
	)
```
```sexpr
(via
		(at 124.7 138.363)
		(size 0.6)
		(drill 0.3)
		(layers "F.Cu" "B.Cu")
		(net "+3V3")
		(uuid "43d1d67c-3c6f-4fb5-964a-db0d8576fb53")
	)
```
```sexpr
(via
		(at 177.2 130.5)
		(size 0.6)
		(drill 0.3)
		(layers "F.Cu" "B.Cu")
		(net "+3V3")
		(uuid "69c3b7e8-ce2d-4738-8cea-8bdfed0b480d")
	)
```
```sexpr
(via
		(at 149.2 143.55)
		(size 0.6)
		(drill 0.3)
		(layers "F.Cu" "B.Cu")
		(net "+3V3")
		(uuid "7724fb7d-d12b-41da-ac74-0566610f14b8")
	)
```
```sexpr
(via
		(at 178.2263 142.5046)
		(size 0.6)
		(drill 0.3)
		(layers "F.Cu" "B.Cu")
		(net "+3V3")
		(uuid "87fad802-672d-4e7f-92fb-6bdcb9af972f")
	)
```
```sexpr
(via
		(at 95.2 109.113)
		(size 0.6)
		(drill 0.3)
		(layers "F.Cu" "B.Cu")
		(net "+3V3")
		(uuid "ce50dba8-a62b-4e55-96d6-30a8b3b310c2")
	)
```
```sexpr
(via
		(at 185.8003 133.0712)
		(size 0.6)
		(drill 0.3)
		(layers "F.Cu" "B.Cu")
		(net "+3V3")
		(uuid "d246fdca-e32a-4a70-ac5a-c68862efee79")
	)
```
```sexpr
(via
		(at 177.6797 134.5133)
		(size 0.6)
		(drill 0.3)
		(layers "F.Cu" "B.Cu")
		(net "+3V3")
		(uuid "d7ab6308-c6d6-4f5e-bbc9-c4601cc46b27")
	)
```
```sexpr
(segment
		(start 181.1723 131.0207)
		(end 181.2 131)
		(width 0.2)
		(layer "B.Cu")
		(net "+3V3")
		(uuid "1f78d1d1-124b-46c3-b978-49b2529adda6")
	)
```
```sexpr
(segment
		(start 107.45 119.363)
		(end 107.45 119.113)
		(width 0.2)
		(layer "B.Cu")
		(net "+3V3")
		(uuid "224c2e5d-90dd-4542-928e-928153284595")
	)
```
```sexpr
(segment
		(start 185.8003 131.4634)
		(end 185.8003 133.0712)
		(width 0.2)
		(layer "B.Cu")
		(net "+3V3")
		(uuid "323d5e47-ea2e-4676-9577-e12e85ff376f")
	)
```
```sexpr
(segment
		(start 107.45 119.113)
		(end 97.95 109.613)
		(width 0.2)
		(layer "B.Cu")
		(net "+3V3")
		(uuid "3dfbcdb3-1c31-4dcc-8092-9c97e28766af")
	)
```
```sexpr
(segment
		(start 177.5526 143.1783)
		(end 178.2263 142.5046)
		(width 0.4)
		(layer "B.Cu")
		(net "+3V3")
		(uuid "3f91c63e-5a03-4e78-b74a-855b27c22183")
	)
```
```sexpr
(segment
		(start 138.8 144.5)
		(end 149.2 143.55)
		(width 0.25)
		(layer "B.Cu")
		(net "+3V3")
		(uuid "40456ce7-b4df-497e-ac03-c393806a8d53")
	)
```
```sexpr
(segment
		(start 112.2 121.363)
		(end 111.45 121.363)
		(width 0.2)
		(layer "B.Cu")
		(net "+3V3")
		(uuid "586b668f-9ea6-40e8-901b-e1322655beee")
	)
```
```sexpr
(segment
		(start 97.95 109.363)
		(end 97.7 109.113)
		(width 0.2)
		(layer "B.Cu")
		(net "+3V3")
		(uuid "665745df-86b7-4081-aa71-93eb2e0528b5")
	)
```
```sexpr
(segment
		(start 113.45 122.613)
		(end 112.2 121.363)
		(width 0.2)
		(layer "B.Cu")
		(net "+3V3")
		(uuid "6d63878e-bcf6-4c6e-a500-dc0ac8c9af35")
	)
```
```sexpr
(segment
		(start 124.7 138.363)
		(end 113.7 127.363)
		(width 0.2)
		(layer "B.Cu")
		(net "+3V3")
		(uuid "703a87dc-b01d-41a2-a556-6e3a43622f03")
	)
```
```sexpr
(segment
		(start 177.6797 134.5133)
		(end 181.1723 131.0207)
		(width 0.2)
		(layer "B.Cu")
		(net "+3V3")
		(uuid "72f60bf5-9173-4a63-9203-aa93bfce314c")
	)
```
```sexpr
(segment
		(start 113.7 123.363)
		(end 113.45 123.113)
		(width 0.2)
		(layer "B.Cu")
		(net "+3V3")
		(uuid "7953b2a7-4cdd-4823-9e19-5962b176fcf1")
	)
```
```sexpr
(segment
		(start 178.2 131)
		(end 177.95 130.75)
		(width 0.2)
		(layer "B.Cu")
		(net "+3V3")
		(uuid "799724ba-8f12-4002-9a72-97877e738472")
	)
```
```sexpr
(segment
		(start 113.7 127.363)
		(end 113.7 123.363)
		(width 0.2)
		(layer "B.Cu")
		(net "+3V3")
		(uuid "7da18834-12cb-4299-ac43-5c5eff00a2e9")
	)
```
```sexpr
(segment
		(start 181.2 131)
		(end 178.2 131)
		(width 0.2)
		(layer "B.Cu")
		(net "+3V3")
		(uuid "8c78ffa1-4ea3-426f-acf2-5065f21c2d70")
	)
```
```sexpr
(segment
		(start 111.45 121.363)
		(end 111.2 121.113)
		(width 0.2)
		(layer "B.Cu")
		(net "+3V3")
		(uuid "8ee174c3-e2c5-4cb7-a2ef-b402071128f1")
	)
```
```sexpr
(segment
		(start 185.8003 136.584)
		(end 179.8797 142.5046)
		(width 0.2)
		(layer "B.Cu")
		(net "+3V3")
		(uuid "92a84a2e-f6ca-44e4-8ebd-a9391f7f90d5")
	)
```
```sexpr
(segment
		(start 163.8879 143.1783)
		(end 177.5526 143.1783)
		(width 0.2)
		(layer "B.Cu")
		(net "+3V3")
		(uuid "a6143498-2e4b-493f-b478-7c9ece8fe92d")
	)
```
```sexpr
(segment
		(start 177.95 130.75)
		(end 177.45 130.75)
		(width 0.2)
		(layer "B.Cu")
		(net "+3V3")
		(uuid "ab5f7321-f8c1-4311-9415-7584741e972e")
	)
```
```sexpr
(segment
		(start 177.45 130.75)
		(end 177.2 130.5)
		(width 0.2)
		(layer "B.Cu")
		(net "+3V3")
		(uuid "acb19c37-e9ac-488d-9303-263a1e5f2a41")
	)
```
```sexpr
(segment
		(start 185.8003 133.0712)
		(end 185.8003 136.584)
		(width 0.2)
		(layer "B.Cu")
		(net "+3V3")
		(uuid "aea2d3f3-b0bd-484f-8d4c-30f3beb09386")
	)
```
```sexpr
(segment
		(start 149.2 143.55)
		(end 152.5173 145.8754)
		(width 0.25)
		(layer "B.Cu")
		(net "+3V3")
		(uuid "aec4b333-fc65-48fa-8877-f5648ff72473")
	)
```
```sexpr
(segment
		(start 185.3576 131.0207)
		(end 185.8003 131.4634)
		(width 0.2)
		(layer "B.Cu")
		(net "+3V3")
		(uuid "b49220d7-332b-4d4b-b847-c208c3ba53f5")
	)
```
```sexpr
(segment
		(start 113.45 123.113)
		(end 113.45 122.613)
		(width 0.2)
		(layer "B.Cu")
		(net "+3V3")
		(uuid "c33c8cb7-11c4-4804-be1f-7c48a4661298")
	)
```
```sexpr
(segment
		(start 97.7 109.113)
		(end 95.2 109.113)
		(width 0.2)
		(layer "B.Cu")
		(net "+3V3")
		(uuid "cfd2d12d-4093-4487-b12d-1d0cb31e1d5d")
	)
```
```sexpr
(segment
		(start 152.5173 145.8754)
		(end 161.1908 145.8754)
		(width 0.2)
		(layer "B.Cu")
		(net "+3V3")
		(uuid "deefa29d-1d81-4fde-bf7a-264c759180d4")
	)
```
```sexpr
(segment
		(start 97.95 109.613)
		(end 97.95 109.363)
		(width 0.2)
		(layer "B.Cu")
		(net "+3V3")
		(uuid "e2826417-d371-46aa-8a46-4f94e7f5c5c2")
	)
```
```sexpr
(segment
		(start 179.8797 142.5046)
		(end 178.2263 142.5046)
		(width 0.2)
		(layer "B.Cu")
		(net "+3V3")
		(uuid "e4c7aa21-79ed-4ad9-8a19-3b7709027ff1")
	)
```
```sexpr
(segment
		(start 181.1723 131.0207)
		(end 185.3576 131.0207)
		(width 0.2)
		(layer "B.Cu")
		(net "+3V3")
		(uuid "e869e53a-6fec-4566-b05c-9f8b1303f703")
	)
```
```sexpr
(segment
		(start 111.2 121.113)
		(end 109.2 121.113)
		(width 0.2)
		(layer "B.Cu")
		(net "+3V3")
		(uuid "eb9e9642-b730-4581-8abc-17f329fd8ad0")
	)
```
```sexpr
(segment
		(start 161.1908 145.8754)
		(end 163.8879 143.1783)
		(width 0.2)
		(layer "B.Cu")
		(net "+3V3")
		(uuid "fedb9d28-ee5b-4bee-80ef-425ad96ea505")
	)
```
```sexpr
(segment
		(start 109.2 121.113)
		(end 107.45 119.363)
		(width 0.2)
		(layer "B.Cu")
		(net "+3V3")
		(uuid "ffa58ebd-8bdd-4caf-bb67-b13ff23fa8e2")
	)
```
### GND
count 13
```sexpr
(via
		(at 138 141.5)
		(size 0.6)
		(drill 0.3)
		(layers "F.Cu" "B.Cu")
		(net "GND")
		(uuid "2081d886-6b99-4a3f-972c-273270f241f1")
	)
```
```sexpr
(via
		(at 133.383364 137.7346)
		(size 0.6)
		(drill 0.3)
		(layers "F.Cu" "B.Cu")
		(net "GND")
		(uuid "2ff67a1c-37a5-4a78-9f66-407d16895c81")
	)
```
```sexpr
(via
		(at 92 131.5)
		(size 0.6)
		(drill 0.3)
		(layers "F.Cu" "B.Cu")
		(net "GND")
		(uuid "442b1bf0-3c7a-4bdd-9bd4-61240ccc156c")
	)
```
```sexpr
(via
		(at 180.552405 143.9763)
		(size 0.6)
		(drill 0.3)
		(layers "F.Cu" "B.Cu")
		(net "GND")
		(uuid "4db4cb34-8191-4aef-a516-f67d3cc206c7")
	)
```
```sexpr
(via
		(at 140.911489 137.3169)
		(size 0.6)
		(drill 0.3)
		(layers "F.Cu" "B.Cu")
		(net "GND")
		(uuid "4ea98e69-f13a-4488-ae13-71f27bea0d40")
	)
```
```sexpr
(via
		(at 194.853075 133.764808)
		(size 0.6)
		(drill 0.3)
		(layers "F.Cu" "B.Cu")
		(net "GND")
		(uuid "602d2163-3cd6-47e0-9376-ac23dfb62a91")
	)
```
```sexpr
(via
		(at 156.8342 142.6202)
		(size 0.6)
		(drill 0.3)
		(layers "F.Cu" "B.Cu")
		(net "GND")
		(uuid "60e6a62d-734c-4d5e-926d-01a19d2b4f74")
	)
```
```sexpr
(via
		(at 148.6 144.5)
		(size 0.6)
		(drill 0.3)
		(layers "F.Cu" "B.Cu")
		(net "GND")
		(uuid "69f1b32a-4fe7-41b8-b7f1-85bb83ba1723")
	)
```
```sexpr
(via
		(at 48.245088 117.499354)
		(size 0.6)
		(drill 0.3)
		(layers "F.Cu" "B.Cu")
		(net "GND")
		(uuid "6ff9ea4e-f37b-4522-98d4-db0f570a8203")
	)
```
```sexpr
(via
		(at 181.9578 142.6482)
		(size 0.6)
		(drill 0.3)
		(layers "F.Cu" "B.Cu")
		(net "GND")
		(uuid "705f06d0-8209-4f7e-bb6d-f5db4eb43da8")
	)
```
```sexpr
(via
		(at 163.5811 129.8988)
		(size 0.6)
		(drill 0.3)
		(layers "F.Cu" "B.Cu")
		(net "GND")
		(uuid "86675eb5-2a4e-472a-b3cc-5bc109346220")
	)
```
```sexpr
(via
		(at 101.150688 137.5074)
		(size 0.6)
		(drill 0.3)
		(layers "F.Cu" "B.Cu")
		(net "GND")
		(uuid "99eff9d1-889a-4fa1-af10-0bf3fcac7533")
	)
```
```sexpr
(via
		(at 149 139.2)
		(size 0.6)
		(drill 0.3)
		(layers "F.Cu" "B.Cu")
		(net "GND")
		(uuid "ae8e6f39-0b39-42ba-9820-412287bc2050")
	)
```
### USB_DP
count 14
```sexpr
(segment
		(start 158.3581 145.0581)
		(end 158.3 145)
		(width 0.2)
		(layer "F.Cu")
		(net "USB_DP")
		(uuid "26806dad-e6b9-4372-a89b-c2c89118deb7")
	)
```
```sexpr
(segment
		(start 184.75 131.3104)
		(end 185.0819 131.6423)
		(width 0.2)
		(layer "F.Cu")
		(net "USB_DP")
		(uuid "5014ee68-bbe0-4bd8-ade1-6d9169d312d2")
	)
```
```sexpr
(segment
		(start 159.8926 145.0581)
		(end 158.3581 145.0581)
		(width 0.2)
		(layer "F.Cu")
		(net "USB_DP")
		(uuid "6f560cb6-1b0a-4a62-abec-8d271ab6a835")
	)
```
```sexpr
(segment
		(start 184.75 130.05)
		(end 184.75 131.3104)
		(width 0.2)
		(layer "F.Cu")
		(net "USB_DP")
		(uuid "c1c60d3b-6335-4f60-9172-b5482042c782")
	)
```
```sexpr
(via
		(at 161.5 143.4)
		(size 0.6)
		(drill 0.3)
		(layers "F.Cu" "B.Cu")
		(net "USB_DP")
		(uuid "0aecc3ef-2198-46d9-abad-60a47d805775")
	)
```
```sexpr
(via
		(at 185.0819 131.6423)
		(size 0.6)
		(drill 0.3)
		(layers "F.Cu" "B.Cu")
		(net "USB_DP")
		(uuid "5ca2683c-f6ef-4c17-9d7b-6d940193084a")
	)
```
```sexpr
(via
		(at 159.8926 145.0581)
		(size 0.6)
		(drill 0.3)
		(layers "F.Cu" "B.Cu")
		(net "USB_DP")
		(uuid "a49f6e26-14f0-402b-99b2-a90614247c65")
	)
```
```sexpr
(segment
		(start 179.9132 141.9029)
		(end 177.9772 141.9029)
		(width 0.2)
		(layer "B.Cu")
		(net "USB_DP")
		(uuid "1026dc58-264d-484d-905a-35fe384df8b0")
	)
```
```sexpr
(segment
		(start 162.6587 142.292)
		(end 159.8926 145.0581)
		(width 0.2)
		(layer "B.Cu")
		(net "USB_DP")
		(uuid "380d933e-778e-4fa8-a01c-933df49bf044")
	)
```
```sexpr
(segment
		(start 177.5882 142.2919)
		(end 177.5882 142.292)
		(width 0.2)
		(layer "B.Cu")
		(net "USB_DP")
		(uuid "7fbf2e1c-7f5a-4022-8bc6-31cc552832d8")
	)
```
```sexpr
(segment
		(start 185.0819 131.6423)
		(end 185.0819 136.7342)
		(width 0.2)
		(layer "B.Cu")
		(net "USB_DP")
		(uuid "988c70b2-3467-434e-836a-4f767f060083")
	)
```
```sexpr
(segment
		(start 185.0819 136.7342)
		(end 179.9132 141.9029)
		(width 0.2)
		(layer "B.Cu")
		(net "USB_DP")
		(uuid "9950100d-0541-42bd-b172-86096c943ba6")
	)
```
```sexpr
(segment
		(start 177.5882 142.292)
		(end 162.6587 142.292)
		(width 0.2)
		(layer "B.Cu")
		(net "USB_DP")
		(uuid "acd4b5d8-eb6a-419c-b0da-82f0e7a1105a")
	)
```
```sexpr
(segment
		(start 177.9772 141.9029)
		(end 177.5882 142.2919)
		(width 0.2)
		(layer "B.Cu")
		(net "USB_DP")
		(uuid "c08a0376-ee45-4c6f-899b-f300d0b2e675")
	)
```
### USB_DM
count 10
```sexpr
(segment
		(start 159.4806 133.0491)
		(end 163.5314 128.9983)
		(width 0.2)
		(layer "F.Cu")
		(net "USB_DM")
		(uuid "4a19e00d-2af4-48c8-b874-4f27a33305a7")
	)
```
```sexpr
(segment
		(start 158.4903 141.6903)
		(end 158.3 141.5)
		(width 0.2)
		(layer "F.Cu")
		(net "USB_DM")
		(uuid "85eb1869-0741-41ee-a288-81db19236391")
	)
```
```sexpr
(segment
		(start 163.5314 128.9983)
		(end 186.02 128.9983)
		(width 0.2)
		(layer "F.Cu")
		(net "USB_DM")
		(uuid "d2deb044-64ab-4368-af3b-6235b0f718bd")
	)
```
```sexpr
(segment
		(start 186.02 130.05)
		(end 186.02 128.9983)
		(width 0.2)
		(layer "F.Cu")
		(net "USB_DM")
		(uuid "d67bf549-ba9c-4ea0-8aa2-757482e2fb83")
	)
```
```sexpr
(segment
		(start 163.3817 141.6903)
		(end 158.4903 141.6903)
		(width 0.2)
		(layer "F.Cu")
		(net "USB_DM")
		(uuid "fe97b89b-ad25-4066-9b57-48ab4cc16dc2")
	)
```
```sexpr
(via
		(at 163.3817 141.6903)
		(size 0.6)
		(drill 0.3)
		(layers "F.Cu" "B.Cu")
		(net "USB_DM")
		(uuid "75a674c2-829f-4758-901f-a9b75761255e")
	)
```
```sexpr
(via
		(at 159.4806 133.0491)
		(size 0.6)
		(drill 0.3)
		(layers "F.Cu" "B.Cu")
		(net "USB_DM")
		(uuid "b49bf583-9641-4367-8964-478d8733e180")
	)
```
```sexpr
(segment
		(start 163.3817 141.6903)
		(end 159.4807 137.7893)
		(width 0.2)
		(layer "B.Cu")
		(net "USB_DM")
		(uuid "50bdbf82-ba6e-4d6a-8eaa-b8c2bd400620")
	)
```
```sexpr
(segment
		(start 159.4807 133.0491)
		(end 159.4806 133.0491)
		(width 0.2)
		(layer "B.Cu")
		(net "USB_DM")
		(uuid "6ef3c6a2-88ab-45bf-bdd2-2a3b9a889e76")
	)
```
```sexpr
(segment
		(start 159.4807 137.7893)
		(end 159.4807 133.0491)
		(width 0.2)
		(layer "B.Cu")
		(net "USB_DM")
		(uuid "d948e49d-af9a-44b1-af69-8ba6296b967b")
	)
```
### USB_DP_CONN
count 11
```sexpr
(segment
		(start 166.8776 140.2841)
		(end 156.6601 140.2841)
		(width 0.2)
		(layer "F.Cu")
		(net "USB_DP_CONN")
		(uuid "0264342c-ee05-4095-aeb4-67f9613b701f")
	)
```
```sexpr
(segment
		(start 169.29 143.615)
		(end 169.29 142.6965)
		(width 0.2)
		(layer "F.Cu")
		(net "USB_DP_CONN")
		(uuid "0f80f42a-fe0a-460f-b9bf-cc23c1588552")
	)
```
```sexpr
(segment
		(start 168.29 144.4007)
		(end 168.29 143.615)
		(width 0.2)
		(layer "F.Cu")
		(net "USB_DP_CONN")
		(uuid "140b4acd-123e-4815-8da9-67c8da7338b2")
	)
```
```sexpr
(segment
		(start 156.6601 140.2841)
		(end 155.9337 141.0105)
		(width 0.2)
		(layer "F.Cu")
		(net "USB_DP_CONN")
		(uuid "450a1901-057e-4a8c-b59f-941199e9c452")
	)
```
```sexpr
(segment
		(start 168.5395 144.6502)
		(end 168.29 144.4007)
		(width 0.2)
		(layer "F.Cu")
		(net "USB_DP_CONN")
		(uuid "53c74464-c569-47fa-b96b-7c261c1bb7a4")
	)
```
```sexpr
(segment
		(start 169.1024 144.6502)
		(end 168.5395 144.6502)
		(width 0.2)
		(layer "F.Cu")
		(net "USB_DP_CONN")
		(uuid "57a04a7a-64ce-4d19-88ef-db4cb313ae2e")
	)
```
```sexpr
(segment
		(start 169.29 142.6965)
		(end 166.8776 140.2841)
		(width 0.2)
		(layer "F.Cu")
		(net "USB_DP_CONN")
		(uuid "5e786959-1cc1-4218-bffc-1b702a6ba3b3")
	)
```
```sexpr
(segment
		(start 169.29 144.4626)
		(end 169.1024 144.6502)
		(width 0.2)
		(layer "F.Cu")
		(net "USB_DP_CONN")
		(uuid "5fd18cd7-b783-42ef-8b4c-111e6a731e77")
	)
```
```sexpr
(segment
		(start 155.9337 144.2337)
		(end 156.7 145)
		(width 0.2)
		(layer "F.Cu")
		(net "USB_DP_CONN")
		(uuid "9f6bf848-2ca8-4d26-960e-8aa04ec41f23")
	)
```
```sexpr
(segment
		(start 169.29 143.615)
		(end 169.29 144.4626)
		(width 0.2)
		(layer "F.Cu")
		(net "USB_DP_CONN")
		(uuid "9fda8d49-e165-4e8b-866c-5c0a9dd960e9")
	)
```
```sexpr
(segment
		(start 155.9337 141.0105)
		(end 155.9337 144.2337)
		(width 0.2)
		(layer "F.Cu")
		(net "USB_DP_CONN")
		(uuid "d2c340d0-7756-4a49-aed5-3686137f45b2")
	)
```
### USB_DM_CONN
count 8
```sexpr
(segment
		(start 165.6867 140.7197)
		(end 167.79 142.823)
		(width 0.2)
		(layer "F.Cu")
		(net "USB_DM_CONN")
		(uuid "118d9cc2-c992-43d1-9a80-c7b3bab521be")
	)
```
```sexpr
(segment
		(start 167.79 143.615)
		(end 167.79 142.823)
		(width 0.2)
		(layer "F.Cu")
		(net "USB_DM_CONN")
		(uuid "1c2f3033-7808-4ea9-a3f1-40241e712c06")
	)
```
```sexpr
(segment
		(start 167.79 142.823)
		(end 168.0674 142.5456)
		(width 0.2)
		(layer "F.Cu")
		(net "USB_DM_CONN")
		(uuid "69f2f73e-4574-4ad8-8ce5-d45dbb3a72fb")
	)
```
```sexpr
(segment
		(start 168.5191 142.5456)
		(end 168.79 142.8165)
		(width 0.2)
		(layer "F.Cu")
		(net "USB_DM_CONN")
		(uuid "aa257124-5328-49e9-a025-bd9de69eef2e")
	)
```
```sexpr
(segment
		(start 157.4803 140.7197)
		(end 165.6867 140.7197)
		(width 0.2)
		(layer "F.Cu")
		(net "USB_DM_CONN")
		(uuid "b537d886-7ec4-4d19-a901-c8810e41201f")
	)
```
```sexpr
(segment
		(start 168.0674 142.5456)
		(end 168.5191 142.5456)
		(width 0.2)
		(layer "F.Cu")
		(net "USB_DM_CONN")
		(uuid "cf48aea9-9db4-4dc8-8074-e3cd820d1593")
	)
```
```sexpr
(segment
		(start 156.7 141.5)
		(end 157.4803 140.7197)
		(width 0.2)
		(layer "F.Cu")
		(net "USB_DM_CONN")
		(uuid "eb027581-3d25-4d59-855d-81c53ff52cd4")
	)
```
```sexpr
(segment
		(start 168.79 142.8165)
		(end 168.79 143.615)
		(width 0.2)
		(layer "F.Cu")
		(net "USB_DM_CONN")
		(uuid "f9f6ca6e-53b2-47b3-8f4c-acf4cd73d6b8")
	)
```
### USB_CC1
count 4
```sexpr
(segment
		(start 167.29 143.615)
		(end 167.29 144.421)
		(width 0.2)
		(layer "F.Cu")
		(net "USB_CC1")
		(uuid "2e2c59dd-de85-4c1a-a8ba-ba1da7699094")
	)
```
```sexpr
(segment
		(start 177.7051 146.0051)
		(end 178.7 147)
		(width 0.2)
		(layer "F.Cu")
		(net "USB_CC1")
		(uuid "41e39144-f291-4ff8-b599-5bedf5fce1ba")
	)
```
```sexpr
(segment
		(start 168.8741 146.0051)
		(end 177.7051 146.0051)
		(width 0.2)
		(layer "F.Cu")
		(net "USB_CC1")
		(uuid "729f7878-f7c6-43bd-af73-30ab65409297")
	)
```
```sexpr
(segment
		(start 167.29 144.421)
		(end 168.8741 146.0051)
		(width 0.2)
		(layer "F.Cu")
		(net "USB_CC1")
		(uuid "ae127c0c-6581-409d-a761-e5053fc4b918")
	)
```
### USB_CC2
count 4
```sexpr
(segment
		(start 177.2758 142.5758)
		(end 178.7 144)
		(width 0.2)
		(layer "F.Cu")
		(net "USB_CC2")
		(uuid "188a14a9-6146-4a5c-b869-6ad9a1684215")
	)
```
```sexpr
(segment
		(start 170.29 142.8886)
		(end 170.6028 142.5758)
		(width 0.2)
		(layer "F.Cu")
		(net "USB_CC2")
		(uuid "522440a4-fb34-495d-b033-ec1146e7b24c")
	)
```
```sexpr
(segment
		(start 170.29 143.615)
		(end 170.29 142.8886)
		(width 0.2)
		(layer "F.Cu")
		(net "USB_CC2")
		(uuid "a003686b-5f2b-48a5-b174-7c28c9c3a820")
	)
```
```sexpr
(segment
		(start 170.6028 142.5758)
		(end 177.2758 142.5758)
		(width 0.2)
		(layer "F.Cu")
		(net "USB_CC2")
		(uuid "b3e09d7e-3526-45e0-8224-da6ec5710bee")
	)
```
### ESP_EN
count 24
```sexpr
(segment
		(start 51.3 114.363)
		(end 53.0149 116.0779)
		(width 0.2)
		(layer "F.Cu")
		(net "ESP_EN")
		(uuid "13cb30e3-3e75-40d4-b363-3f232c6478d0")
	)
```
```sexpr
(segment
		(start 123.3557 137.6557)
		(end 123.7 138)
		(width 0.2)
		(layer "F.Cu")
		(net "ESP_EN")
		(uuid "1a66f065-4207-401c-8d1e-858a7f0f5d90")
	)
```
```sexpr
(segment
		(start 186.481 131.9533)
		(end 186.7747 132.247)
		(width 0.2)
		(layer "F.Cu")
		(net "ESP_EN")
		(uuid "2bf6be86-5c38-40d1-8d0f-9c3c1c0df3ba")
	)
```
```sexpr
(segment
		(start 91.1435 137.3435)
		(end 91.8 138)
		(width 0.2)
		(layer "F.Cu")
		(net "ESP_EN")
		(uuid "59720cf1-455e-4103-8d78-3b76eed40873")
	)
```
```sexpr
(segment
		(start 198.72 130.05)
		(end 198.72 131.1017)
		(width 0.2)
		(layer "F.Cu")
		(net "ESP_EN")
		(uuid "6d84812c-27ff-4144-8cd3-da65f25bb3b5")
	)
```
```sexpr
(segment
		(start 197.5747 132.247)
		(end 198.72 131.1017)
		(width 0.2)
		(layer "F.Cu")
		(net "ESP_EN")
		(uuid "8c33bab6-bc97-4028-b069-e1b792810601")
	)
```
```sexpr
(segment
		(start 90.3231 137.3435)
		(end 91.1435 137.3435)
		(width 0.2)
		(layer "F.Cu")
		(net "ESP_EN")
		(uuid "b0107e25-f7c5-4fb3-abe5-3818bd8804a5")
	)
```
```sexpr
(segment
		(start 122.7902 137.6557)
		(end 123.3557 137.6557)
		(width 0.2)
		(layer "F.Cu")
		(net "ESP_EN")
		(uuid "b34a1ba5-411c-48c9-b7c0-0fe7a2a8a37c")
	)
```
```sexpr
(segment
		(start 53.0149 116.0779)
		(end 53.0149 116.2794)
		(width 0.2)
		(layer "F.Cu")
		(net "ESP_EN")
		(uuid "ccccd374-7a8f-4343-b224-03cfb5563c3e")
	)
```
```sexpr
(segment
		(start 186.7747 132.247)
		(end 197.5747 132.247)
		(width 0.2)
		(layer "F.Cu")
		(net "ESP_EN")
		(uuid "ee560f3c-1f8a-426d-9935-bb3ab291e8ec")
	)
```
```sexpr
(via
		(at 186.481 131.9533)
		(size 0.6)
		(drill 0.3)
		(layers "F.Cu" "B.Cu")
		(net "ESP_EN")
		(uuid "2ff988d7-2f90-43ab-9433-d1f87496bb05")
	)
```
```sexpr
(via
		(at 122.7902 137.6557)
		(size 0.6)
		(drill 0.3)
		(layers "F.Cu" "B.Cu")
		(net "ESP_EN")
		(uuid "901ddc99-3e9c-4259-bc25-2e39080397e5")
	)
```
```sexpr
(via
		(at 90.3231 137.3435)
		(size 0.6)
		(drill 0.3)
		(layers "F.Cu" "B.Cu")
		(net "ESP_EN")
		(uuid "c1492f68-2c60-45e2-b6f1-05b57dc1c073")
	)
```
```sexpr
(via
		(at 53.0149 116.2794)
		(size 0.6)
		(drill 0.3)
		(layers "F.Cu" "B.Cu")
		(net "ESP_EN")
		(uuid "dfc3e80b-499e-4a34-85f3-16f220ab7c4f")
	)
```
```sexpr
(segment
		(start 91.4522 138.4726)
		(end 90.3231 137.3435)
		(width 0.2)
		(layer "B.Cu")
		(net "ESP_EN")
		(uuid "36a3c125-aa90-42d8-9827-711fd4e59363")
	)
```
```sexpr
(segment
		(start 122.7902 137.6557)
		(end 131.6682 146.5337)
		(width 0.2)
		(layer "B.Cu")
		(net "ESP_EN")
		(uuid "444b86bd-51b6-4c77-8fed-d5444e7aa2cf")
	)
```
```sexpr
(segment
		(start 73.7631 137.3435)
		(end 90.3231 137.3435)
		(width 0.2)
		(layer "B.Cu")
		(net "ESP_EN")
		(uuid "5c81595d-969e-4eb9-a2cc-441d1e85dee1")
	)
```
```sexpr
(segment
		(start 186.481 136.5102)
		(end 186.481 131.9533)
		(width 0.2)
		(layer "B.Cu")
		(net "ESP_EN")
		(uuid "637e3ada-a7fe-4b86-ab6b-1225c74c7d16")
	)
```
```sexpr
(segment
		(start 176.4575 146.5337)
		(end 186.481 136.5102)
		(width 0.2)
		(layer "B.Cu")
		(net "ESP_EN")
		(uuid "63f2e90b-6036-42ee-b672-b9fac0e91f96")
	)
```
```sexpr
(segment
		(start 53.0149 116.5953)
		(end 73.7631 137.3435)
		(width 0.2)
		(layer "B.Cu")
		(net "ESP_EN")
		(uuid "a7e1554b-4931-4f8f-ad35-e1364c0c1d95")
	)
```
```sexpr
(segment
		(start 131.6682 146.5337)
		(end 176.4575 146.5337)
		(width 0.2)
		(layer "B.Cu")
		(net "ESP_EN")
		(uuid "b0e8455f-fc63-4b2a-9855-942d4e10ac37")
	)
```
```sexpr
(segment
		(start 121.9733 138.4726)
		(end 91.4522 138.4726)
		(width 0.2)
		(layer "B.Cu")
		(net "ESP_EN")
		(uuid "bc5bb4b1-6d18-4189-8d29-cdd48777da43")
	)
```
```sexpr
(segment
		(start 122.7902 137.6557)
		(end 121.9733 138.4726)
		(width 0.2)
		(layer "B.Cu")
		(net "ESP_EN")
		(uuid "d250ac65-f349-48b4-9a9c-b3222a83de0b")
	)
```
```sexpr
(segment
		(start 53.0149 116.2794)
		(end 53.0149 116.5953)
		(width 0.2)
		(layer "B.Cu")
		(net "ESP_EN")
		(uuid "ff67185c-9b04-48be-86ff-737d7f3b96a2")
	)
```
### BOOT_IO0
count 8
```sexpr
(segment
		(start 137.9646 146.4814)
		(end 176.9975 146.4814)
		(width 0.2)
		(layer "F.Cu")
		(net "BOOT_IO0")
		(uuid "3925a27e-61a3-47d7-ac2d-c0464fe80f88")
	)
```
```sexpr
(segment
		(start 130.7 139.2168)
		(end 130.7 138)
		(width 0.2)
		(layer "F.Cu")
		(net "BOOT_IO0")
		(uuid "5a726561-0a30-4701-b854-d9edf5166e5d")
	)
```
```sexpr
(segment
		(start 176.9975 146.4814)
		(end 179.1178 148.6017)
		(width 0.2)
		(layer "F.Cu")
		(net "BOOT_IO0")
		(uuid "9baab7ca-4b5e-41c7-8265-d783e867be19")
	)
```
```sexpr
(segment
		(start 130.7 139.2168)
		(end 101.0168 139.2168)
		(width 0.2)
		(layer "F.Cu")
		(net "BOOT_IO0")
		(uuid "a084a2a4-80fc-48c6-9004-d224415e7895")
	)
```
```sexpr
(segment
		(start 179.1178 148.6017)
		(end 184.75 148.6017)
		(width 0.2)
		(layer "F.Cu")
		(net "BOOT_IO0")
		(uuid "be692bd7-1bec-4e56-b6fd-bf8b9e5ff553")
	)
```
```sexpr
(segment
		(start 184.75 147.55)
		(end 184.75 148.6017)
		(width 0.2)
		(layer "F.Cu")
		(net "BOOT_IO0")
		(uuid "cbf685ef-09ac-4044-8a82-aedf5f4df183")
	)
```
```sexpr
(segment
		(start 101.0168 139.2168)
		(end 99.8 138)
		(width 0.2)
		(layer "F.Cu")
		(net "BOOT_IO0")
		(uuid "e56b339e-182a-4885-ad7f-debfc4949386")
	)
```
```sexpr
(segment
		(start 130.7 139.2168)
		(end 137.9646 146.4814)
		(width 0.2)
		(layer "F.Cu")
		(net "BOOT_IO0")
		(uuid "fe059769-6023-4a54-8890-7a3d0e6bab44")
	)
```
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

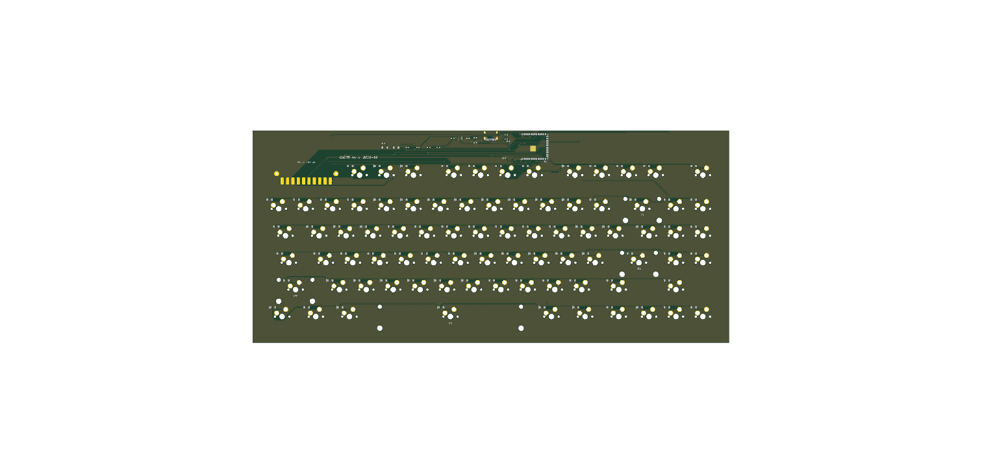
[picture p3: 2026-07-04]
hardware/kicad/oso75/renders/oso75-yflip-top.png

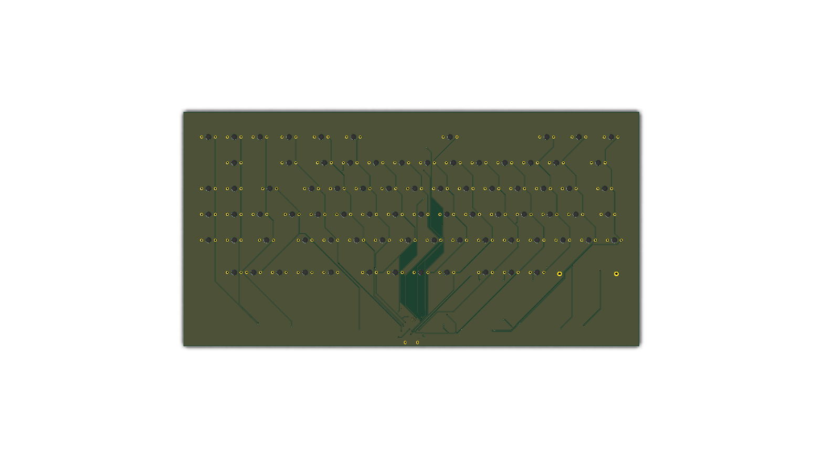
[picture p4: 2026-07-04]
hardware/kicad/oso75/renders/oso75-bottom.png

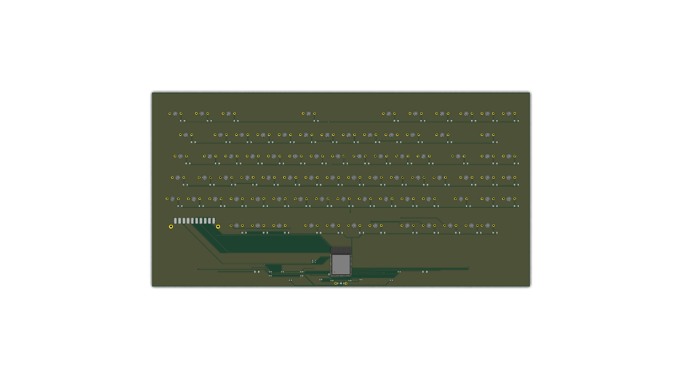
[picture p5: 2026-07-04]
hardware/kicad/oso75/renders/oso75-top.png

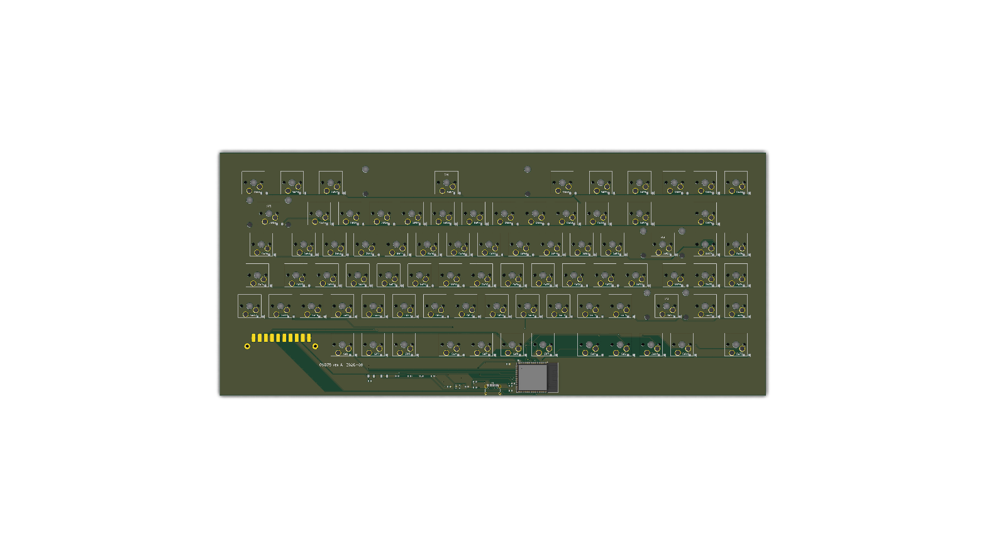
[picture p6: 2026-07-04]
hardware/kicad/oso75/renders/oso75-after-oracle-action-top.png

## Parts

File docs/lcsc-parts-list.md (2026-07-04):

# OSO75 LCSC Parts List

Pricing checked June 23, 2026. This list replaces the earlier Amazon-heavy
parts evidence with LCSC/JLCPCB-friendly parts for the PCB assembly pass.

| Item | Qty | LCSC part | MPN / match | Unit price used | Extended |
|---|---:|---|---|---:|---:|
| ESP32-S3-WROOM-1U-N16 module | 1 | C2980298 | ESP32-S3-WROOM-1U-N16 | $4.1237 | $4.12 |
| Kailh MX hotswap socket | 82 | C5156480 | CPG151101S11-16 | $0.0664 | $5.44 |
| USB-C receptacle | 1 | C165948 | TYPE-C-31-M-12 | $0.0960 | $0.10 |
| 3.3 V LDO | 1 | C51118 | AP2112K-3.3TRG1 | $0.0834 | $0.08 |
| 500 mA resettable fuse | 1 | C207014 | 0603L050SLYR | $0.2666 | $0.27 |
| Boot/reset tactile switches | 2 | C139797 | SKRPACE010 | $0.0623 | $0.12 |
| Matrix diodes | 82 | C81598 | 1N4148W SOD-123 | $0.0113 | $0.93 |
| 0603 resistors, capacitors, pullups | 13 | LCSC generic 0603 passives | 5.1k, 27R, 10k, 10uF, 100nF, 1uF | $0.0100 | $0.13 |

Estimated LCSC electronic component subtotal: **$11.19**.

Notes:

- `J3` OSO module bay is PCB copper only, so it is not bought as a component.
- The exact ESP32 variant matters: use `ESP32-S3-WROOM-1U-N16`, not N16R8/R16V.
- PCB fabrication, case fabrication, keycaps, switches, stabilizers, screws, feet,
  antenna pigtail, and shipping are separate mechanical/build costs.
- Current repo file map for reviewers:
  - PCB: `hardware/kicad/oso75/oso75.kicad_pcb`
  - Schematic: `hardware/kicad/oso75/oso75.kicad_sch`
  - CAD source: `hardware/cad/build123d/oso75_case.py`
  - Split case STEP/STL: `hardware/cad/build123d/oso75_case_bottom.*` and
    `hardware/cad/build123d/oso75_case_bezel.*`

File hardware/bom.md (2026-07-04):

# OSO75 Initial BOM

This BOM is split between parts we want assembled on the PCB and parts the builder
installs manually.

## PCB Factory Assembly

| Qty | Part | Notes |
|---:|---|---|
| 1 | ESP32-S3-WROOM-1U-N16 | Main MCU module with native USB, Wi-Fi, BLE, 16 MB flash, and external IPEX antenna connector |
| 1 | 2.4 GHz IPEX/u.FL antenna | Required only for BLE/Wi-Fi range; wired USB works without it |
| 82 | 1N4148W SOD-123 diodes | One per physical switch; pad 1/cathode band faces ROW net |
| 1 | USB-C receptacle | USB 2.0 device wiring |
| 1 | Exposed OSO module bay pads | PCB copper only; no factory connector fitted, no paste |
| 1 | Littelfuse 0603L050SLYR PPTC fuse | Protects optional 5 V accessory modules |
| 2 | 5.1k 0603 resistors | USB-C device mode CC pulldowns |
| 2 | 27R 0603 resistors | USB D+/D- series resistors |
| 3 | 10k 0603 resistors | EN, BOOT, and module interrupt/present pullups |
| 2 | 10uF 10V 0603 capacitors | LDO input/output bulk caps |
| 2 | 100nF 0603 capacitors | ESP32 local decoupling |
| 1 | 1uF 0603 capacitor | ESP_EN reset delay |
| 1 | Reset tactile switch | Pulls EN low |
| 1 | Boot tactile switch | Pulls GPIO0 low for ROM download mode |

## Builder Assembly

| Qty | Part | Current pick |
|---:|---|---|
| 82 required, 90 suggested | MX switches | Gateron Milky Yellow Pro V3 or MMD Princess V4 |
| 82 | Kailh MX hotswap sockets | Only if not factory assembled |
| 1 set | PCB screw-in stabilizers | 6.25u + 2u set |
| 1 | Plate | Production file: `hardware/cad/build123d/oso75_plate.step` / `.stl`; use 1.5 mm metal/FR4/POM for the final |
| 1 | Case | Production files: `hardware/cad/build123d/oso75_case_bottom.step` + `oso75_case_bezel.step`; OpenSCAD files are deprecated concept previews only |
| 1 | USB-C cable | Data-capable cable |

## Optional OSO Bay Modules

| Module idea | Main parts |
|---|---|
| Volume knob | Rotary encoder, knob, small module PCB |
| OLED status screen | 0.91-1.3 inch I2C OLED, module PCB |
| Slider/macropanel | Potentiometer or linear Hall sensor, module PCB |
| LED widget | Addressable LEDs with current limiting |

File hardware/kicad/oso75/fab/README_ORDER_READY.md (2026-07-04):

# OSO75 Order-Ready Fab Files (v2)

**Order this package only:**

- `oso75_order_ready_v2_gerbers.zip` (exported 2026-06-10 after the y-flip fix)

**Do NOT order anything prefixed `STALE-MIRRORED-DO-NOT-ORDER-`.** Every
package exported before 2026-06-10 19:00 describes a mirror-image keyboard
(`~` on the right, Enter on the left). The board was y-flipped, re-routed,
and re-verified; only the v2 package is buildable.

Recommended PCB options:

- Board type: single PCB, not panelized
- Size: 337.088 mm x 150.063 mm
- Layers: 2
- Thickness: 1.6 mm
- Copper: 1 oz
- Minimum track/spacing: 6/6 mil or better
- Minimum hole: 0.3 mm or better
- Surface finish: ENIG recommended. Hard gold is better if the OSO module bay
  will be swapped often.
- Solder mask/silkscreen: any color is OK.
- Castellated holes / edge connector: no
- Assembly: optional, see below

Assembly notes:

- `J3` is exposed module-bay copper only. It must not be placed as a component
  and must not receive paste.
- Rev A module bay is power-off swap only. Do not insert/remove modules while
  the keyboard is powered.
- `U1` must be exactly `ESP32-S3-WROOM-1U-N16`. Do not substitute
  N16R8/R16V/Octal-PSRAM variants.
- `oso75_order_ready_bom_no_hotswap.csv` excludes Kailh hotswap sockets for
  hand soldering (BOM is unchanged by the flip and still valid).
- `oso75_order_ready_bom_with_hotswap.csv` includes Kailh hotswap sockets for
  factory assembly.
- `oso75_order_ready_v2_pos.csv` is the position/CPL export for the flipped
  board. The older `oso75_order_ready_pos.csv` is stale; do not use it.
- Review rotations in the fab's preview before paying.

Verification (v2, after the y-flip):

- KiCad 10.0.3 DRC: 0 errors, 0 unconnected items
  (`drc-yflip-12.json`); remaining warnings are library lookup notices for
  project-local footprints only.
- Drill files reconcile with the board exactly: 265 PTH (180 pads + 85 vias),
  266 NPTH (164 switch fixation, 82 switch centers, 16 stabilizer, 4 other).
- Orientation verified against the annovax75 reference convention and the CAD
  model: top render shows USB/ESP32 band and module bay at the back-left,
  F-row beneath it, space row at the front; `~` left, Enter right.

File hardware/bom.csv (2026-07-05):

category | quantity | part | mpn_or_spec | supplier | purchase_url | notes
PCB factory assembly | 1 | ESP32-S3-WROOM-1U-N16 module | ESP32-S3-WROOM-1U-N16 | LCSC | https://www.lcsc.com/search?q=C2980298 | Main MCU module with native USB Wi-Fi BLE 16 MB flash and external IPEX antenna connector
PCB factory assembly | 1 | 2.4 GHz IPEX/u.FL antenna | 2.4 GHz IPEX/u.FL antenna | LCSC | https://www.lcsc.com/search?q=ipex%202.4ghz%20antenna | Required only for BLE/Wi-Fi range; wired USB works without it
PCB factory assembly | 82 | 1N4148W SOD-123 diode | 1N4148W | LCSC | https://www.lcsc.com/search?q=C81598 | One diode per switch; cathode band faces ROW net
PCB factory assembly | 1 | USB-C receptacle | HRO TYPE-C-31-M-12 | LCSC | https://www.lcsc.com/search?q=C165948 | USB 2.0 device connector
PCB factory assembly | 1 | OSO module bay exposed pads | DNP PCB copper only | JLCPCB | https://jlcpcb.com/ | Exposed ENIG PCB pads only; no placed component or paste
PCB factory assembly | 1 | 500 mA resettable fuse | Littelfuse 0603L050SLYR | LCSC | https://www.lcsc.com/search?q=C207014 | Protects optional 5 V module bay rail
PCB factory assembly | 2 | 5.1k 0603 resistor | 5.1k 0603 | LCSC | https://www.lcsc.com/search?q=5.1k%200603%20resistor | USB-C CC pulldowns
PCB factory assembly | 2 | 27R 0603 resistor | 27R 0603 | LCSC | https://www.lcsc.com/search?q=27R%200603%20resistor | USB D+ and D- series resistors
PCB factory assembly | 3 | 10k 0603 resistor | 10k 0603 | LCSC | https://www.lcsc.com/search?q=10k%200603%20resistor | EN BOOT and module interrupt/present pullups
PCB factory assembly | 2 | 10uF 10V 0603 capacitor | 10uF 10V 0603 | LCSC | https://www.lcsc.com/search?q=10uF%2010V%200603%20capacitor | LDO input/output bulk capacitors
PCB factory assembly | 2 | 100nF 0603 capacitor | 100nF 0603 | LCSC | https://www.lcsc.com/search?q=100nF%200603%20capacitor | ESP32 local decoupling
PCB factory assembly | 1 | 1uF 0603 capacitor | 1uF 0603 | LCSC | https://www.lcsc.com/search?q=1uF%200603%20capacitor | ESP_EN reset delay capacitor
PCB factory assembly | 1 | Reset tactile switch | SKRPACE010 | LCSC | https://www.lcsc.com/search?q=C139797 | Pulls EN low
PCB factory assembly | 1 | Boot tactile switch | SKRPACE010 | LCSC | https://www.lcsc.com/search?q=C139797 | Pulls GPIO0 low for ROM download mode
Builder assembly | 82 | MX mechanical switch | Gateron Milky Yellow Pro V3 or compatible | AliExpress | https://www.aliexpress.com/wholesale?SearchText=Gateron+Milky+Yellow+Pro+V3 | Builder-installed switches
Builder assembly | 82 | Kailh MX hotswap socket | CPG151101S11-16 | LCSC | https://www.lcsc.com/search?q=C5156480 | Only needed if sockets are not factory assembled
Builder assembly | 1 | PCB screw-in stabilizer set | 6.25u + 2u set | AliExpress | https://www.aliexpress.com/wholesale?SearchText=PCB+screw+in+stabilizer+6.25u | Backspace Enter LShift and Space stabilizers
Builder assembly | 1 | Switch plate | 1.5 mm plate from OSO75 STEP/STL | JLCPCB | https://jlcpcb.com/3d-printing | Use hardware/cad/build123d/oso75_plate.step or .stl
Builder assembly | 1 | Case bottom | OSO75 case bottom STEP/STL | JLCPCB | https://jlcpcb.com/3d-printing | Use hardware/cad/build123d/oso75_case_bottom.step or .stl
Builder assembly | 1 | Case bezel | OSO75 case bezel STEP/STL | JLCPCB | https://jlcpcb.com/3d-printing | Use hardware/cad/build123d/oso75_case_bezel.step or .stl
Builder assembly | 1 | USB-C cable | USB-C data cable | Amazon | https://www.amazon.com/s?k=usb+c+data+cable | Data-capable cable for firmware and keyboard use
Optional module | 1 | Rotary encoder module parts | EC11 encoder + knob + small PCB | LCSC | https://www.lcsc.com/search?q=EC11%20rotary%20encoder | Optional OSO module bay accessory
Optional module | 1 | I2C OLED module | 0.91-1.3 inch I2C OLED | LCSC | https://www.lcsc.com/search?q=I2C%20OLED | Optional OSO module bay accessory

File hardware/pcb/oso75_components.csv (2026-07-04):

ref | value | footprint | mpn | assembly | notes
U1 | ESP32-S3-WROOM-1U-N16 | RF module with external IPEX antenna | ESP32-S3-WROOM-1U-N16 | factory | Main MCU module with native USB, Wi-Fi, BLE, 16 MB flash, and external antenna connector; do not substitute N16R8/R16V/Octal-PSRAM variants
U3 | 3.3 V LDO | SOT-23-5 | AP2112K-3.3TRG1 | factory | USB 5 V to 3.3 V
J1 | USB-C receptacle | USB-C-16P-SMD | HRO TYPE-C-31-M-12 | factory | USB 2.0 device port
J3 | OSO module bay PCB pads | exposed ENIG pads + 2 retention holes | DNP - PCB copper only | DNP | Keyboard side of the module bay; power-off swap only in rev A; removable modules provide spring contacts
F1 | 500mA resettable fuse | 0603 PPTC | Littelfuse 0603L050SLYR | factory | 6 V 500 mA hold resettable fuse for optional module-bay 5 V
SW_BOOT | Boot tactile switch | SMD tactile | SKRPACE010 | factory | Pull GPIO0 low for ROM download mode
SW_RESET | Reset tactile switch | SMD tactile | SKRPACE010 | factory | Pull EN low
R1 | 5.1k | 0603 | generic | factory | USB-C CC1 pulldown
R2 | 5.1k | 0603 | generic | factory | USB-C CC2 pulldown
R3 | 27R | 0603 | generic | factory | USB D+ series
R4 | 27R | 0603 | generic | factory | USB D- series
R5 | 10k | 0603 | generic | factory | ESP_EN pullup
R6 | 10k | 0603 | generic | factory | GPIO0 boot pullup
R10 | 10k | 0603 | generic | factory | Module present/interrupt pullup
C1 | 10uF 10V | 0603 | generic X5R/X7R | factory | LDO input; footprint is 0603 only
C2 | 10uF 10V | 0603 | generic X5R/X7R | factory | LDO output; footprint is 0603 only
C3 | 100nF | 0603 | generic X7R | factory | ESP32 local decoupling
C4 | 100nF | 0603 | generic X7R | factory | ESP32 local decoupling
C_EN | 1uF | 0603 | generic X5R/X7R | factory | ESP_EN reset delay capacitor
SW1 | MX hotswap socket | Kailh MX hotswap | CPG151101S11 | builder or factory | F2 switch
D1 | 1N4148W | SOD-123 | 1N4148W | factory | F2 anti-ghosting diode; pad 1/cathode band faces ROW net
SW2 | MX hotswap socket | Kailh MX hotswap | CPG151101S11 | builder or factory | F3 switch
D2 | 1N4148W | SOD-123 | 1N4148W | factory | F3 anti-ghosting diode; pad 1/cathode band faces ROW net
SW3 | MX hotswap socket | Kailh MX hotswap | CPG151101S11 | builder or factory | F4 switch
D3 | 1N4148W | SOD-123 | 1N4148W | factory | F4 anti-ghosting diode; pad 1/cathode band faces ROW net
SW4 | MX hotswap socket | Kailh MX hotswap | CPG151101S11 | builder or factory | F5 switch
D4 | 1N4148W | SOD-123 | 1N4148W | factory | F5 anti-ghosting diode; pad 1/cathode band faces ROW net
SW5 | MX hotswap socket | Kailh MX hotswap | CPG151101S11 | builder or factory | F6 switch
D5 | 1N4148W | SOD-123 | 1N4148W | factory | F6 anti-ghosting diode; pad 1/cathode band faces ROW net
SW6 | MX hotswap socket | Kailh MX hotswap | CPG151101S11 | builder or factory | F7 switch
D6 | 1N4148W | SOD-123 | 1N4148W | factory | F7 anti-ghosting diode; pad 1/cathode band faces ROW net
SW7 | MX hotswap socket | Kailh MX hotswap | CPG151101S11 | builder or factory | F8 switch
D7 | 1N4148W | SOD-123 | 1N4148W | factory | F8 anti-ghosting diode; pad 1/cathode band faces ROW net
SW8 | MX hotswap socket | Kailh MX hotswap | CPG151101S11 | builder or factory | F9 switch
D8 | 1N4148W | SOD-123 | 1N4148W | factory | F9 anti-ghosting diode; pad 1/cathode band faces ROW net
SW9 | MX hotswap socket | Kailh MX hotswap | CPG151101S11 | builder or factory | F10 switch
D9 | 1N4148W | SOD-123 | 1N4148W | factory | F10 anti-ghosting diode; pad 1/cathode band faces ROW net
SW10 | MX hotswap socket | Kailh MX hotswap | CPG151101S11 | builder or factory | F11 switch
D10 | 1N4148W | SOD-123 | 1N4148W | factory | F11 anti-ghosting diode; pad 1/cathode band faces ROW net
SW11 | MX hotswap socket | Kailh MX hotswap | CPG151101S11 | builder or factory | F12 switch
D11 | 1N4148W | SOD-123 | 1N4148W | factory | F12 anti-ghosting diode; pad 1/cathode band faces ROW net
SW12 | MX hotswap socket | Kailh MX hotswap | CPG151101S11 | builder or factory | ` switch
D12 | 1N4148W | SOD-123 | 1N4148W | factory | ` anti-ghosting diode; pad 1/cathode band faces ROW net
SW13 | MX hotswap socket | Kailh MX hotswap | CPG151101S11 | builder or factory | 1 switch
D13 | 1N4148W | SOD-123 | 1N4148W | factory | 1 anti-ghosting diode; pad 1/cathode band faces ROW net
SW14 | MX hotswap socket | Kailh MX hotswap | CPG151101S11 | builder or factory | 2 switch
D14 | 1N4148W | SOD-123 | 1N4148W | factory | 2 anti-ghosting diode; pad 1/cathode band faces ROW net
SW15 | MX hotswap socket | Kailh MX hotswap | CPG151101S11 | builder or factory | 3 switch
D15 | 1N4148W | SOD-123 | 1N4148W | factory | 3 anti-ghosting diode; pad 1/cathode band faces ROW net
SW16 | MX hotswap socket | Kailh MX hotswap | CPG151101S11 | builder or factory | 4 switch
D16 | 1N4148W | SOD-123 | 1N4148W | factory | 4 anti-ghosting diode; pad 1/cathode band faces ROW net
SW17 | MX hotswap socket | Kailh MX hotswap | CPG151101S11 | builder or factory | 5 switch
D17 | 1N4148W | SOD-123 | 1N4148W | factory | 5 anti-ghosting diode; pad 1/cathode band faces ROW net
SW18 | MX hotswap socket | Kailh MX hotswap | CPG151101S11 | builder or factory | 6 switch
D18 | 1N4148W | SOD-123 | 1N4148W | factory | 6 anti-ghosting diode; pad 1/cathode band faces ROW net
SW19 | MX hotswap socket | Kailh MX hotswap | CPG151101S11 | builder or factory | 7 switch
D19 | 1N4148W | SOD-123 | 1N4148W | factory | 7 anti-ghosting diode; pad 1/cathode band faces ROW net
SW20 | MX hotswap socket | Kailh MX hotswap | CPG151101S11 | builder or factory | 8 switch
D20 | 1N4148W | SOD-123 | 1N4148W | factory | 8 anti-ghosting diode; pad 1/cathode band faces ROW net
SW21 | MX hotswap socket | Kailh MX hotswap | CPG151101S11 | builder or factory | 9 switch
D21 | 1N4148W | SOD-123 | 1N4148W | factory | 9 anti-ghosting diode; pad 1/cathode band faces ROW net
SW22 | MX hotswap socket | Kailh MX hotswap | CPG151101S11 | builder or factory | 0 switch
D22 | 1N4148W | SOD-123 | 1N4148W | factory | 0 anti-ghosting diode; pad 1/cathode band faces ROW net
SW23 | MX hotswap socket | Kailh MX hotswap | CPG151101S11 | builder or factory | - switch
D23 | 1N4148W | SOD-123 | 1N4148W | factory | - anti-ghosting diode; pad 1/cathode band faces ROW net
SW24 | MX hotswap socket | Kailh MX hotswap | CPG151101S11 | builder or factory | = switch
D24 | 1N4148W | SOD-123 | 1N4148W | factory | = anti-ghosting diode; pad 1/cathode band faces ROW net
SW25 | MX hotswap socket | Kailh MX hotswap | CPG151101S11 | builder or factory | Backspace switch
D25 | 1N4148W | SOD-123 | 1N4148W | factory | Backspace anti-ghosting diode; pad 1/cathode band faces ROW net
SW26 | MX hotswap socket | Kailh MX hotswap | CPG151101S11 | builder or factory | Tab switch
D26 | 1N4148W | SOD-123 | 1N4148W | factory | Tab anti-ghosting diode; pad 1/cathode band faces ROW net
SW27 | MX hotswap socket | Kailh MX hotswap | CPG151101S11 | builder or factory | Q switch
D27 | 1N4148W | SOD-123 | 1N4148W | factory | Q anti-ghosting diode; pad 1/cathode band faces ROW net
SW28 | MX hotswap socket | Kailh MX hotswap | CPG151101S11 | builder or factory | W switch
D28 | 1N4148W | SOD-123 | 1N4148W | factory | W anti-ghosting diode; pad 1/cathode band faces ROW net
SW29 | MX hotswap socket | Kailh MX hotswap | CPG151101S11 | builder or factory | E switch
D29 | 1N4148W | SOD-123 | 1N4148W | factory | E anti-ghosting diode; pad 1/cathode band faces ROW net
SW30 | MX hotswap socket | Kailh MX hotswap | CPG151101S11 | builder or factory | R switch
D30 | 1N4148W | SOD-123 | 1N4148W | factory | R anti-ghosting diode; pad 1/cathode band faces ROW net
SW31 | MX hotswap socket | Kailh MX hotswap | CPG151101S11 | builder or factory | T switch
D31 | 1N4148W | SOD-123 | 1N4148W | factory | T anti-ghosting diode; pad 1/cathode band faces ROW net
SW32 | MX hotswap socket | Kailh MX hotswap | CPG151101S11 | builder or factory | Y switch
D32 | 1N4148W | SOD-123 | 1N4148W | factory | Y anti-ghosting diode; pad 1/cathode band faces ROW net
SW33 | MX hotswap socket | Kailh MX hotswap | CPG151101S11 | builder or factory | U switch
D33 | 1N4148W | SOD-123 | 1N4148W | factory | U anti-ghosting diode; pad 1/cathode band faces ROW net
SW34 | MX hotswap socket | Kailh MX hotswap | CPG151101S11 | builder or factory | I switch
D34 | 1N4148W | SOD-123 | 1N4148W | factory | I anti-ghosting diode; pad 1/cathode band faces ROW net
SW35 | MX hotswap socket | Kailh MX hotswap | CPG151101S11 | builder or factory | O switch
D35 | 1N4148W | SOD-123 | 1N4148W | factory | O anti-ghosting diode; pad 1/cathode band faces ROW net
SW36 | MX hotswap socket | Kailh MX hotswap | CPG151101S11 | builder or factory | P switch
D36 | 1N4148W | SOD-123 | 1N4148W | factory | P anti-ghosting diode; pad 1/cathode band faces ROW net
SW37 | MX hotswap socket | Kailh MX hotswap | CPG151101S11 | builder or factory | [ switch
D37 | 1N4148W | SOD-123 | 1N4148W | factory | [ anti-ghosting diode; pad 1/cathode band faces ROW net
SW38 | MX hotswap socket | Kailh MX hotswap | CPG151101S11 | builder or factory | ] switch
D38 | 1N4148W | SOD-123 | 1N4148W | factory | ] anti-ghosting diode; pad 1/cathode band faces ROW net
SW39 | MX hotswap socket | Kailh MX hotswap | CPG151101S11 | builder or factory | \ switch
D39 | 1N4148W | SOD-123 | 1N4148W | factory | \ anti-ghosting diode; pad 1/cathode band faces ROW net
SW40 | MX hotswap socket | Kailh MX hotswap | CPG151101S11 | builder or factory | Caps switch
D40 | 1N4148W | SOD-123 | 1N4148W | factory | Caps anti-ghosting diode; pad 1/cathode band faces ROW net
SW41 | MX hotswap socket | Kailh MX hotswap | CPG151101S11 | builder or factory | A switch
D41 | 1N4148W | SOD-123 | 1N4148W | factory | A anti-ghosting diode; pad 1/cathode band faces ROW net
SW42 | MX hotswap socket | Kailh MX hotswap | CPG151101S11 | builder or factory | S switch
D42 | 1N4148W | SOD-123 | 1N4148W | factory | S anti-ghosting diode; pad 1/cathode band faces ROW net
SW43 | MX hotswap socket | Kailh MX hotswap | CPG151101S11 | builder or factory | D switch
D43 | 1N4148W | SOD-123 | 1N4148W | factory | D anti-ghosting diode; pad 1/cathode band faces ROW net
SW44 | MX hotswap socket | Kailh MX hotswap | CPG151101S11 | builder or factory | F switch
D44 | 1N4148W | SOD-123 | 1N4148W | factory | F anti-ghosting diode; pad 1/cathode band faces ROW net
SW45 | MX hotswap socket | Kailh MX hotswap | CPG151101S11 | builder or factory | G switch
D45 | 1N4148W | SOD-123 | 1N4148W | factory | G anti-ghosting diode; pad 1/cathode band faces ROW net
SW46 | MX hotswap socket | Kailh MX hotswap | CPG151101S11 | builder or factory | H switch
D46 | 1N4148W | SOD-123 | 1N4148W | factory | H anti-ghosting diode; pad 1/cathode band faces ROW net
SW47 | MX hotswap socket | Kailh MX hotswap | CPG151101S11 | builder or factory | J switch
D47 | 1N4148W | SOD-123 | 1N4148W | factory | J anti-ghosting diode; pad 1/cathode band faces ROW net
SW48 | MX hotswap socket | Kailh MX hotswap | CPG151101S11 | builder or factory | K switch
D48 | 1N4148W | SOD-123 | 1N4148W | factory | K anti-ghosting diode; pad 1/cathode band faces ROW net
SW49 | MX hotswap socket | Kailh MX hotswap | CPG151101S11 | builder or factory | L switch
D49 | 1N4148W | SOD-123 | 1N4148W | factory | L anti-ghosting diode; pad 1/cathode band faces ROW net
SW50 | MX hotswap socket | Kailh MX hotswap | CPG151101S11 | builder or factory | ; switch
D50 | 1N4148W | SOD-123 | 1N4148W | factory | ; anti-ghosting diode; pad 1/cathode band faces ROW net
SW51 | MX hotswap socket | Kailh MX hotswap | CPG151101S11 | builder or factory | ' switch
D51 | 1N4148W | SOD-123 | 1N4148W | factory | ' anti-ghosting diode; pad 1/cathode band faces ROW net
SW52 | MX hotswap socket | Kailh MX hotswap | CPG151101S11 | builder or factory | Enter switch
D52 | 1N4148W | SOD-123 | 1N4148W | factory | Enter anti-ghosting diode; pad 1/cathode band faces ROW net
SW53 | MX hotswap socket | Kailh MX hotswap | CPG151101S11 | builder or factory | LShift switch
D53 | 1N4148W | SOD-123 | 1N4148W | factory | LShift anti-ghosting diode; pad 1/cathode band faces ROW net
SW54 | MX hotswap socket | Kailh MX hotswap | CPG151101S11 | builder or factory | Z switch
D54 | 1N4148W | SOD-123 | 1N4148W | factory | Z anti-ghosting diode; pad 1/cathode band faces ROW net
SW55 | MX hotswap socket | Kailh MX hotswap | CPG151101S11 | builder or factory | X switch
D55 | 1N4148W | SOD-123 | 1N4148W | factory | X anti-ghosting diode; pad 1/cathode band faces ROW net
SW56 | MX hotswap socket | Kailh MX hotswap | CPG151101S11 | builder or factory | C switch
D56 | 1N4148W | SOD-123 | 1N4148W | factory | C anti-ghosting diode; pad 1/cathode band faces ROW net
SW57 | MX hotswap socket | Kailh MX hotswap | CPG151101S11 | builder or factory | V switch
D57 | 1N4148W | SOD-123 | 1N4148W | factory | V anti-ghosting diode; pad 1/cathode band faces ROW net
SW58 | MX hotswap socket | Kailh MX hotswap | CPG151101S11 | builder or factory | B switch
D58 | 1N4148W | SOD-123 | 1N4148W | factory | B anti-ghosting diode; pad 1/cathode band faces ROW net
SW59 | MX hotswap socket | Kailh MX hotswap | CPG151101S11 | builder or factory | N switch
D59 | 1N4148W | SOD-123 | 1N4148W | factory | N anti-ghosting diode; pad 1/cathode band faces ROW net
SW60 | MX hotswap socket | Kailh MX hotswap | CPG151101S11 | builder or factory | M switch
D60 | 1N4148W | SOD-123 | 1N4148W | factory | M anti-ghosting diode; pad 1/cathode band faces ROW net
SW61 | MX hotswap socket | Kailh MX hotswap | CPG151101S11 | builder or factory | , switch
D61 | 1N4148W | SOD-123 | 1N4148W | factory | , anti-ghosting diode; pad 1/cathode band faces ROW net
SW62 | MX hotswap socket | Kailh MX hotswap | CPG151101S11 | builder or factory | . switch
D62 | 1N4148W | SOD-123 | 1N4148W | factory | . anti-ghosting diode; pad 1/cathode band faces ROW net
SW63 | MX hotswap socket | Kailh MX hotswap | CPG151101S11 | builder or factory | / switch
D63 | 1N4148W | SOD-123 | 1N4148W | factory | / anti-ghosting diode; pad 1/cathode band faces ROW net
SW64 | MX hotswap socket | Kailh MX hotswap | CPG151101S11 | builder or factory | RShift switch
D64 | 1N4148W | SOD-123 | 1N4148W | factory | RShift anti-ghosting diode; pad 1/cathode band faces ROW net
SW65 | MX hotswap socket | Kailh MX hotswap | CPG151101S11 | builder or factory | LCtrl switch
D65 | 1N4148W | SOD-123 | 1N4148W | factory | LCtrl anti-ghosting diode; pad 1/cathode band faces ROW net
SW66 | MX hotswap socket | Kailh MX hotswap | CPG151101S11 | builder or factory | LGUI switch
D66 | 1N4148W | SOD-123 | 1N4148W | factory | LGUI anti-ghosting diode; pad 1/cathode band faces ROW net
SW67 | MX hotswap socket | Kailh MX hotswap | CPG151101S11 | builder or factory | LAlt switch
D67 | 1N4148W | SOD-123 | 1N4148W | factory | LAlt anti-ghosting diode; pad 1/cathode band faces ROW net
SW68 | MX hotswap socket | Kailh MX hotswap | CPG151101S11 | builder or factory | Space switch
D68 | 1N4148W | SOD-123 | 1N4148W | factory | Space anti-ghosting diode; pad 1/cathode band faces ROW net
SW69 | MX hotswap socket | Kailh MX hotswap | CPG151101S11 | builder or factory | RAlt switch
D69 | 1N4148W | SOD-123 | 1N4148W | factory | RAlt anti-ghosting diode; pad 1/cathode band faces ROW net
SW70 | MX hotswap socket | Kailh MX hotswap | CPG151101S11 | builder or factory | Fn switch
D70 | 1N4148W | SOD-123 | 1N4148W | factory | Fn anti-ghosting diode; pad 1/cathode band faces ROW net
SW71 | MX hotswap socket | Kailh MX hotswap | CPG151101S11 | builder or factory | RCtrl switch
D71 | 1N4148W | SOD-123 | 1N4148W | factory | RCtrl anti-ghosting diode; pad 1/cathode band faces ROW net
SW72 | MX hotswap socket | Kailh MX hotswap | CPG151101S11 | builder or factory | PrtSc switch
D72 | 1N4148W | SOD-123 | 1N4148W | factory | PrtSc anti-ghosting diode; pad 1/cathode band faces ROW net
SW73 | MX hotswap socket | Kailh MX hotswap | CPG151101S11 | builder or factory | Ins switch
D73 | 1N4148W | SOD-123 | 1N4148W | factory | Ins anti-ghosting diode; pad 1/cathode band faces ROW net
SW74 | MX hotswap socket | Kailh MX hotswap | CPG151101S11 | builder or factory | Home switch
D74 | 1N4148W | SOD-123 | 1N4148W | factory | Home anti-ghosting diode; pad 1/cathode band faces ROW net
SW75 | MX hotswap socket | Kailh MX hotswap | CPG151101S11 | builder or factory | PgUp switch
D75 | 1N4148W | SOD-123 | 1N4148W | factory | PgUp anti-ghosting diode; pad 1/cathode band faces ROW net
SW76 | MX hotswap socket | Kailh MX hotswap | CPG151101S11 | builder or factory | Del switch
D76 | 1N4148W | SOD-123 | 1N4148W | factory | Del anti-ghosting diode; pad 1/cathode band faces ROW net
SW77 | MX hotswap socket | Kailh MX hotswap | CPG151101S11 | builder or factory | End switch
D77 | 1N4148W | SOD-123 | 1N4148W | factory | End anti-ghosting diode; pad 1/cathode band faces ROW net
SW78 | MX hotswap socket | Kailh MX hotswap | CPG151101S11 | builder or factory | PgDn switch
D78 | 1N4148W | SOD-123 | 1N4148W | factory | PgDn anti-ghosting diode; pad 1/cathode band faces ROW net
SW79 | MX hotswap socket | Kailh MX hotswap | CPG151101S11 | builder or factory | Up switch
D79 | 1N4148W | SOD-123 | 1N4148W | factory | Up anti-ghosting diode; pad 1/cathode band faces ROW net
SW80 | MX hotswap socket | Kailh MX hotswap | CPG151101S11 | builder or factory | Left switch
D80 | 1N4148W | SOD-123 | 1N4148W | factory | Left anti-ghosting diode; pad 1/cathode band faces ROW net
SW81 | MX hotswap socket | Kailh MX hotswap | CPG151101S11 | builder or factory | Down switch
D81 | 1N4148W | SOD-123 | 1N4148W | factory | Down anti-ghosting diode; pad 1/cathode band faces ROW net
SW82 | MX hotswap socket | Kailh MX hotswap | CPG151101S11 | builder or factory | Right switch
D82 | 1N4148W | SOD-123 | 1N4148W | factory | Right anti-ghosting diode; pad 1/cathode band faces ROW net

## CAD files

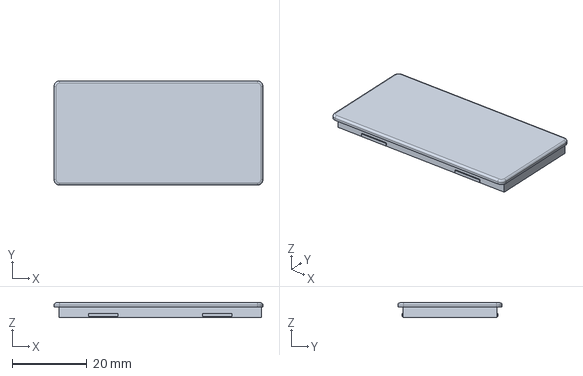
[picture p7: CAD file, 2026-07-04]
hardware/cad/build123d/oso75_bay_cover.step
56.1 x 28.0 x 3.90 mm

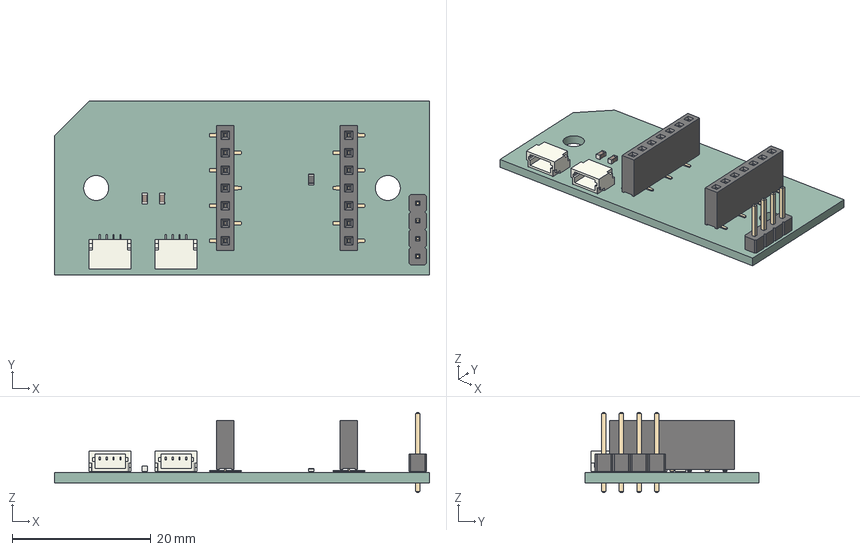
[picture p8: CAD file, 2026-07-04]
hardware/kicad/oso-module-carrier/oso_module_carrier.step
54.0 x 25.0 x 11.5 mm
R_0603_1608Metric
PinSocket_1x07_P2.54mm_Vertical_SMD_Pin1Right
C_0603_1608Metric x 2
JST_SH_SM04B-SRSS-TB_1x04-1MP_P1.00mm_Horizontal x 2
PinSocket_1x07_P2.54mm_Vertical_SMD_Pin1Left
PinHeader_1x04_P254mm_Vertical
oso_module_carrier_PCB

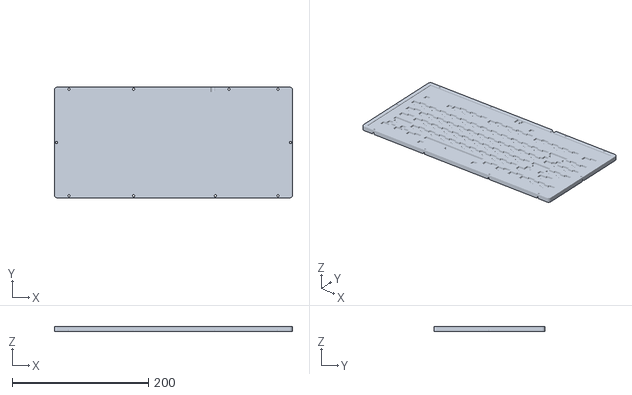
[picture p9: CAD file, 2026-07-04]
web/public/models/oso75_case_bottom.stl
349.7 x 162.7 x 7.00

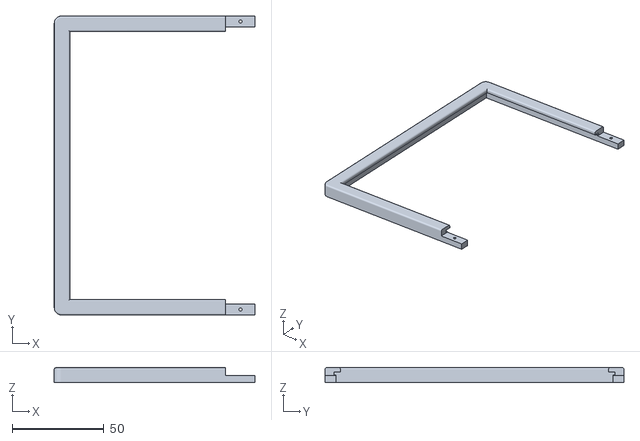
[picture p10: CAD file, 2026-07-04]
hardware/cad/build123d/oso75_case_bezel_seg1.stl
109.1 x 162.7 x 8.00

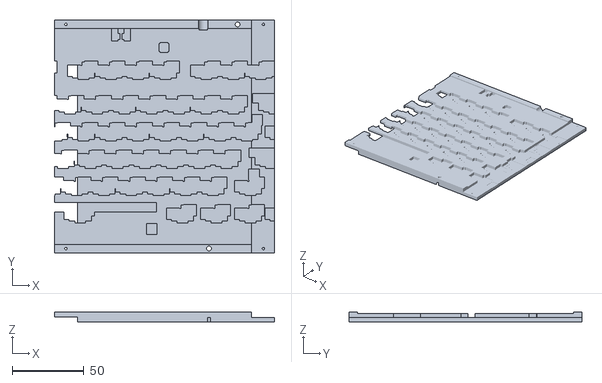
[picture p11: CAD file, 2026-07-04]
hardware/cad/build123d/oso75_case_bottom_seg2.stl
153.8 x 162.7 x 7.00

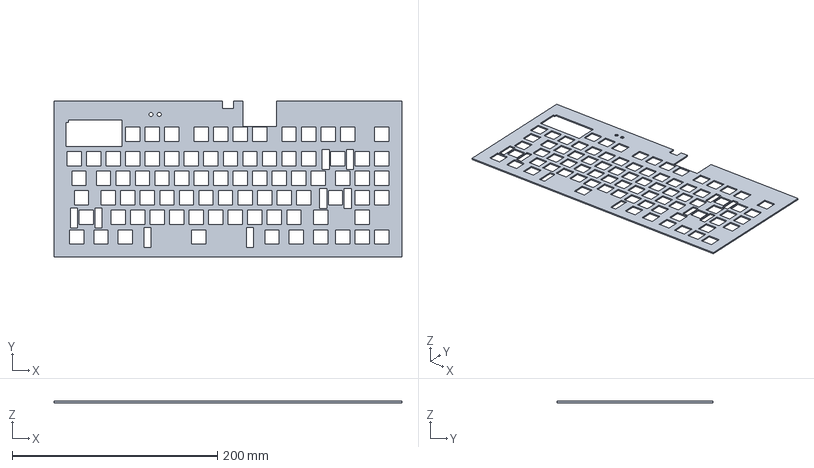
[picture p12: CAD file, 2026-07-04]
hardware/cad/build123d/oso75_plate.step
339.3 x 152.3 x 1.50 mm

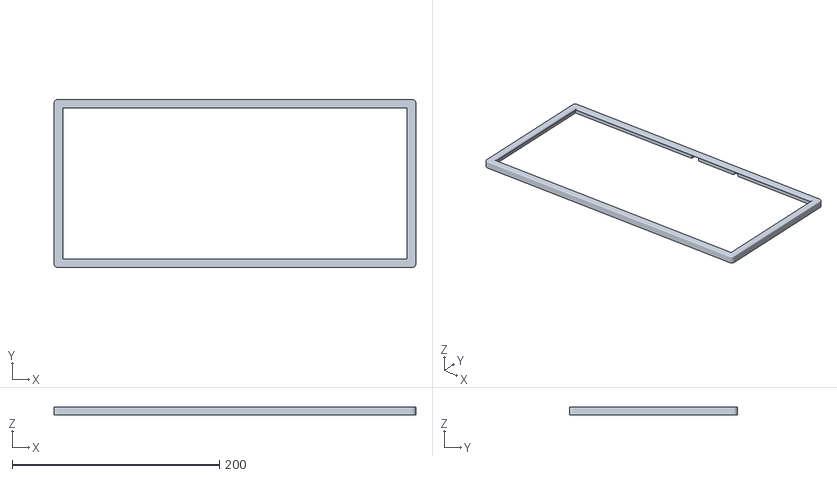
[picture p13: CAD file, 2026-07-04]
web/public/models/oso75_case_bezel.stl
349.7 x 162.7 x 8.00

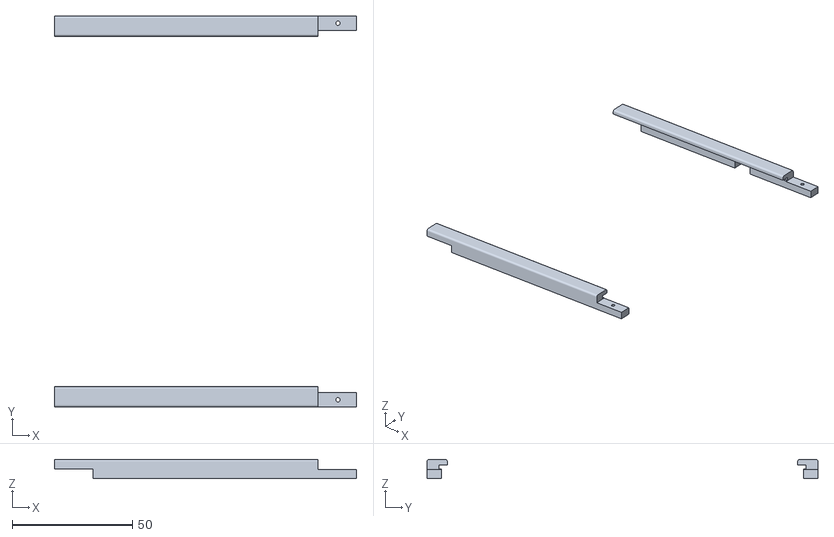
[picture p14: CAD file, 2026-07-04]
hardware/cad/build123d/oso75_case_bezel_seg2.stl
125.8 x 162.7 x 8.00

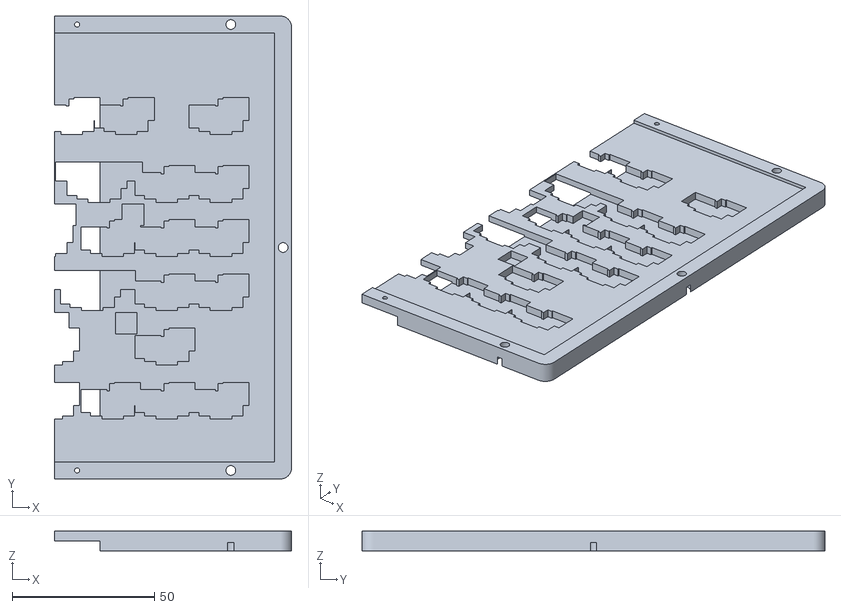
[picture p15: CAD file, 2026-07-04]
hardware/cad/build123d/oso75_case_bottom_seg3.stl
83.4 x 162.7 x 7.00

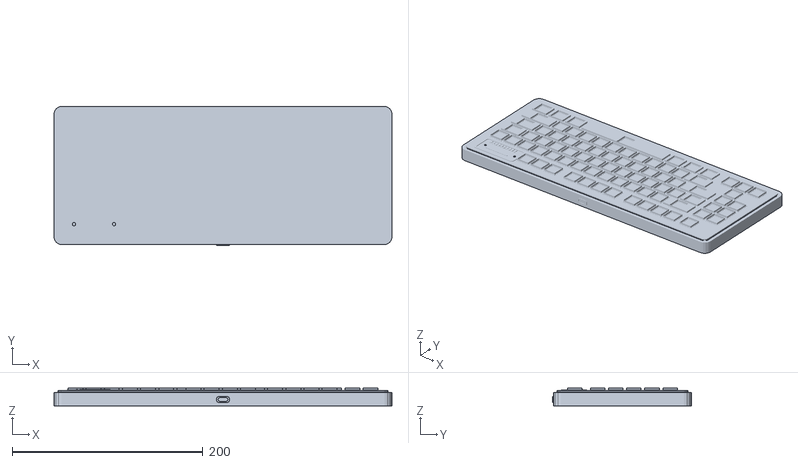
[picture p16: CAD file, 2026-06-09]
web/public/models/oso75_case_plate.stl
354.6 x 146.1 x 18.7

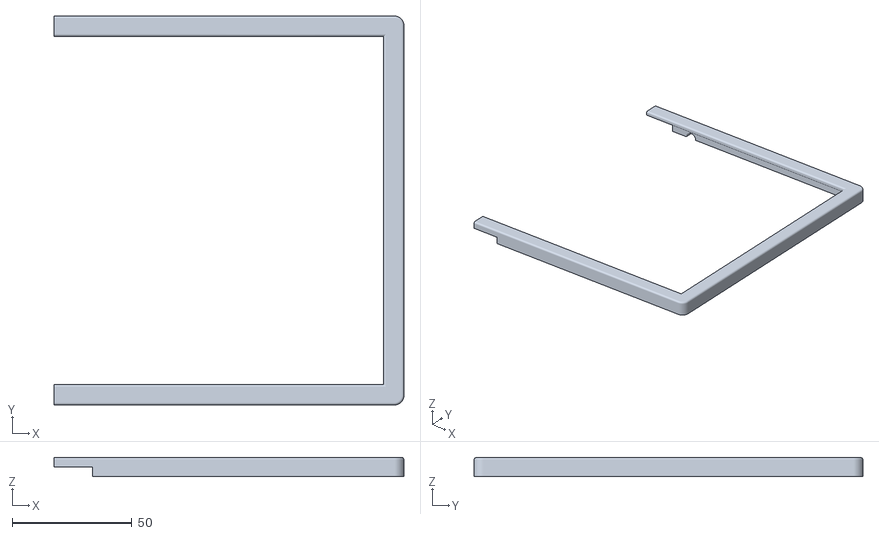
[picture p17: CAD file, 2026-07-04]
hardware/cad/build123d/oso75_case_bezel_seg3.stl
146.4 x 162.7 x 8.00

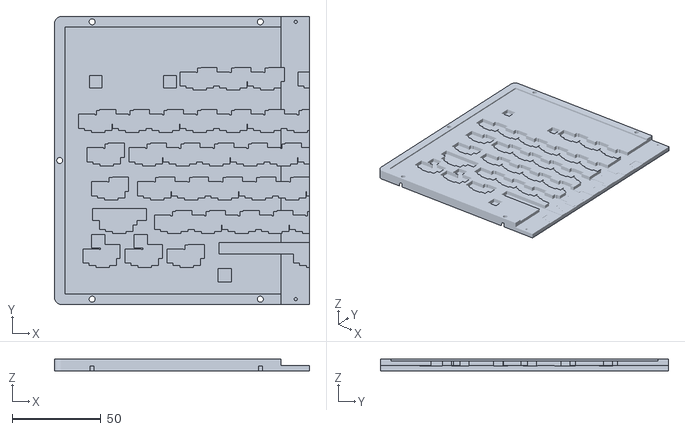
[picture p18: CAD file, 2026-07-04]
hardware/cad/build123d/oso75_case_bottom_seg1.stl
144.1 x 162.7 x 7.00

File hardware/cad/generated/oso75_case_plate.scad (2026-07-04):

// Generated by scripts/generate.mjs. Edit hardware/layout/oso75.layout.json.
$fn = 16;
unit = 19.05;
plate_thickness = 1.6;
case_wall = 4;
case_floor = 3;
pcb_clearance = 0.8;
pcb_thickness = 1.6;
pcb_z = 9.5;
usb_c_z = 12.7;
switch_cutout = 14;
plate_z = 14.5;
case_height = plate_z + plate_thickness + 1.0;
gadget_x = 11;
gadget_y = 107.063;
gadget_w = 54;
gadget_h = 25;
gadget_contact_pitch = 3.8;
gadget_contact_start = 9.900;
// Contact row offset from the bay's low-y edge; matches J3 pads on the
// routed board (pad centers at y = 114.363 = 107.063 + 7.3).
gadget_contact_y = 7.3;
board_width = 337.088;
board_height = 150.063;
usb_c_x = board_width / 2;
keys = [
  [66.675, 109.537, 19.050, 19.050, "F2"],
  [85.725, 109.537, 19.050, 19.050, "F3"],
  [104.775, 109.537, 19.050, 19.050, "F4"],
  [133.350, 109.537, 19.050, 19.050, "F5"],
  [152.400, 109.537, 19.050, 19.050, "F6"],
  [171.450, 109.537, 19.050, 19.050, "F7"],
  [190.500, 109.537, 19.050, 19.050, "F8"],
  [219.075, 109.537, 19.050, 19.050, "F9"],
  [238.125, 109.537, 19.050, 19.050, "F10"],
  [257.175, 109.537, 19.050, 19.050, "F11"],
  [276.225, 109.537, 19.050, 19.050, "F12"],
  [9.525, 85.725, 19.050, 19.050, "`"],
  [28.575, 85.725, 19.050, 19.050, "1"],
  [47.625, 85.725, 19.050, 19.050, "2"],
  [66.675, 85.725, 19.050, 19.050, "3"],
  [85.725, 85.725, 19.050, 19.050, "4"],
  [104.775, 85.725, 19.050, 19.050, "5"],
  [123.825, 85.725, 19.050, 19.050, "6"],
  [142.875, 85.725, 19.050, 19.050, "7"],
  [161.925, 85.725, 19.050, 19.050, "8"],
  [180.975, 85.725, 19.050, 19.050, "9"],
  [200.025, 85.725, 19.050, 19.050, "0"],
  [219.075, 85.725, 19.050, 19.050, "-"],
  [238.125, 85.725, 19.050, 19.050, "="],
  [266.700, 85.725, 38.100, 19.050, "Backspace"],
  [14.288, 66.675, 28.575, 19.050, "Tab"],
  [38.100, 66.675, 19.050, 19.050, "Q"],
  [57.150, 66.675, 19.050, 19.050, "W"],
  [76.200, 66.675, 19.050, 19.050, "E"],
  [95.250, 66.675, 19.050, 19.050, "R"],
  [114.300, 66.675, 19.050, 19.050, "T"],
  [133.350, 66.675, 19.050, 19.050, "Y"],
  [152.400, 66.675, 19.050, 19.050, "U"],
  [171.450, 66.675, 19.050, 19.050, "I"],
  [190.500, 66.675, 19.050, 19.050, "O"],
  [209.550, 66.675, 19.050, 19.050, "P"],
  [228.600, 66.675, 19.050, 19.050, "["],
  [247.650, 66.675, 19.050, 19.050, "]"],
  [271.463, 66.675, 28.575, 19.050, "\\"],
  [16.669, 47.625, 33.337, 19.050, "Caps"],
  [42.863, 47.625, 19.050, 19.050, "A"],
  [61.912, 47.625, 19.050, 19.050, "S"],
  [80.963, 47.625, 19.050, 19.050, "D"],
  [100.013, 47.625, 19.050, 19.050, "F"],
  [119.063, 47.625, 19.050, 19.050, "G"],
  [138.113, 47.625, 19.050, 19.050, "H"],
  [157.162, 47.625, 19.050, 19.050, "J"],
  [176.213, 47.625, 19.050, 19.050, "K"],
  [195.263, 47.625, 19.050, 19.050, "L"],
  [214.313, 47.625, 19.050, 19.050, ";"],
  [233.363, 47.625, 19.050, 19.050, "'"],
  [264.319, 47.625, 42.863, 19.050, "Enter"],
  [21.431, 28.575, 42.863, 19.050, "LShift"],
  [52.388, 28.575, 19.050, 19.050, "Z"],
  [71.438, 28.575, 19.050, 19.050, "X"],
  [90.487, 28.575, 19.050, 19.050, "C"],
  [109.538, 28.575, 19.050, 19.050, "V"],
  [128.588, 28.575, 19.050, 19.050, "B"],
  [147.638, 28.575, 19.050, 19.050, "N"],
  [166.688, 28.575, 19.050, 19.050, "M"],
  [185.738, 28.575, 19.050, 19.050, ","],
  [204.787, 28.575, 19.050, 19.050, "."],
  [223.838, 28.575, 19.050, 19.050, "/"],
  [250.031, 28.575, 33.337, 19.050, "RShift"],
  [11.906, 9.525, 23.813, 19.050, "LCtrl"],
  [35.719, 9.525, 23.813, 19.050, "LGUI"],
  [59.531, 9.525, 23.813, 19.050, "LAlt"],
  [130.969, 9.525, 119.063, 19.050, "Space"],
  [202.406, 9.525, 23.813, 19.050, "RAlt"],
  [226.219, 9.525, 23.813, 19.050, "Fn"],
  [250.031, 9.525, 23.813, 19.050, "RCtrl"],
  [309.563, 109.537, 19.050, 19.050, "PrtSc"],
  [290.512, 85.725, 19.050, 19.050, "Ins"],
  [309.563, 85.725, 19.050, 19.050, "Home"],
  [290.512, 66.675, 19.050, 19.050, "PgUp"],
  [309.563, 66.675, 19.050, 19.050, "Del"],
  [290.512, 47.625, 19.050, 19.050, "End"],
  [309.563, 47.625, 19.050, 19.050, "PgDn"],
  [290.512, 28.575, 19.050, 19.050, "Up"],
  [271.463, 9.525, 19.050, 19.050, "Left"],
  [290.512, 9.525, 19.050, 19.050, "Down"],
  [309.563, 9.525, 19.050, 19.050, "Right"]
];

module rounded_rect_2d(size, radius) {
  offset(r = radius)
    square([max(0.1, size[0] - radius * 2), max(0.1, size[1] - radius * 2)], center = true);
}

module rounded_box(size, radius) {
  linear_extrude(height = size[2])
    translate([size[0] / 2, size[1] / 2])
      rounded_rect_2d([size[0], size[1]], radius);
}

module switch_cutouts(depth = plate_thickness + 0.3) {
  for (k = keys) {
    if (!(k[0] + 9 > gadget_x - 2 && k[0] + 9 < gadget_x + gadget_w + 2 && k[1] + 9 > gadget_y - 2 && k[1] + 9 < gadget_y + gadget_h + 2)) {
      translate([k[0] + 9, k[1] + 9, -0.15])
        cube([switch_cutout, switch_cutout, depth], center = true);
    }
  }
}

module plate_bezels() {
  for (k = keys) {
    if (!(k[0] + 9 > gadget_x - 2 && k[0] + 9 < gadget_x + gadget_w + 2 && k[1] + 9 > gadget_y - 2 && k[1] + 9 < gadget_y + gadget_h + 2)) {
      translate([k[0] + 9, k[1] + 9, plate_thickness - 0.2])
        linear_extrude(height = 0.45)
          difference() {
            square([min(k[2] - 2.2, 17.2), 17.2], center = true);
            square([switch_cutout, switch_cutout], center = true);
          }
    }
  }
}

module stabilizer_slots() {
  for (k = keys) {
    if (k[2] >= unit * 1.75) {
      stab_spacing = k[2] >= unit * 5 ? 50 : 23.8;
      for (xoff = [-stab_spacing / 2, stab_spacing / 2]) {
        translate([k[0] + 9 + xoff, k[1] + 9, -0.2])
          cube([6.6, 12.4, plate_thickness + 0.5], center = true);
      }
    }
  }
}

module gadget_bay_cutouts() {
  translate([gadget_x + gadget_w / 2, gadget_y + gadget_h / 2, plate_thickness - 0.55])
    linear_extrude(height = 0.75)
      rounded_rect_2d([gadget_w, gadget_h], 3);

  for (xoff = [6, gadget_w - 6]) {
    translate([gadget_x + xoff, gadget_y + gadget_h / 2, -0.2])
      cylinder(h = plate_thickness + 0.5, r = 1.8);
  }
}

module gadget_bay_details() {
  translate([gadget_x + gadget_w / 2, gadget_y + gadget_h / 2, plate_thickness + 0.15])
    linear_extrude(height = 0.65)
      difference() {
        rounded_rect_2d([gadget_w + 2.2, gadget_h + 2.2], 3.6);
        rounded_rect_2d([gadget_w - 2.4, gadget_h - 2.4], 2.2);
  }

  for (i = [0:9]) {
    translate([gadget_x + gadget_contact_start + i * gadget_contact_pitch, gadget_y + gadget_contact_y, plate_thickness + 0.85])
      cube([1.9, 4.2, 0.5], center = true);
  }

  translate([gadget_x + gadget_w / 2, gadget_y + gadget_h - 6.5, plate_thickness + 0.9])
    cube([31, 2.2, 0.45], center = true);
}

// USB-C exits through the BACK wall (high y): J1 sits at the rear edge of
// the PCB next to the ESP32 module.
module usb_c_slot(width = 10.2, height = 3.8, depth = case_wall + 0.7) {
  translate([case_wall + usb_c_x, case_wall * 2 + board_height + 0.35, usb_c_z])
    rotate([90, 0, 0])
      linear_extrude(height = depth)
        rounded_rect_2d([width, height], height / 2);
}

module usb_c_bezel() {
  translate([case_wall + usb_c_x, case_wall * 2 + board_height + 0.2, usb_c_z])
    rotate([90, 0, 0])
      linear_extrude(height = 0.7)
        difference() {
          rounded_rect_2d([13.4, 6.4], 2.3);
          rounded_rect_2d([10.2, 3.8], 1.9);
        }
}

module pcb_switch_holes(depth = pcb_thickness + 0.3) {
  for (k = keys) {
    translate([k[0] + 9, k[1] + 9, -0.15])
      cylinder(h = depth, r = 2.05);
    for (xoff = [-5.08, 5.08]) {
      translate([k[0] + 9 + xoff, k[1] + 9, -0.15])
        cylinder(h = depth, r = 1.15);
    }
  }
}

module pcb_switch_pads() {
  for (k = keys) {
    translate([k[0] + 9 - 5.08, k[1] + 9, pcb_thickness + 0.03])
      cylinder(h = 0.12, r = 2.0);
    translate([k[0] + 9 + 5.08, k[1] + 9, pcb_thickness + 0.03])
      cylinder(h = 0.12, r = 2.0);
    translate([k[0] + 9 + 6.5, k[1] + 9 + 6.5, pcb_thickness + 0.05])
      cube([4.6, 2.5, 0.14], center = true);
  }
}

module pcb_module_bay_holes(depth = pcb_thickness + 0.3) {
  for (xoff = [6, gadget_w - 6]) {
    translate([gadget_x + xoff, gadget_y + gadget_h / 2, -0.15])
      cylinder(h = depth, r = 1.8);
  }
}

module pcb_module_bay_contacts() {
  for (i = [0:9]) {
    translate([gadget_x + gadget_contact_start + i * gadget_contact_pitch, gadget_y + gadget_contact_y, pcb_thickness + 0.08])
      cube([1.9, 4.2, 0.16], center = true);
  }
}

module pcb_preview() {
  translate([case_wall, case_wall, pcb_z]) {
    color("#247a4b")
      difference() {
        rounded_box([board_width, board_height, pcb_thickness], 5);
        pcb_switch_holes();
        pcb_module_bay_holes();
      }
    color("#c9a13a")
      pcb_switch_pads();
    color("#c9a13a")
      pcb_module_bay_contacts();
    color("#b9bbb3")
    translate([usb_c_x, board_height - 2.8, usb_c_z - pcb_z])
      cube([9.8, 5.6, 3.2], center = true);
  }
}
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

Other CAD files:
web/public/models/oso75_bay_cover.stl
web/public/models/oso75_module_carrier.stl
web/public/models/oso75_plate.stl
hardware/cad/build123d/oso75_case_bezel.step
hardware/cad/build123d/oso75_module_carrier.stl
hardware/cad/build123d/oso75_bay_cover.stl
hardware/cad/build123d/oso75_plate.stl

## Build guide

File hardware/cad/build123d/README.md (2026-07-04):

# OSO75 Production Case (build123d)

Parametric B-rep CAD for the OSO75 case, generated by `oso75_case.py` from
the routed PCB (`pcb_extract.json`, dumped from `oso75.kicad_pcb`) and
`hardware/layout/oso75.layout.json`. No other inputs.

Regenerate with `python3 oso75_case.py` (needs `pip install build123d`).
If the PCB ever changes, re-dump `pcb_extract.json` first (see the extract
script in git history / the JSON's provenance).

## Parts

| File | Part | Notes |
|---|---|---|
| `oso75_case_bottom.step/.stl` | Bottom tray | filled acoustic deck, screw counterbores, feet recesses |
| `oso75_case_bezel.step/.stl` | Top bezel | clamp step, USB slot, antenna hole, screw pilots |
| `oso75_plate.step/.stl` | Switch plate | 82 MX cutouts, stab + bay openings, 1.5 mm |
| `oso75_bay_cover.step/.stl` | Bay blank | snap-in cover for the empty module bay, with a reduced right lip for keycap clearance |
| `oso75_assembly.step/.glb` | Assembly | all parts in working position |

Outer dimensions: **349.7 x 162.7 x 15.0 mm** (exceeds most consumer FDM
beds — print diagonally on 350 mm+ machines, or CNC/resin/print-farm it).
STEP files open in Fusion/SolidWorks/FreeCAD for fillets, branding, etc.

## Small-bed (A1 mini) segmented variant

For 180 x 180 beds the tray and bezel are also exported as three X-segments
each (`*_seg1..3.stl`, all 83–154 mm wide), joined by glued **stepped lap
joints**: 16 mm overlap, step at mid-height, 0.2 mm glue gap, plus two
vertical 1.75 mm filament alignment-pin holes per seam in the walls. Tray
seams (x = 130/268) and bezel seams (x = 95/205) are staggered so no joint
runs through the assembled case, and every seam is assert-checked clear of
screws, feet, the USB slot and the antenna hole. Glue-up: drop filament
pins in the lower piece's holes, epoxy the lap faces, lower the next
segment on. The laser-cut plate bridges all seams as a stiff spine; the
solid acoustic deck gives each tray seam ~10 cm^2 of glue area.

## Hardware BOM

| Qty | Item | Where |
|---|---|---|
| 10 | M3 x 10 socket head cap screw | from below, through tray into bezel |
| 4 | 10 mm adhesive bumpon feet | recesses in tray underside |
| 1 | RP-SMA bulkhead u.FL pigtail (~100 mm) | back-wall 6.5 mm hole |
| (10) | optional M3 heat-set inserts, OD <= 4.6 | drill bezel pilots to 4.0 first |

Screws self-tap into 2.55 mm pilots — good for FDM/MJF prototypes and small
runs. For injection molding or frequent disassembly, switch to heat-set
inserts (regenerate with `SCREW_PILOT_D = 4.0`).

## Assembly

1. Stick the RP-SMA pigtail's bulkhead in the back-wall half-hole of the
   tray (the hole straddles the parting line, so the cable just drops in).
2. Build the sandwich on the bench: clip all 82 switches into the plate,
   then press the assembly onto the PCB so every switch pin seats in its
   hotswap socket (plate-to-PCB gap = 3.5 mm everywhere). Snap the u.FL end
   onto ANT1 — the cable runs in the 3.5 mm under-plate channel.
3. Lower the sandwich into the tray, USB-C toward the back wall. The PCB
   nests in the lower cavity; the plate's 1.1 mm border rests proud of it.
4. Seat the bezel — its internal step lands on the plate border and the
   USB-C receptacle should be centered in the slot.
5. Flip, drive the 10 M3 screws (snug, do not crank — they clamp the whole
   stack), stick on the feet.
6. Drop the OSO module into the bay opening (top-left). Power-off swaps only.

## Design data (derived, not assumed)

- PCB outline 337.088 x 150.063 from Edge.Cuts; cavity clearance 0.3 mm.
- MX stack: PCB top z7.6, plate top = PCB top + 5.0 (spec), plate 1.5 mm.
- Filled acoustic deck: the under-PCB volume is solid to 0.2 mm below the
  board (no hollow cavity = no drum resonance); only the bottom-side
  keep-outs are pocketed 2.8 mm deep for the 1.85 mm Kailh sockets, solder
  joints, pegs and bottom bodies. Nominal PCB float 0.2 mm (the
  bezel-clamped plate defines stack height).
- USB slot sized to the HRO TYPE-C-31-M-12 body (8.94 x 3.26, +0.4 tol),
  opened down to the parting line; at J1 x = 168.54.
- Antenna hole 6.5 mm for the ESP32-S3-WROOM-1U pigtail, x = 226.
- Stab openings span the actual 3.988/3.048 NPTH pairs on the board +2 mm.
- Module bay opening 54.6 x 25.6 over J3; bezel does not overlap it, so
  modules power-off swap without opening the case. The cover has an asymmetric
  lip plus a keycap-envelope assertion so it does not crowd the adjacent F-row.
- Reset/boot finger holes in the plate above SW_RESET / SW_BOOT.
- Rear plate reliefs clear the USB-C body, ESP32-S3-WROOM-1U module, and
  u.FL pigtail path. Reliefs are assertion-checked against every MX switch
  cutout plus margin so the rear electronics pocket cannot eat F-row plate
  material; still verify the chosen pigtail with a physical coupon.
- Deck pockets are generated from the bottom-side obstacle map extracted
  from KiCad (hotswap socket pads +2.5 mm, every through-hole +1.5 mm,
  bottom-side bodies +1 mm, +0.3 mm margin), plus four spans where the
  stab wires swing below the PCB — so the solid deck only ever touches
  bare soldermask, yet backs every key against typing flex and switch
  hot-swap force.
- Walls 6 mm (house the screw columns), floor 3 mm, corner R4.
- Parting line at z = 7.0; bezel underside sits 0.1 mm above the plate.

## Print/manufacture notes

- Tray and bezel print flat side down, no supports needed except the USB
  slot bridge (9.7 mm — fine) and the antenna half-holes.
- Plate: FDM at 1.5 mm works but flexes; MJF nylon, CNC POM/alu, or laser-cut
  1.5 mm steel/FR4 from `oso75_plate.step` is the production choice.
- Material: PETG/ABS/ASA or MJF PA12 for the case. PLA OK for fit checks.

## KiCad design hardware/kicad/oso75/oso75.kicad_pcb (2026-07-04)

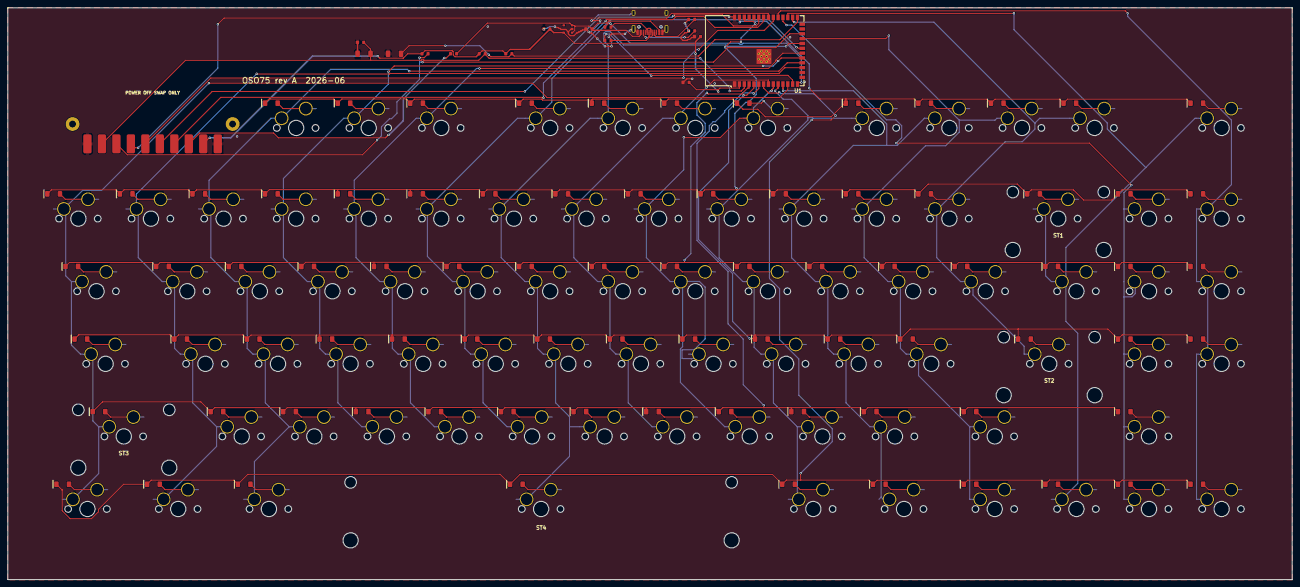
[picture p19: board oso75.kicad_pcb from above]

Board: 2 copper layers, 337.1 x 150.1 mm, 187 parts (0 on the bottom side), 121 nets.

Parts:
C1, C2: 10uF; C_0603
C3, C4: 100nF; C_0603
C_EN: 1uF; C_0603
D1, D2, D3, D4, D5, D6, D7, D8, D9, D10, D11, D12, D13, D14, D15, D16, D17, D18, D19, D20, D21, D22, D23, D24, D25, D26, D27, D28, D29, D30, D31, D32, D33, D34, D35, D36, D37, D38, D39, D40, D41, D42, D43, D44, D45, D46, D47, D48, D49, D50, D51, D52, D53, D54, D55, D56, D57, D58, D59, D60, D61, D62, D63, D64, D65, D66, D67, D68, D69, D70, D71, D72, D73, D74, D75, D76, D77, D78, D79, D80, D81, D82: 1N4148W; D_SOD-123_Keyboard
F1: 0603L050SLYR; Polyfuse_0603
J1: USB_C_HRO_TYPE-C-31-M-12; USB_C_Receptacle_HRO_TYPE-C-31-M-12
J3: Exposed_OSO_Bay_Pads_DNP; OSO_Module_Bay_10
R1, R2: 5.1k; R_0603
R3, R4: 27R; R_0603
R5, R6, R10: 10k; R_0603
ST1, ST2, ST3: Stabilizer_Cherry_MX_2.00u
ST4: Stabilizer_Cherry_MX_6.25u
SW1, SW2, SW3, SW4, SW5, SW6, SW7, SW8, SW9, SW10, SW11, SW12, SW13, SW14, SW15, SW16, SW17, SW18, SW19, SW20, SW21, SW22, SW23, SW24, SW25, SW26, SW27, SW28, SW29, SW30, SW31, SW32, SW33, SW34, SW35, SW36, SW37, SW38, SW39, SW40, SW41, SW42, SW43, SW44, SW45, SW46, SW47, SW48, SW49, SW50, SW51, SW52, SW53, SW54, SW55, SW56, SW57, SW58, SW59, SW60, SW61, SW62, SW63, SW64, SW65, SW66, SW67, SW68, SW69, SW70, SW71, SW72, SW73, SW74, SW75, SW76, SW77, SW78, SW79, SW80, SW81, SW82: MX_Hotswap; SW_Hotswap_Kailh_MX_Plated_1.00u_With_Switch
SW_BOOT: BOOT; SW_Tactile_4x3
SW_RESET: RESET; SW_Tactile_4x3
U1: ESP32-S3-WROOM-1U-N16
U3: AP2112K-3.3; SOT-23-5_LDO

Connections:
+3V3: C2.1, C3.1, C4.1, J3.2, R5.2, R6.2, R10.2, U1.2, U3.5
BOOT_IO0: R6.1, SW_BOOT.1, U1.27
COL0: SW12.1, SW26.1, SW40.1, SW53.1, SW65.1, U1.12
COL1: SW13.1, SW27.1, SW41.1, SW54.1, SW66.1, U1.17
COL2: SW1.1, SW14.1, SW28.1, SW42.1, SW55.1, SW67.1, U1.18
COL3: SW2.1, SW15.1, SW29.1, SW43.1, SW56.1, U1.19
COL4: SW3.1, SW16.1, SW30.1, SW44.1, SW57.1, U1.20
COL5: SW4.1, SW17.1, SW31.1, SW45.1, SW58.1, U1.21
COL6: SW5.1, SW18.1, SW32.1, SW46.1, SW59.1, SW68.1, U1.22
COL7: SW6.1, SW19.1, SW33.1, SW47.1, SW60.1, U1.8
COL8: SW7.1, SW20.1, SW34.1, SW48.1, SW61.1, U1.9
COL9: SW8.1, SW21.1, SW35.1, SW49.1, SW62.1, SW69.1, U1.10
COL10: SW9.1, SW22.1, SW36.1, SW50.1, SW63.1, SW70.1, U1.11
COL11: SW10.1, SW23.1, SW37.1, SW51.1, SW64.1, SW71.1, U1.23
COL12: SW11.1, SW24.1, SW38.1, SW52.1, U1.28
COL13: SW25.1, SW39.1, SW72.1, SW80.1, U1.29
COL14: SW73.1, SW75.1, SW77.1, SW79.1, SW81.1, U1.30
COL15: SW74.1, SW76.1, SW78.1, SW82.1, U1.31
D1_A: D1.2, SW1.2
D2_A: D2.2, SW2.2
D3_A: D3.2, SW3.2
D4_A: D4.2, SW4.2
D5_A: D5.2, SW5.2
D6_A: D6.2, SW6.2
D7_A: D7.2, SW7.2
D8_A: D8.2, SW8.2
D9_A: D9.2, SW9.2
D10_A: D10.2, SW10.2
D11_A: D11.2, SW11.2
D12_A: D12.2, SW12.2
D13_A: D13.2, SW13.2
D14_A: D14.2, SW14.2
D15_A: D15.2, SW15.2
D16_A: D16.2, SW16.2
D17_A: D17.2, SW17.2
D18_A: D18.2, SW18.2
D19_A: D19.2, SW19.2
D20_A: D20.2, SW20.2
D21_A: D21.2, SW21.2
D22_A: D22.2, SW22.2
D23_A: D23.2, SW23.2
D24_A: D24.2, SW24.2
D25_A: D25.2, SW25.2
D26_A: D26.2, SW26.2
D27_A: D27.2, SW27.2
D28_A: D28.2, SW28.2
D29_A: D29.2, SW29.2
D30_A: D30.2, SW30.2
D31_A: D31.2, SW31.2
D32_A: D32.2, SW32.2
D33_A: D33.2, SW33.2
D34_A: D34.2, SW34.2
D35_A: D35.2, SW35.2
D36_A: D36.2, SW36.2
D37_A: D37.2, SW37.2
D38_A: D38.2, SW38.2
D39_A: D39.2, SW39.2
D40_A: D40.2, SW40.2
D41_A: D41.2, SW41.2
D42_A: D42.2, SW42.2
D43_A: D43.2, SW43.2
D44_A: D44.2, SW44.2
D45_A: D45.2, SW45.2
D46_A: D46.2, SW46.2
D47_A: D47.2, SW47.2
D48_A: D48.2, SW48.2
D49_A: D49.2, SW49.2
D50_A: D50.2, SW50.2
D51_A: D51.2, SW51.2
D52_A: D52.2, SW52.2
D53_A: D53.2, SW53.2
D54_A: D54.2, SW54.2
D55_A: D55.2, SW55.2
D56_A: D56.2, SW56.2
D57_A: D57.2, SW57.2
D58_A: D58.2, SW58.2
D59_A: D59.2, SW59.2
D60_A: D60.2, SW60.2
D61_A: D61.2, SW61.2
D62_A: D62.2, SW62.2
D63_A: D63.2, SW63.2
D64_A: D64.2, SW64.2
D65_A: D65.2, SW65.2
D66_A: D66.2, SW66.2
D67_A: D67.2, SW67.2
D68_A: D68.2, SW68.2
D69_A: D69.2, SW69.2
D70_A: D70.2, SW70.2
D71_A: D71.2, SW71.2
D72_A: D72.2, SW72.2
D73_A: D73.2, SW73.2
D74_A: D74.2, SW74.2
D75_A: D75.2, SW75.2
D76_A: D76.2, SW76.2
D77_A: D77.2, SW77.2
D78_A: D78.2, SW78.2
D79_A: D79.2, SW79.2
D80_A: D80.2, SW80.2
D81_A: D81.2, SW81.2
D82_A: D82.2, SW82.2
ESP_EN: C_EN.1, J3.9, R5.1, SW_RESET.1, U1.3
GND: C1.2, C2.2, C3.2, C4.2, C_EN.2, J1.A1, J1.A12, J1.B1, J1.B12, J1.SH, J3.1, J3.10, R1.2, R2.2, SW_BOOT.2, SW_RESET.2, U1.1, U1.40, U1.41, U3.2
I2C_SCL: J3.5, U1.35
I2C_SDA: J3.4, U1.34
MOD_A: J3.6, U1.32
MOD_B: J3.7, U1.33
MOD_INT: J3.8, R10.1, U1.24
ROW0: D1.1, D2.1, D3.1, D4.1, D5.1, D6.1, D7.1, D8.1, D9.1, D10.1, D11.1, D72.1, U1.39
ROW1: D12.1, D13.1, D14.1, D15.1, D16.1, D17.1, D18.1, D19.1, D20.1, D21.1, D22.1, D23.1, D24.1, D25.1, D73.1, D74.1, U1.38
ROW2: D26.1, D27.1, D28.1, D29.1, D30.1, D31.1, D32.1, D33.1, D34.1, D35.1, D36.1, D37.1, D38.1, D39.1, D75.1, D76.1, U1.4
ROW3: D40.1, D41.1, D42.1, D43.1, D44.1, D45.1, D46.1, D47.1, D48.1, D49.1, D50.1, D51.1, D52.1, D77.1, D78.1, U1.5
ROW4: D53.1, D54.1, D55.1, D56.1, D57.1, D58.1, D59.1, D60.1, D61.1, D62.1, D63.1, D64.1, D79.1, U1.6
ROW5: D65.1, D66.1, D67.1, D68.1, D69.1, D70.1, D71.1, D80.1, D81.1, D82.1, U1.7
USB_CC1: J1.A5, R1.1
USB_CC2: J1.B5, R2.1
USB_DM: R4.2, U1.13
USB_DM_CONN: J1.A7, J1.B7, R4.1
USB_DP: R3.2, U1.14
USB_DP_CONN: J1.A6, J1.B6, R3.1
VBUS: C1.1, F1.1, J1.A4, J1.A9, J1.B4, J1.B9, U3.1, U3.3
VBUS_FUSED: F1.2, J3.3

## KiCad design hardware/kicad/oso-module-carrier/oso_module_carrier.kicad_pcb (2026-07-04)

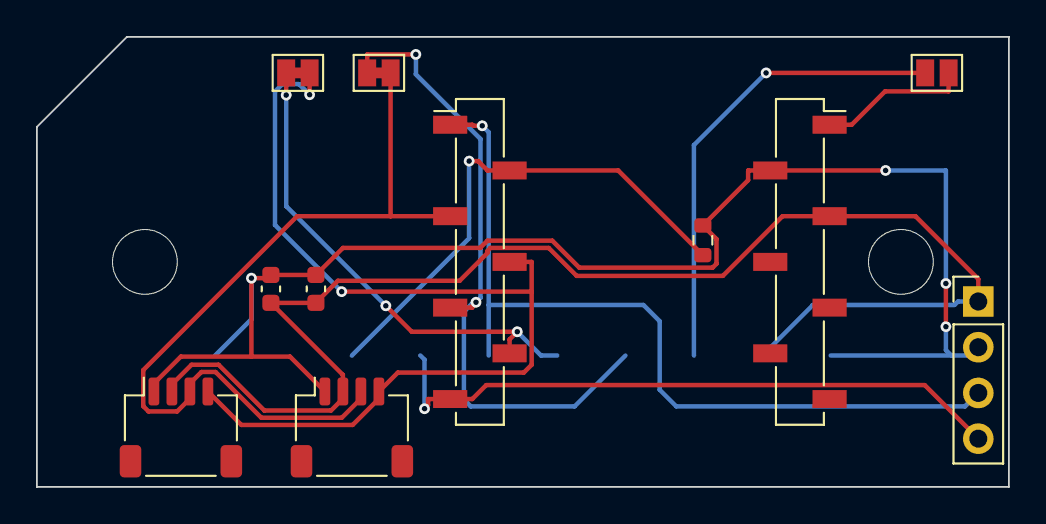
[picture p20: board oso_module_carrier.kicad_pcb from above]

Board: 2 copper layers, 54.0 x 25.0 mm, 12 parts (0 on the bottom side), 11 nets.

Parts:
C1, C2: C_0603_1608Metric
J1, J2: JST_SH_SM04B-SRSS-TB_1x04-1MP_P1.00mm_Horizontal
J4: PinHeader_1x04_P2.54mm_Vertical
JP1, JP2: SolderJumper-2_P1.3mm_Bridged_Pad1.0x1.5mm
JP3: SolderJumper-2_P1.3mm_Open_Pad1.0x1.5mm
MOD1: OSO_BAY_CONTACTS
R1: R_0603_1608Metric
U2: PinSocket_1x07_P2.54mm_Vertical_SMD_Pin1Left
U3: PinSocket_1x07_P2.54mm_Vertical_SMD_Pin1Right

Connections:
+3V3: C1.1, C2.1, J1.2, J2.2, J4.1, MOD1.2, U3.3
GND: C1.2, C2.2, J1.1, J2.1, J4.2, MOD1.1, MOD1.10, R1.2, U3.2
MOD_A: J4.3, MOD1.6, U2.1
MOD_B: J4.4, MOD1.7, U2.7
MOD_INT: MOD1.8, R1.1, U2.2
SCL_BAY: JP2.1, MOD1.5, U2.6
SCL_DEV: J1.4, J2.4, JP2.2, U2.4
SDA_BAY: JP1.1, MOD1.4, U2.5
SDA_DEV: J1.3, J2.3, JP1.2, U2.3
VBUS_FUSED: JP3.1, MOD1.3
XIAO_5V: JP3.2, U3.1

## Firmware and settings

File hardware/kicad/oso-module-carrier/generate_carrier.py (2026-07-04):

#!/usr/bin/env python3
"""OSO module carrier: XIAO ESP32-S3 socket + 2x Qwiic, for the OSO75 bay.

One PCB, two personalities:
  - XIAO socket empty, JP1/JP2 bridged (default): dumb Qwiic adapter --
    the keyboard's ESP32-S3 drives Qwiic devices over the bay I2C.
  - XIAO fitted, JP1/JP2 cut: smart module -- the XIAO owns the Qwiic
    (device) bus on D2/D3 and talks to the keyboard over the bay (link)
    bus on D4/D5, MOD_INT (D1) as attention line. Close JP3 to power the
    XIAO from the bay's fused 5 V instead of its own USB-C.

Bottom side carries the ten 2.2x5.0 contact pads that mirror the
keyboard's J3 (pogo pins solder here), Ø3.6 retention holes at ±21 mm.
Run under KiCad's bundled python. Routing is done by freerouting
afterwards (see route_carrier.sh).
"""
import os
import pcbnew
from pcbnew import VECTOR2I, FromMM

HERE = os.path.dirname(os.path.abspath(__file__))
OUT = os.path.join(HERE, "oso_module_carrier.kicad_pcb")
LIBS = "/Applications/KiCad/KiCad.app/Contents/SharedSupport/footprints"

W, H = 54.0, 25.0          # board outline, fits the 54.6 x 25.6 bay opening
# Contact row at the keyboard's ACTUAL J3 pad positions (J3 sits rotated
# 180 on the keyboard, so its pad 1 lands at +17.1, +5.2 from bay center).
# Carrier local coords == keyboard canvas offsets when the module drops in.
CONTACT_Y = 5.2
CONTACT_X0, CONTACT_PITCH = 17.1, -3.8
CHAMFER = 5.0              # back-left polarizing chamfer; the plate opening
                           # carries a matching corner key so the module
                           # physically cannot be inserted 180 deg wrong

board = pcbnew.NewBoard(OUT)

def mm(x, y):
    return VECTOR2I(FromMM(x), FromMM(y))

# ------------------------------------------------------------------ nets
NET_NAMES = ["GND", "+3V3", "VBUS_FUSED", "SDA_BAY", "SCL_BAY", "SDA_DEV",
             "SCL_DEV", "MOD_A", "MOD_B", "MOD_INT", "ESP_EN", "XIAO_5V"]
nets = {}
for n in NET_NAMES:
    item = pcbnew.NETINFO_ITEM(board, n)
    board.Add(item)
    nets[n] = item

# ------------------------------------- outline (chamfered back-left corner)
for a, b in [((-W/2 + CHAMFER, -H/2), (W/2, -H/2)), ((W/2, -H/2), (W/2, H/2)),
             ((W/2, H/2), (-W/2, H/2)), ((-W/2, H/2), (-W/2, -H/2 + CHAMFER)),
             ((-W/2, -H/2 + CHAMFER), (-W/2 + CHAMFER, -H/2))]:
    seg = pcbnew.PCB_SHAPE(board)
    seg.SetShape(pcbnew.SHAPE_T_SEGMENT)
    seg.SetLayer(pcbnew.Edge_Cuts)
    seg.SetWidth(FromMM(0.1))
    seg.SetStart(mm(*a)); seg.SetEnd(mm(*b))
    board.Add(seg)

# --------------------------------- bottom contact pads + retention holes
mod = pcbnew.FOOTPRINT(board)
mod.SetReference("MOD1")
mod.SetValue("OSO_BAY_CONTACTS")
mod.SetPosition(mm(0, 0))
CONTACT_NETS = ["GND", "+3V3", "VBUS_FUSED", "SDA_BAY", "SCL_BAY",
                "MOD_A", "MOD_B", "MOD_INT", "ESP_EN", "GND"]
bset = pcbnew.LSET()
bset.AddLayer(pcbnew.B_Cu); bset.AddLayer(pcbnew.B_Mask)
for k in range(10):
    p = pcbnew.PAD(mod)
    p.SetNumber(str(k + 1))
    p.SetAttribute(pcbnew.PAD_ATTRIB_SMD)
    p.SetShape(pcbnew.PAD_SHAPE_ROUNDRECT)
    p.SetRoundRectRadiusRatio(0.15)
    p.SetSize(mm(2.2, 5.0))
    p.SetLayerSet(bset)
    p.SetLayer(pcbnew.B_Cu)
    p.SetPosition(mm(CONTACT_X0 + CONTACT_PITCH * k, CONTACT_Y))
    mod.Add(p)
for sx in (-21.0, 21.0):
    p = pcbnew.PAD(mod)
    p.SetNumber("")
    p.SetAttribute(pcbnew.PAD_ATTRIB_NPTH)
    p.SetShape(pcbnew.PAD_SHAPE_CIRCLE)
    p.SetSize(mm(3.6, 3.6))
    p.SetDrillSize(mm(3.6, 3.6))
    p.SetLayerSet(pcbnew.PAD.UnplatedHoleMask())
    p.SetPosition(mm(sx, 0))
    mod.Add(p)
board.Add(mod)
for k, nname in enumerate(CONTACT_NETS):
    mod.FindPadByNumber(str(k + 1)).SetNet(nets[nname])

# ------------------------------------------------------------- footprints
def place(lib, name, ref, x, y, rot, padnets):
    fp = pcbnew.FootprintLoad(os.path.join(LIBS, lib + ".pretty"), name)
    assert fp, f"footprint {lib}/{name} not found"
    fp.SetReference(ref)
    fp.SetPosition(mm(x, y))
    fp.SetOrientationDegrees(rot)
    board.Add(fp)
    for num, nname in padnets.items():
        pad = fp.FindPadByNumber(num)
        assert pad, f"{ref} has no pad {num}"
        pad.SetNet(nets[nname])
    return fp

# XIAO ESP32-S3 socket: two SMD 1x7 sockets, pin 1 at the back (y-),
# columns 17.78 mm apart. SMD-only pads stay clear of the bottom contacts.
XIAO_CX = 6.5
xl = place("Connector_PinSocket_2.54mm", "PinSocket_1x07_P2.54mm_Vertical_SMD_Pin1Left",
           "U2", XIAO_CX - 8.89, 0, 0,
           {"1": "MOD_A", "2": "MOD_INT", "3": "SDA_DEV", "4": "SCL_DEV",
            "5": "SDA_BAY", "6": "SCL_BAY", "7": "MOD_B"})
xr = place("Connector_PinSocket_2.54mm", "PinSocket_1x07_P2.54mm_Vertical_SMD_Pin1Right",
           "U3", XIAO_CX + 8.89, 0, 0,
           {"1": "XIAO_5V", "2": "GND", "3": "+3V3"})
# Qwiic / STEMMA-QT, openings toward the front edge
j1 = place("Connector_JST", "JST_SH_SM04B-SRSS-TB_1x04-1MP_P1.00mm_Horizontal",
           "J1", -19.0, 9.2, 0,
           {"1": "GND", "2": "+3V3", "3": "SDA_DEV", "4": "SCL_DEV"})
j2 = place("Connector_JST", "JST_SH_SM04B-SRSS-TB_1x04-1MP_P1.00mm_Horizontal",
           "J2", -9.5, 9.2, 0,
           {"1": "GND", "2": "+3V3", "3": "SDA_DEV", "4": "SCL_DEV"})
# encoder / raw GPIO breakout header
place("Connector_PinHeader_2.54mm", "PinHeader_1x04_P2.54mm_Vertical",
      "J4", 25.3, 2.2, 0,
      {"1": "+3V3", "2": "GND", "3": "MOD_A", "4": "MOD_B"})
# bus-ownership jumpers (bridged = dumb adapter), 5 V feed (open)
place("Jumper", "SolderJumper-2_P1.3mm_Bridged_Pad1.0x1.5mm", "JP1",
      -8.0, -10.5, 0, {"1": "SDA_BAY", "2": "SDA_DEV"})
place("Jumper", "SolderJumper-2_P1.3mm_Bridged_Pad1.0x1.5mm", "JP2",
      -12.5, -10.5, 0, {"1": "SCL_BAY", "2": "SCL_DEV"})
place("Jumper", "SolderJumper-2_P1.3mm_Open_Pad1.0x1.5mm", "JP3",
      23.0, -10.5, 0, {"1": "VBUS_FUSED", "2": "XIAO_5V"})
# decoupling + MOD_INT presence strap
place("Capacitor_SMD", "C_0603_1608Metric", "C1", -14.0, 1.5, 90,
      {"1": "+3V3", "2": "GND"})
place("Capacitor_SMD", "C_0603_1608Metric", "C2", -11.5, 1.5, 90,
      {"1": "+3V3", "2": "GND"})
place("Resistor_SMD", "R_0603_1608Metric", "R1", 10.0, -1.2, 90,
      {"1": "MOD_INT", "2": "GND"})

# No GND pours: freerouting routes GND as tracks (zones + thermal-spoke
# rules kept causing starved thermals / islands on this dense little board).

# ------------------------------------------------------------- net classes
ds = board.GetDesignSettings()
ds.m_TrackMinWidth = FromMM(0.2)
ds.m_ViasMinSize = FromMM(0.5)
ds.m_MinThroughDrill = FromMM(0.3)
nc = board.GetAllNetClasses()["Default"]
nc.SetTrackWidth(FromMM(0.25))
nc.SetViaDiameter(FromMM(0.6))
nc.SetViaDrill(FromMM(0.3))
nc.SetClearance(FromMM(0.15))

pcbnew.SaveBoard(OUT, board)
print(f"wrote {OUT}")
print(f"{len(board.GetPads())} pads, {len(NET_NAMES)} nets")

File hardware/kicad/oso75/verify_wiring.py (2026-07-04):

"""Electrical verification of oso75.kicad_pcb against the documented wiring:
  - every switch/diode connection in oso75_matrix_netlist.csv
  - every ROW/COL net lands on the correct physical ESP32-S3-WROOM-1U pad
    for the GPIO assigned in qmk keyboard.json
  - J3 module bay pads 1-10 carry the nets from oso75_circuit.md
  - bay signals reach the documented U1 GPIOs (I2C 41/42, MOD_A/B 39/40,
    MOD_INT 47, ESP_EN -> EN)
  - zero unconnected items in the routed board
"""
import csv, json, sys
import pcbnew

ROOT = "/Users/vamshikrishnaramasamy/CodeProjects/OSO Keyboard"
board = pcbnew.LoadBoard(f"{ROOT}/hardware/kicad/oso75/oso75.kicad_pcb")

# ref -> {pad_number: net_name}
pads = {}
for fp in board.GetFootprints():
    ref = fp.GetReference()
    pads.setdefault(ref, {})
    for p in fp.Pads():
        if p.GetNumber():
            pads[ref][p.GetNumber()] = p.GetNetname()

fails = []
ok = 0
def check(cond, msg):
    global ok
    if cond: ok += 1
    else: fails.append(msg)

# ---- 1. switch matrix: every connection in the CSV exists in copper
with open(f"{ROOT}/hardware/pcb/oso75_matrix_netlist.csv") as f:
    rows = list(csv.DictReader(f))
check(len(rows) == 82, f"expected 82 matrix entries, got {len(rows)}")
for r in rows:
    sw, d = pads.get(r["switch_ref"], {}), pads.get(r["diode_ref"], {})
    check(sw.get("1") == r["switch_pin_1"],
          f'{r["switch_ref"]} pad1 = {sw.get("1")} want {r["switch_pin_1"]}')
    check(sw.get("2") == r["switch_pin_2"],
          f'{r["switch_ref"]} pad2 = {sw.get("2")} want {r["switch_pin_2"]}')
    # diode: pad 2 = anode (matrix convention here), pad 1 = cathode
    dnets = set(d.values())
    check(r["diode_anode"] in dnets and r["diode_cathode"] in dnets,
          f'{r["diode_ref"]} nets {dnets} want {r["diode_anode"]}+{r["diode_cathode"]}')

# ---- 2. ROW/COL nets land on the right physical WROOM-1U pad
# ESP32-S3-WROOM-1(U) module pinout: pad number -> GPIO name
WROOM = {3:"EN",4:"GPIO4",5:"GPIO5",6:"GPIO6",7:"GPIO7",8:"GPIO15",9:"GPIO16",
         10:"GPIO17",11:"GPIO18",12:"GPIO8",13:"GPIO19",14:"GPIO20",15:"GPIO3",
         16:"GPIO46",17:"GPIO9",18:"GPIO10",19:"GPIO11",20:"GPIO12",21:"GPIO13",
         22:"GPIO14",23:"GPIO21",24:"GPIO47",25:"GPIO48",26:"GPIO45",27:"GPIO0",
         28:"GPIO35",29:"GPIO36",30:"GPIO37",31:"GPIO38",32:"GPIO39",33:"GPIO40",
         34:"GPIO41",35:"GPIO42",36:"GPIO44",37:"GPIO43",38:"GPIO2",39:"GPIO1"}
gpio_net = {WROOM[int(n)]: net for n, net in pads["U1"].items()
            if n.isdigit() and int(n) in WROOM}

kb = json.load(open(f"{ROOT}/qmk/keyboards/oso/oso75/keyboard.json"))
for i, g in enumerate(kb["matrix_pins"]["rows"]):
    check(gpio_net.get(g) == f"ROW{i}", f"U1 {g} = {gpio_net.get(g)} want ROW{i}")
for i, g in enumerate(kb["matrix_pins"]["cols"]):
    check(gpio_net.get(g) == f"COL{i}", f"U1 {g} = {gpio_net.get(g)} want COL{i}")

# ---- 3. J3 module bay pinout per oso75_circuit.md
J3_EXPECT = {1:"GND",2:"+3V3",3:"VBUS_FUSED",4:"I2C_SDA",5:"I2C_SCL",
             6:"MOD_A",7:"MOD_B",8:"MOD_INT",9:"ESP_EN",10:"GND"}
for n, want in J3_EXPECT.items():
    got = pads.get("J3", {}).get(str(n))
    check(got == want, f"J3 pad {n} = {got} want {want}")

# ---- 4. bay signals reach the documented ESP32 GPIOs
for g, want in [("GPIO41","I2C_SDA"),("GPIO42","I2C_SCL"),("GPIO39","MOD_A"),
                ("GPIO40","MOD_B"),("GPIO47","MOD_INT"),("EN","ESP_EN")]:
    check(gpio_net.get(g) == want, f"U1 {g} = {gpio_net.get(g)} want {want}")
# USB pins must NOT be in the matrix
for g in ("GPIO19", "GPIO20"):
    n = gpio_net.get(g, "")
    check(not n.startswith(("ROW","COL")), f"U1 {g} used by matrix net {n}")

# ---- 5. fully routed: no unconnected items
board.BuildConnectivity()
unrouted = board.GetConnectivity().GetUnconnectedCount(True)
check(unrouted == 0, f"{unrouted} unconnected items remain")

print(f"PASS {ok} checks" if not fails else f"{ok} ok, {len(fails)} FAILED:")
for m in fails:
    print("  FAIL:", m)
sys.exit(1 if fails else 0)

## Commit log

2026-06-08 Initial OSO keyboard hardware project
    [oso75.kicad_pcb, oso75.kicad_sch, oso75_case_plate.scad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]
2026-06-08 Improve 75 percent CAD model
    [oso75_case_plate.scad]
2026-06-09 Fix CAD to read as keyboard layout
    [oso75_case_plate.scad]
2026-06-09 Add USB-C receptacle cutout to CAD
    [oso75_case_plate.scad, oso75_case_plate.stl]
2026-06-09 Add hot-swappable OSO module bay
    [oso75_case_plate.scad, oso75_case_plate.stl, oso75_components.csv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]
2026-06-09 Improve CAD viewer rotation controls
2026-06-09 Move OSO module bay onto compact tab
    [oso75_case_plate.scad, oso75_case_plate.stl]
2026-06-09 Make OSO module bay flush with keyboard outline
    [oso75_case_plate.scad, oso75_case_plate.stl]
2026-06-09 Update PCB for flush OSO module bay
    [oso75.kicad_pcb, oso75_case_plate.scad, oso75_components.csv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]
2026-07-04 Prepare OSO75 hardware review package
    [STALE-MIRRORED-DO-NOT-ORDER-oso75_order_ready_pos.csv, oso75-B_Cu.gbl, oso75-B_Mask.gbs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]
2026-07-05 Add reviewer BOM with purchase links
    [bom.csv]
